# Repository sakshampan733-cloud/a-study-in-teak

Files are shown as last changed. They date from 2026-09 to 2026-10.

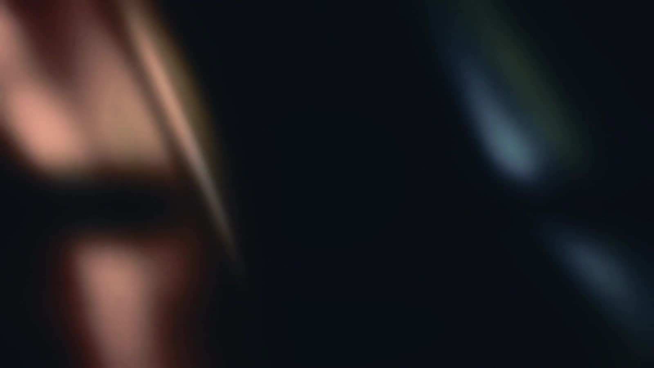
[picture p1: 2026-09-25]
v2/media/hero-poster.jpg

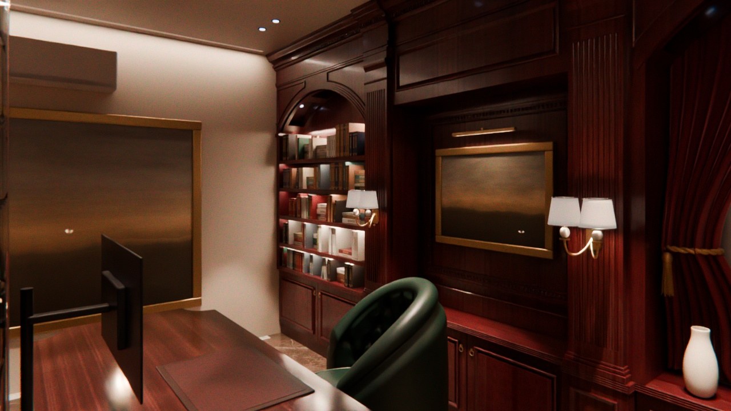
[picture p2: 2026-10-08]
v2/media/room-film-poster.jpg

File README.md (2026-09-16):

# A Study in Teak

Working brief for the interior of one room — neoclassical, late-1940s British, in teak.
A static website: open `index.html`, or serve the folder and browse by section.

```bash
python3 -m http.server 4178
```

## What's where

| Path | What it holds |
|---|---|
| `data.js` | All written content: materials, each piece of furniture, doors, lighting and switch plan |
| `drawings/` | Parametric drawing sheets (desk, door) and the hidden-line 3D renderer — change the numbers at the top of a file and every view redraws |
| `cad/` | Editable CAD exports: `*-model.dxf` true size in mm, `*-sheet.dxf` the A3 sheet, `*.svg` |
| `assets/refs/` | Reference photos |
| `tools/` | Scripts that rebuild the CAD files |

## Adding your own CAD drawings

Drop `.dxf`, `.pdf` or image files into `plans/`, then run `tools/build-cad.sh`. They appear on the Overview page.
DWG can't be read directly — in AutoCAD use **Save As → DXF**, or **Export / Plot → PDF**.

## Rebuilding the CAD files

After changing a drawing:

```bash
python3 -m venv tools/.venv && tools/.venv/bin/pip install ezdxf svgelements shapely pymupdf   # first time only
tools/build-cad.sh
```

Status: rough work. Sizes and details are finalised with the family before anything is made.

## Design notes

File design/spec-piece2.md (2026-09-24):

# Piece 2 — navigation and motion, read from the reference's code

Source: `design/ref-ciridae/site/` (index.html CSS, `marketingMotionRuntime-*.js`, `useMarketingRouteHead-*.js`,
`MarketingShell-*.js`). Easing everywhere: `--smooth: cubic-bezier(.76, 0, .24, 1)`.

## Smooth scroll
- `new Lenis({ duration: 1.4, smoothWheel: true, wheelMultiplier: 1.6 })`, wired to `ScrollTrigger.update`.
- Stopped while the menu is open (`body.burger-open`), restarted on close.

## Nav bar (`.nav_body`)
- Grid of two columns, padding 8 × 24, 4 px radius.
- Frosted: `background: color-mix(in srgb, currentColor, transparent 75%)` (white 25%) + `backdrop-filter: blur(20px)`.
- Desktop (≥ 992 px): **at the top** it is transparent with no blur. **Scrolling down** it slides away
  (`translateY(-140%)`). **Scrolling up** it returns, frosted. Transform 0.8 s smooth; colour/bg/blur 0.4 s.
- Phone/tablet: frosted even at the top.
- Over light (Bone) sections the nav turns black (`.is--dark`).

## Pills (`.btn`, `.nav_burger`)
- 1 px border, full radius, min-width 140, padding 10 × 18, label shifted `translateY(7%)`.
- **Hover is a glow, not a fill:** a `::before` with `outline: 3px solid`, `box-shadow: 0 0 20px 10px, inset 0 0 20px 10px`
  (currentColor) fading to opacity 0.12 over 0.2 s.
- Labels re-scramble on hover, lowercase `abcdefghijklmnopqrstuvwxyz`.

## Menu (`.burger`)
- Full-screen fixed overlay, `#272a2a`, z 9. Opens: opacity 0→1 over 0.8 s smooth; closes over 0.6 s.
- Content: small mark at top, links centred in a column (40 px, weight 400, line-height 1, gap 10 px),
  a footer row at the bottom (three columns).
- Links fade in 0.6 s each, staggered `delay = 0.2 s + i × 0.1 s`; the footer row fades in at 0.4 s.
- Hovering a link: the others dim to 70%; the hovered one gets a blurred (10 px) ghost copy at 30%.
- Burger button: `MENU` swaps to `CLOSE`; the two 25 px lines rotate ±45° and shrink to 50% width
  (0.6 s smooth); the button's border fades out; the left pill fades and disables.
- Escape closes; focus moves to the first link on open and back to the button on close.

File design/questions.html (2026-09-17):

# A Study in Teak — questions to fill in

One room: study, bedroom, dressing, bathroom. Tick one box per question unless it says otherwise; write in the blanks where asked. Anything already decided is marked [set] so it can be checked rather than chosen.

## 1 · The room itself

1.1 Room size, wall to wall — please measure

- Width ft Length ft Ceiling height ft

1.2 Study wall (bookcase wall) width

- 16 ft (as drawn)
- Other:

1.3 Right wall — study wall to the bathroom door opening

- 14 ft 6 in (as drawn)
- Other:

Also: wall past the door to the corner = 2 ft? ☐ yes ☐ other

1.4 Where exactly is the main door (D1) on the left wall?

- Distance from the bed-end corner:
- It is on the entrance wall, not the left wall

1.5 Study window — size and position

- Width Height Sill from floor From right corner

## 2 · Materials

2.1 Veneer — the one veneer used across the room

- Dark reddish teak, straight grain
- Walnut, straight grain
- Dark oak
- Other:

2.2 Veneer cut

- Quarter cut / straight
- Crown cut
- Book-matched
- Slip-matched

2.3 Polish on panelling, doors and trim

- Satin PU
- Semi-gloss PU
- Matte PU
- Melamine

2.4 Polish on the desk

- Matte PU
- Oil / wax finish
- Same as panelling
- Other:

2.5 Wall paint — warm cream [set]. Which shade?

- Warm cream
- Soft ivory
- Warm off-white
- Sample to be chosen on site

2.6 Brass / gold finish on handles

- Polished brass
- Antique / aged brass
- Brushed brass
- Other:

## 3 · Study — desk, shelf wall, curtains

3.1 Desk size 7 ft 6 in × 3 ft, height 750 mm [set] — confirm?

- Yes, as drawn
- Change:

3.2 Desk pedestals

- Drawers both sides
- Doors both sides
- Drawers one side, door the other
- Decide later

3.3 Shelf unit depth 11 in (280 mm) [set] — confirm?

- Yes
- Other:

3.4 Cupboards under the shelf: 2 ft high [set], doors

- Two doors per bay, as drawn
- Drawers instead
- Mix — say which:
- Decide later

3.5 Painting in the centre panel

- Yes, leave the panel for a painting
- No painting — panel stays plain
- Mirror instead
- Decide later

3.6 Curtain heading and track

- Ceiling track, recessed
- Ceiling track, surface
- Rod with brackets
- Decide later

3.7 Curtain length

- Just touching the floor
- Breaking / pooling on the floor
- Sill length
- Other:

## 4 · Left and right walls

4.1 Right wall — option C [set]: 5 panels, lamps in 1, 3 and 5. Confirm?

- Yes
- Change lamps to:

4.2 Right wall lamps — how many

- Three (as drawn)
- Two
- None
- Other:

4.3 Left wall treatment

- Same panel moulding as the right wall
- Teak panelling to the door head
- Plain painted wall
- Other / undecided:

## 5 · Bedroom

5.1 Bed wall in parchment [set] — how is it made?

- Large panels with hairline joints
- Seamless (no joints)
- Real parchment / vellum
- Parchment-effect finish

5.2 How far does the parchment go?

- Whole wall, floor to ceiling
- Behind the bed only
- Wall plus a return
- Other:

5.3 Bed size

- King
- Queen
- 6 ft 6 in × 6 ft 6 in
- Other:

5.4 Bed base / frame

- Teak
- Wrapped in leather
- Fabric upholstered
- Decide later

5.5 Storage in the bed

- Hydraulic lift-up
- Drawers
- None
- Decide later

5.6 Bedside

- Wide wooden ledges, built in
- Free-standing tables
- Drawers built into the bed back
- Decide later

5.7 TV — where does it go?

- On the partition, facing the bed
- On a wall — which:
- No TV
- Decide later

5.8 TV unit / side drawers

- Drawer unit under the TV
- Side drawers only
- Both
- Decide later

5.9 TV screen size

- 55 in
- 65 in
- 75 in
- Other:

## 6 · Partition

6.1 Length and gaps — please measure so they add up to the room width

- Partition ft Gap one end ft Gap other end ft

6.2 Material — wood only [set]. How is it built?

- Teak veneer both sides
- Veneer one side, parchment the other
- Veneer with parchment drawer fronts
- Other:

6.3 How much moulding?

- A little — slim panel frames
- Full panelling, like the study wall
- Plain, no moulding
- Decide later

6.4 Base where it meets the floor

- Teak plinth
- Shadow gap, wood runs to the floor
- Marble skirting to match the walls
- Decide later

6.5 Does it hold anything?

- Drawers on the bed side
- Shelves on the study side
- Both
- Nothing — it is a screen

## 7 · Dressing

7.1 Wardrobe fronts

- Blackened steel frames with lit white glass (as drawn)
- Teak veneer
- Parchment
- Decide later

7.2 Wardrobe wall — which wall, and how wide?

- Wall: Width Depth (600 mm standard)

7.3 Inside the wardrobe

- Mostly hanging
- Half hanging, half drawers
- Mostly drawers and shelves
- Decide later

7.4 Dressing mirror

- Free-standing three-panel screen (as the reference)
- Fixed to a wall
- Inside a wardrobe door
- Decide later

7.5 Dressing ceiling

- Barrel vault, as the bedroom
- Flat with cove
- Flat, plain
- Decide later

## 8 · Bathroom

8.1 Size — please measure

- Width Length Ceiling height

8.2 Painted ceiling linework [set] — the pattern

- Copy the reference photo
- Design a new motif
- Simple border only
- Decide later

8.3 Vanity

- Teak veneer, moisture-resistant core
- Stone / solid surface
- Painted
- Decide later

8.4 Vanity counter

- Beige-gold marble, same as the floor
- A contrasting stone:
- Solid surface
- Decide later

8.5 Basin and tap

- Counter-top basin
- Under-counter basin
- Wall-mounted tap
- Deck-mounted tap

## 9 · Doors and hardware

9.1 Three doors, one design [set] — leaf thickness

- 35 mm
- 45 mm
- Other:
- Decide later

9.2 The panel detail (shaped bead, corner roundels)

- Carved into the solid
- Applied moulding
- Simplified — plain panels
- Decide later

9.3 Door hardware

- Knobs
- Lever handles
- Brass
- Antique brass

9.4 Which way does each door swing? (D1 main, D2 and D3)

- D1 D2 D3

## 10 · Lighting and services

10.1 Bulb colour through the room

- 2700 K warm
- 3000 K
- 4000 K natural white (as bought)
- Mixed — say where:

10.2 Cove lights — all on one dimmer [set]. Confirm?

- Yes
- Change:

10.3 Reading lights at the bed

- Recessed slots in the wall
- Wall lamps
- Table lamps
- Decide later

10.4 Where do the switch boards go?

- List the locations:

10.5 Sockets needed at the desk, bed and TV

- Desk Bed TV

10.6 Air conditioning — position and type

- Wall split — where:
- Cassette in the ceiling
- Ducted
- Already installed

Anything unclear or wrongly assumed — write it in the margin. Sizes matter most: the room, the right wall, the partition and the bathroom.

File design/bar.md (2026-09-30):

# Bar — ciridae.com, to the pixel, for A Study in Teak

Gold standard, saved locally: `design/ref-ciridae/site/` (every file the browser loads, incl. the hero
video), `ciridae.mhtml`, `full-page.png`, section frames, and the first-load recorded at 33 fps
(`load-ciridae/load.mp4`). Numbers below are read from their source (`_site-*.js`, the motion runtime)
and measured off the live page at 1440 × 900. Every line is checkable on a render or a filmstrip.
Last round's bar is kept as `bar-round1.md`.

1. **The entrance, to the millisecond.** Black `#0b0b0b` and nothing else for the first 225 ms. The mark
   fades 0→1 over 0.75 s from 0.225 s while its blur runs 20 px→0 over 1.65 s, so it is fully sharp at
   ~1.9 s. The five hero texts (wordmark, two edge labels, the CTA's lines) scramble in A–Z letter by
   letter — 0.3 s per character, 7.5 ms stagger, left→right, fading in as they resolve — the first 0.2 s
   after the mark starts, each next 0.1 s later. The background video starts at 1.875 s; a curtain
   lifts over 0.6 s (power1) and the nav fades in with it. Entrance complete ≈ 3.2 s.
   *Filmstrip check:* 300 ms black · 900 ms a soft blurred mark · 1.9 s sharp mark, text resolving ·
   3.2 s video full-bleed, nav present.

2. **Void, one flip.** Page `#0b0b0b`; panels `#272a2a` at 10 px radius; exactly one Bone `#edebe7`
   full-width band per page. No box-shadow, glow or gradient fill anywhere — the only softening is
   backdrop blur: 40–50 px on the footer, a frosted veil on the stacked cards.

3. **Three registers, one weight.** Everything is weight 400. Headlines: condensed uppercase, 32 px,
   line-height 1.05, −0.02 em. Hero labels and CTA: grotesk uppercase 16 px, −0.02 em. Eyebrows, nav and
   data: mono uppercase 14 px, −0.02 em; card numbers mono 11 px. Prose: grotesk 14 px / 1.4, sentence
   case, ≤ 50 ch. Nothing larger than 32 px except the hero wordmark.

4. **Nav is two labels in outlines.** Fixed, text baseline ~31 px from the top, 67 px in from each edge:
   left action, right `MENU`, 14 px mono uppercase inside 1 px pill outlines, transparent fill. `MENU`
   opens a full-screen `#272a2a` overlay with the links in large condensed uppercase, centred.

5. **Moving media, never a static hero.** The hero is a full-bleed looping video: heavily defocused,
   warm-against-cool light, no hard edge and no recognisable object, ~8 s, seamless. Mark + wordmark
   dead centre; two 16 px labels pinned to the far left and far right at the vertical centre; a
   three-line CTA centred ~120 px above the bottom. Section imagery is dark and atmospheric — never a
   thumbnail grid.

6. **Text decodes, sections rise, scroll glides.** Every eyebrow and headline scrambles into place as it
   enters view (0.3 s per character, 10–20 ms stagger, left→right). Section media: content yPercent
   50→0 (expo.in), image scale 1.4→1 with yPercent −20→0 (power1). Default tween 0.4 s power2. Scroll
   is inertial (lerp-smoothed), never native-jumpy.

7. **The set pieces.** One scroll-pinned full-bleed backdrop with numbered frosted cards rising and
   stacking over it; one row of cards where the hovered card grows to ~2× width over 0.6 s; one Bone
   band with a logo/marquee strip; a footer under 40–50 px backdrop blur.

## Piece 1, round 15 on — the hero loop by the numbers (30.09)

The owner restarted the frozen loop against the **saved 23 Sep version** (the live site has since been
redesigned; it is not the bar). Entrance timing and layout passed brief and system in rounds 8–12 and
are regression checks only. What failed every craft round is the loop's *feel*. These are measured off
`site/ciridae.com/marketing/media/hero_web.mp4` (1 fps, 480 px wide) and are checkable on ours the same way:

8. **Mostly dark.** 60–72% of the frame below luma 20; mean luma 20–28. Lit area small: warm (r > b) 4–8%
   of the frame, cool (b > r) 3–6%. Shadows near-neutral, faintly blue (≈ 7, 11, 14). No green cast (0%).
9. **Mixed focus, not one blur.** In every second at least one form is only softly defocused — a curved
   edge readable as glass or metal, a surface you could name the shape of — in front of forms that are
   fully dissolved. Edge density (gradient > 18) varies 0.3–1.0% second to second; a flat 0.4% is fog.
10. **Glints.** At least once per loop a small near-white specular (luma > 225, 0.1–0.6% of the frame,
    cream not pure white) catches on a curved surface, then passes. Never a disc, never a light bulb.
11. **Forms, not shapes.** The light sits on 3–5 translucent objects — cylinders, shards, lips of glass —
    lit copper from one side and steel-blue from the other, turning slowly so their highlights travel.
    No ring or arc spanning half the frame; nothing reads as a bubble, orb, lamp, room or face.
12. **Pace and loop.** 8–9 s, 24 fps, 1600 × 850. Composition changes by 10–16 luma levels a second
    (forms enter, cross, leave), with the loop point invisible: no jump, no crossfade ghost.

## Accepted deltas — a critic must not fail on these

- **Content is ours.** Room names, copy, drawings, photos: from `data.js`, never theirs.
- **Media is ours.** Every video and image is generated for this room (Higgsfield). Match their
  *treatment* — blur level, grade, pacing, motion — never their pixels. The objects in ours may be the
  room's own (teak, brass, glass) as long as they read as abstract forms, per 11.
- **Typefaces**, until decided: Pragmatica / Pragmatica Cond are licensed commercial faces. Until the
  owner buys them, the closest free substitutes stand in; judge metrics (size, tracking, case, weight),
  not letterforms.

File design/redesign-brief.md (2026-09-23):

# Redesign brief — Ciridae, to the last pixel

Gathered 23.09.2026, ahead of the redesign. Everything we have, and what's still missing.

## The reference

- **Site:** https://www.ciridae.com — "Ciridae — AI Transformation"
- **Refero style extract:** https://styles.refero.design/style/a1b78a21-a304-482b-8ce5-f612d95d44fe
- **Your source files** (still in ~/Downloads, copies here in `design/`):
  `DESIGN-4.md` → `design-system.md`, `tokens-4.json` → `tokens.json`,
  `variables-4.css` → `variables.css`, `theme-4.css`
- **The bar** the first pass was judged against: `design/bar.md` (7 checkable rules)
- **Fresh captures of the live site:** `design/ref-ciridae/` — 49 frames at 1440 × 900,
  recorded in Chrome with the video playing (kept on this Mac, not in git)

## Where the first pass stopped (17.09)

Design loop, 4 rounds, paused. Brief checks passed for navigation and room pages;
system and craft critics still failing on every piece (`design/progress.js`).
What shipped: void palette, condensed type, ghost pills, rust accent, blur-in loader,
decode headings, card-stack, expanding row, menu overlay. What was substituted:
**every moving image was replaced by a blurred still**, because we had nothing to make video with.

## The page, section by section (live, 23.09)

| # | Section | What moves | What we need |
|---|---|---|---|
| 0 | Hero — mark + wordmark, two edge labels, CTA line | **Background video** `hero_web.mp4`, 1600 × 850, 8.3 s loop, muted: slow, heavily defocused shapes in warm copper and cold blue-grey | **Higgsfield:** an 8 s seamless loop of the room — teak, brass sconce glow, lamplight — out of focus, drifting |
| — | Loader (0–2.6 s) | Mark + wordmark blur into focus on black (~0.9 s); edge labels decode letter by letter; video fades up behind by ~2.6 s | Code — already built, retune timings |
| 1 | "Backed by" — light Bone strip, three logos | Static | Code |
| 2 | "AI transformation" headline over a **WebGL2 canvas** | The mark rendered as chrome stars with a soft glow and a mirrored reflection below; slow shimmer | **Code (WebGL)** or a **Higgsfield** render of our mark in brass |
| 3 | Pinned full-bleed night landscape (mountain lake, star field, shooting star) with three frosted cards rising and stacking over it, each with its own star-constellation glyph | Scroll-pinned stack; glyphs | **Higgsfield:** one atmospheric backdrop of ours, same mood. Glyphs are code |
| 4 | "A new era" — centred prose on black | Decode on enter | Code |
| 5 | "Systems, not tools" — expanding card row, 4 cards | Hovered card grows to ~2× over 0.6 s | **Higgsfield:** four rich macro textures in their style (theirs: marbled fluid, dark forest, cloud, copper). Ours: teak grain, veined marble, leaded glass, brass |
| 6 | "Our team" — light Bone section, logo marquee | Marquee scroll | Code |
| 7 | Testimonials — charcoal cards, 1 / 6 carousel | Slide | Code |
| — | Menu | Full-screen charcoal overlay; links decode in | Code — built |

## The Higgsfield shopping list

1. **Hero loop** — 8 s, seamless, 16:9 or wider, generated from our own reference photos, then defocused.
2. **Pinned backdrop** — one still or slow video: the room's mood at night.
3. **Four textures** for the expanding row.
4. *(optional)* **The mark in brass** — if we render it rather than build it in WebGL.

Everything else is code and doesn't need credits.

## Still open before we start

- Which of our pages map onto which Ciridae sections (the overview is the obvious home page).
- The fonts: Ciridae's are paid; we used Barlow Condensed / Inter / Roboto Mono. Buy the real ones, or keep the substitutes?

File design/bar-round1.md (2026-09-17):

# Bar — Ciridae (ciridae.com), recreated for A Study in Teak

Reference: https://www.ciridae.com · Refero extract: design/design-system.md
Every line is checkable by looking at a render (screenshot or filmstrip).

1. **Void, one flip.** Canvas is #0b0b0b; cards/panels #272a2a with 10px radius; exactly one Bone (#edebe7) full-width section per page; no box-shadow, glow or gradient fill anywhere.
2. **Three registers, one weight.** Labels and headlines are condensed UPPERCASE at 14 / 20 / 32px (weight 400, −0.02em); prose is a grotesk at 15–24px sentence case; monospace 11–14px UPPERCASE appears only for system data (dates, codes, sizes, statuses, the top ticker). Nothing is heavier than 400.
3. **Ghost pills and one ember.** Every control is transparent with a 1px border and full pill radius; numbered markers are "01"-style mono pills with a #cecece border. Ember #cc6437 appears as hairline or small text only — never a fill — at most twice per viewport.
4. **Centred eyebrow → headline.** Each section opens with a centred 14px eyebrow above a 32px headline, with ≥80px vertical space between sections; content is centred inside a 1400px max width.
5. **Ambient imagery.** The hero is a full-viewport, heavily blurred photo (≥40px blur) with a centred mark + wordmark and two 14px labels pinned to the far left and far right edges; section/card photos are dark and atmospheric behind centred type, never illustrative thumbnails in a grid.
6. **Motion vocabulary.** Load begins with the mark blurring into focus on black; labels and headlines decode (random characters resolving left→right in ~600ms) as they enter view; all transitions use cubic-bezier(0.76, 0, 0.24, 1) at 400–800ms; a card row expands the hovered card to ~2× width over 600ms.
7. **Stacks and overlays.** At least one scroll section pins a full-bleed image while numbered cards stack over it; navigation is two fixed ghost pills (left action, right MENU) and MENU opens a full-screen #272a2a overlay with large condensed links.

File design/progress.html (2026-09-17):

# A Study in Teak × Ciridae — design loop

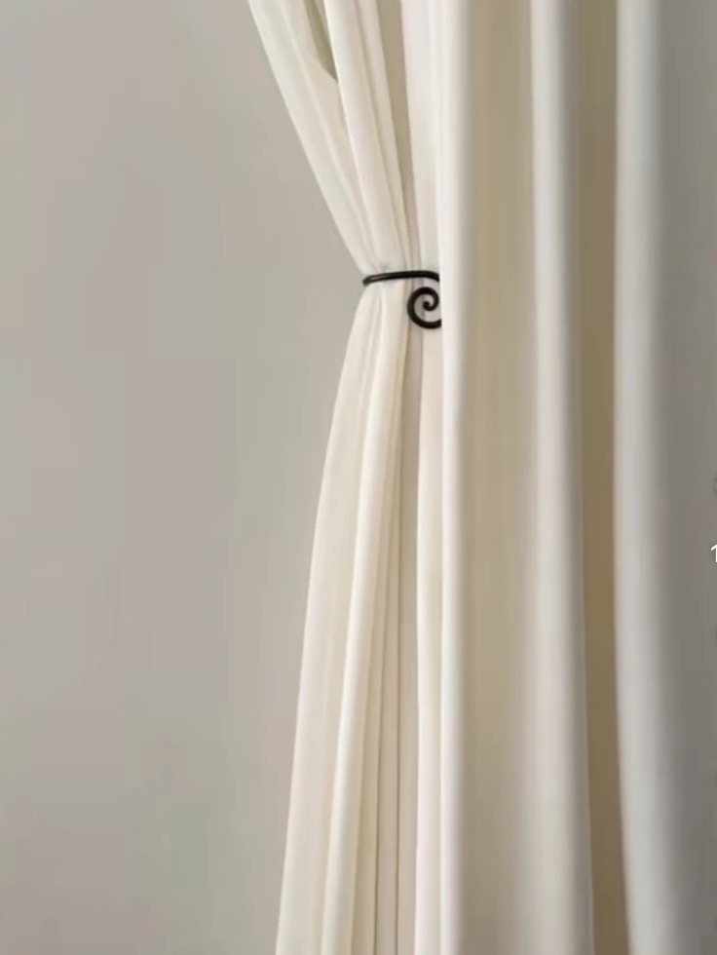
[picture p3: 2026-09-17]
assets/refs/curtain-ref-1-volute-tieback.jpg

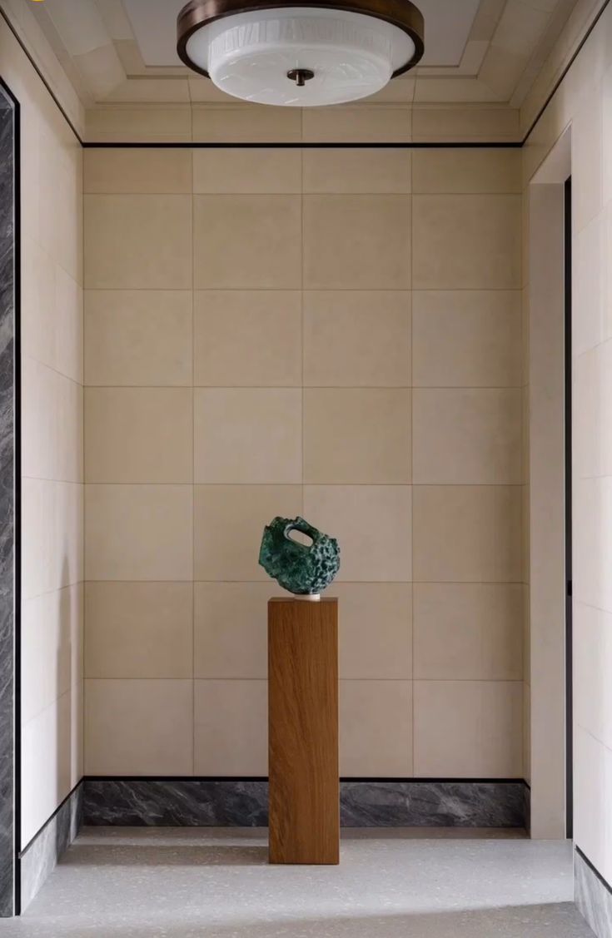
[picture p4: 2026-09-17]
assets/refs/bedwall-ref-2-parchment-entry-niche.jpg

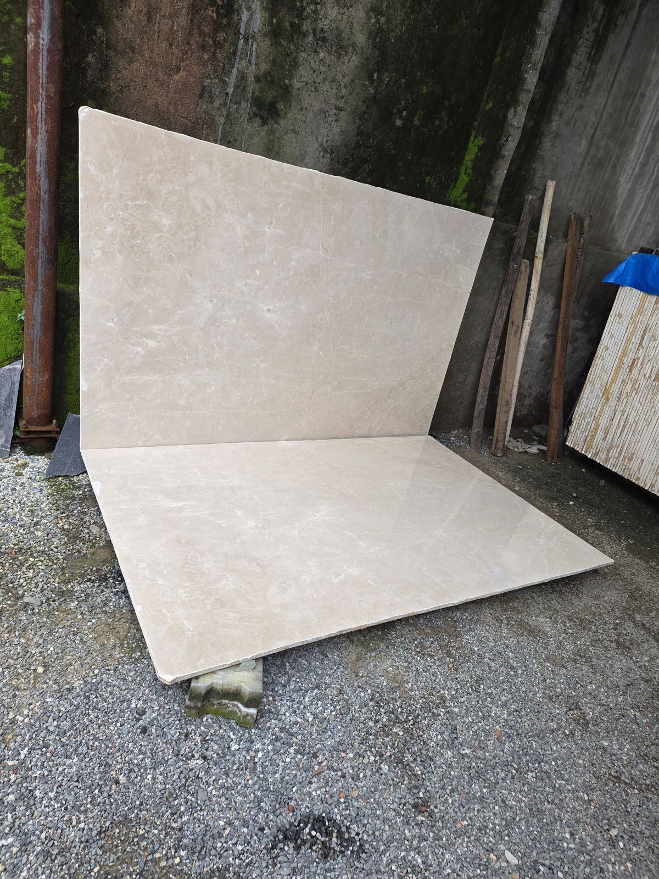
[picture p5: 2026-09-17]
assets/refs/stone-ref-3-beige-gold-bathroom-marble.jpg

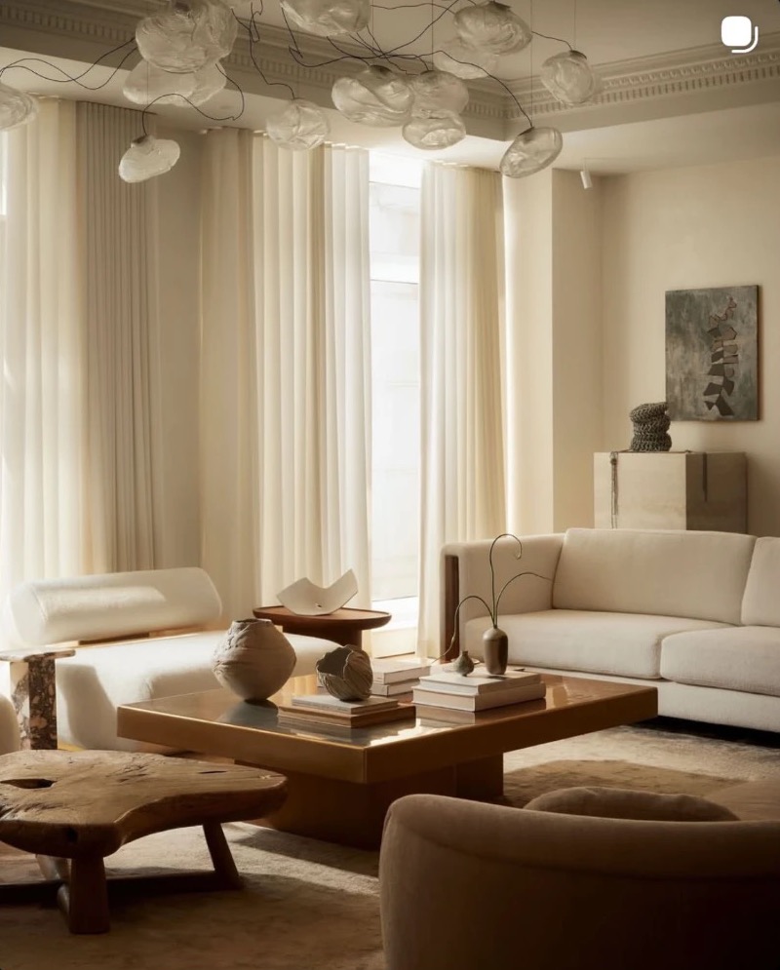
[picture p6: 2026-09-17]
assets/refs/paint-ref-1-warm-cream-room-sheer-curtains.jpg

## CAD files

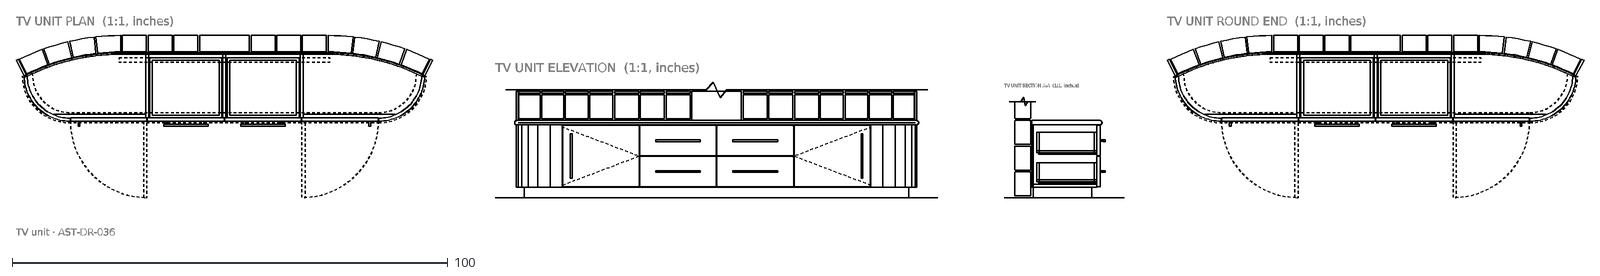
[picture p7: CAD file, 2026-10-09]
cad/tvunit-model.dxf
TV UNIT PLAN (1:1, inches)
TV UNIT ELEVATION (1:1, inches)
TV UNIT SECTION A-A (1:1, inches)
TV UNIT ROUND END (1:1, inches)
TV unit · AST-DR-036

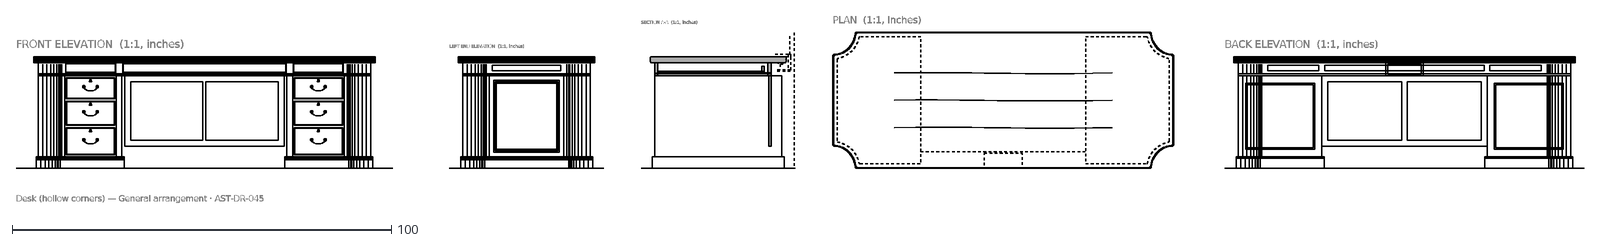
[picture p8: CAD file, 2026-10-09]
cad/desk-curved-model.dxf
FRONT ELEVATION (1:1, inches)
LEFT END ELEVATION (1:1, inches)
SECTION A-A (1:1, inches)
PLAN (1:1, inches)
BACK ELEVATION (1:1, inches)
Desk (hollow corners) — General arrangement · AST-DR-045

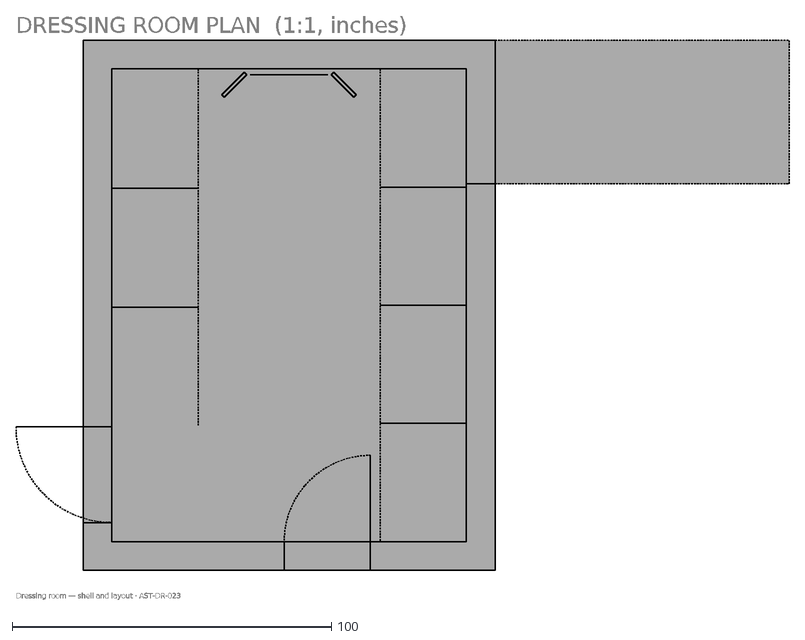
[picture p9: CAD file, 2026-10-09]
cad/dressingshell-model.dxf
DRESSING ROOM PLAN (1:1, inches)
Dressing room — shell and layout · AST-DR-023

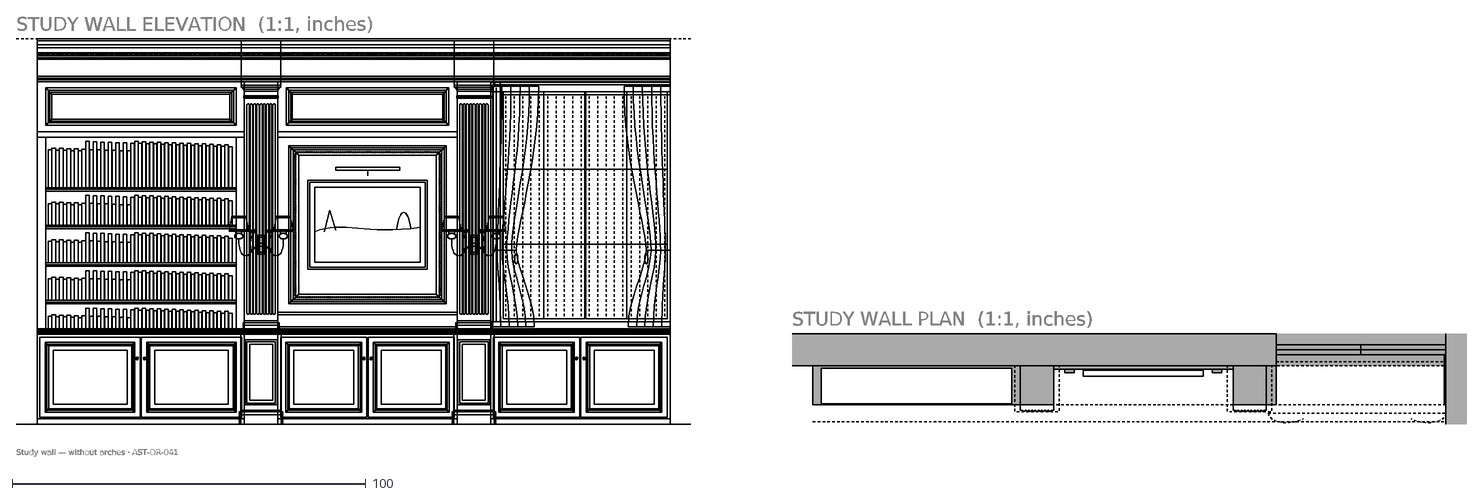
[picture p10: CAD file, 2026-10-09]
cad/studywall-flat-model.dxf
STUDY WALL ELEVATION (1:1, inches)
STUDY WALL PLAN (1:1, inches)
Study wall — without arches · AST-DR-041

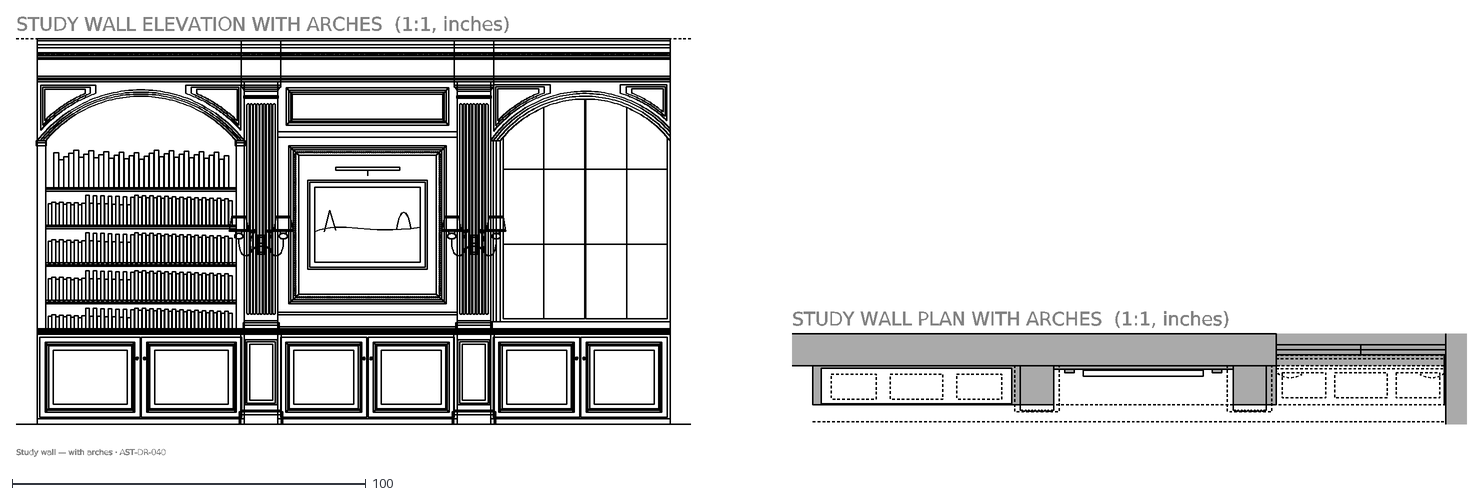
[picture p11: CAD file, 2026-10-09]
cad/studywall-arch-model.dxf
STUDY WALL ELEVATION WITH ARCHES (1:1, inches)
STUDY WALL PLAN WITH ARCHES (1:1, inches)
Study wall — with arches · AST-DR-040

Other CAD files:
cad/studywall-flat-sections-model.dxf
cad/studywall-details-sheet.dxf
cad/desk-curved-sheet.dxf
cad/roomshell-sheet.dxf
cad/sharedwall-sheet.dxf
cad/doorveneer-model.dxf
cad/desk-sheet.dxf
cad/sidetable-sheet.dxf
cad/vanity-c-sheet.dxf
cad/door-model.dxf
cad/doorveneer-sheet.dxf
cad/foldslide-sheet.dxf
cad/desk-square-3d-sheet.dxf
cad/architrave-model.dxf
cad/architrave-sheet.dxf
cad/bathroom-model.dxf
cad/bathroom-sheet.dxf
cad/bed-model.dxf
cad/bed-sheet.dxf
cad/bedframe-model.dxf
cad/bedframe-sheet.dxf
cad/bedwall-model.dxf
cad/bedwall-sheet.dxf
cad/casingb-model.dxf
cad/casingb-sheet.dxf
cad/desk-3d-sheet.dxf
cad/desk-curved-3d-sheet.dxf
cad/desk-curved-details-model.dxf
cad/desk-curved-details-sheet.dxf
cad/desk-details-model.dxf
cad/desk-details-sheet.dxf
cad/desk-model.dxf
cad/desk-plain-3d-sheet.dxf
cad/desk-plain-details-model.dxf
cad/desk-plain-details-sheet.dxf
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

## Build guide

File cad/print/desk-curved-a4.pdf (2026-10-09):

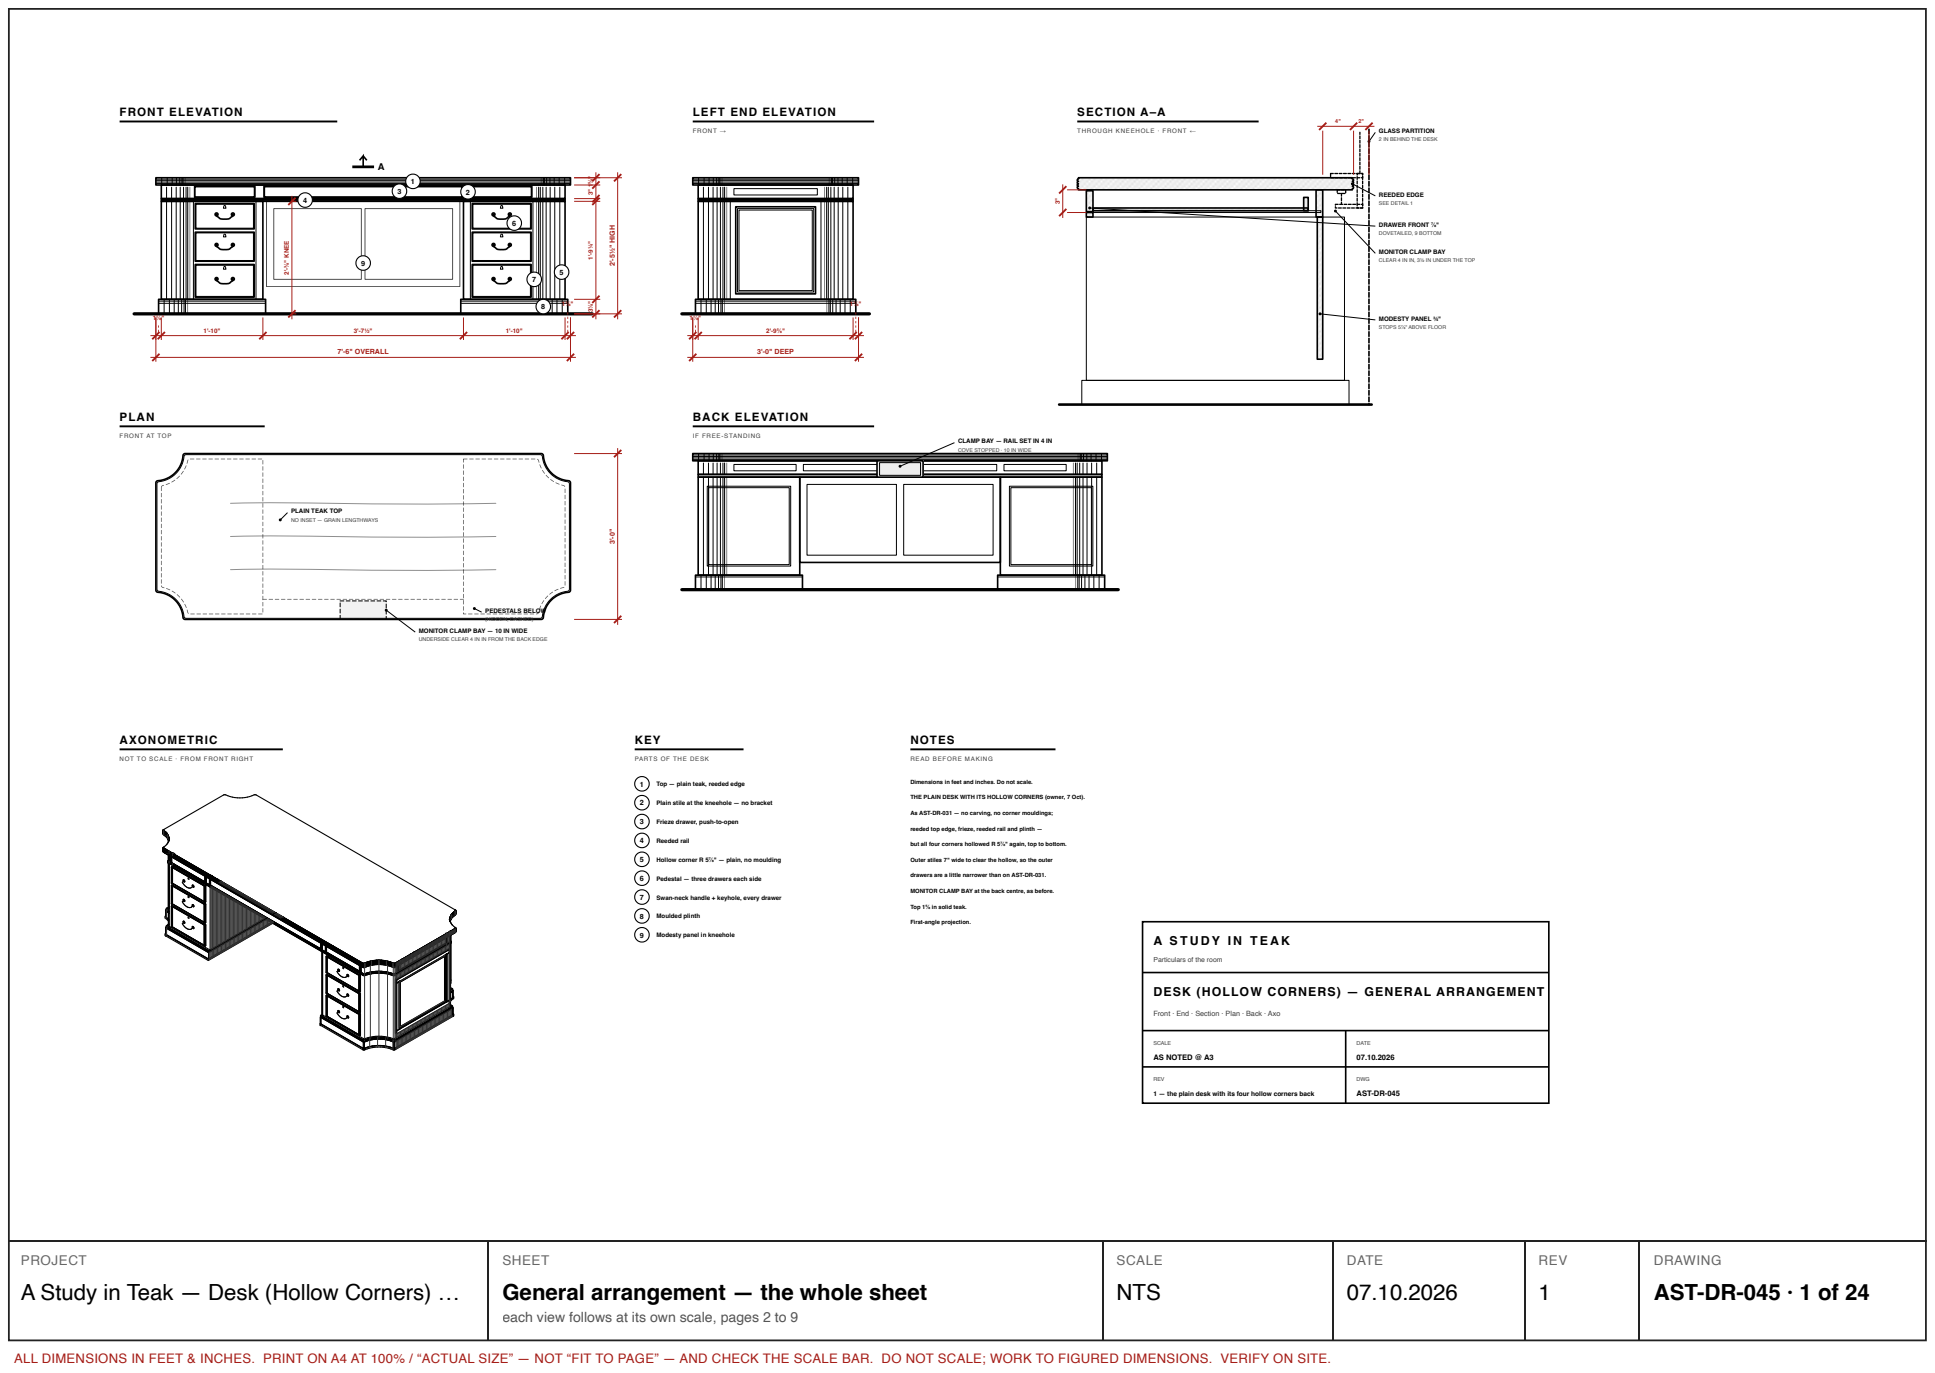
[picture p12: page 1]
FRONT ELEVATION; 7'-6" OVERALL; 2'-5½" HIGH; 2'-⅜" KNEE; FRONT →; 3'-0" DEEP; SECTION A–A; DRAWER FRONT ⅞"; DOVETAILED, 9 BOTTOM; GLASS PARTITION; REEDED EDGE; SEE DETAIL 1; PLAN; PEDESTALS BELOW; (HIDDEN, DASHED); BACK ELEVATION; AXONOMETRIC; KEY; 4 Reeded rail; 8 Moulded plinth; NOTES; SCALE; AS NOTED @ A3; DATE; REV; DWG; AST-DR-045; SCALE NTS; DATE 07.10.2026

LEFT END ELEVATION

THROUGH KNEEHOLE · FRONT ←

2 IN BEHIND THE DESK

MONITOR CLAMP BAY

CLEAR 4 IN IN, 3½ IN UNDER THE TOP

MODESTY PANEL ¾"
STOPS 5⅞" ABOVE FLOOR

FRONT AT TOP

IF FREE-STANDING

CLAMP BAY — RAIL SET IN 4 IN

COVE STOPPED · 10 IN WIDE

PLAIN TEAK TOP
NO INSET — GRAIN LENGTHWAYS

MONITOR CLAMP BAY — 10 IN WIDE

UNDERSIDE CLEAR 4 IN IN FROM THE BACK EDGE

NOT TO SCALE · FROM FRONT RIGHT

PARTS OF THE DESK

READ BEFORE MAKING

1 Top — plain teak, reeded edge

Dimensions in feet and inches. Do not scale.

2 Plain stile at the kneehole — no bracket

THE PLAIN DESK WITH ITS HOLLOW CORNERS (owner, 7 Oct).

As AST-DR-031 — no carving, no corner mouldings;

3 Frieze drawer, push-to-open

reeded top edge, frieze, reeded rail and plinth —

but all four corners hollowed R 5⅞" again, top to bottom.

5 Hollow corner R 5⅞" — plain, no moulding

Outer stiles 7" wide to clear the hollow, so the outer

6 Pedestal — three drawers each side

drawers are a little narrower than on AST-DR-031.

MONITOR CLAMP BAY at the back centre, as before.

7 Swan-neck handle + keyhole, every drawer

Top 1⅝ in solid teak.

First-angle projection.

9 Modesty panel in kneehole

Particulars of the room

DESK (HOLLOW CORNERS) — GENERAL ARRANGEMENT

Front · End · Section · Plan · Back · Axo

1 — the plain desk with its four hollow corners back

PROJECT
A Study in Teak — Desk (Hollow Corners) …

SHEET
General arrangement — the whole sheet

DRAWING
AST-DR-045 · 1 of 24

each view follows at its own scale, pages 2 to 9

ALL DIMENSIONS IN FEET & INCHES. PRINT ON A4 AT 100% / “ACTUAL SIZE” — NOT “FIT TO PAGE” — AND CHECK THE SCALE BAR. DO NOT SCALE; WORK TO FIGURED DIMENSIONS. VERIFY ON SITE.

# FRONT ELEVATION

A

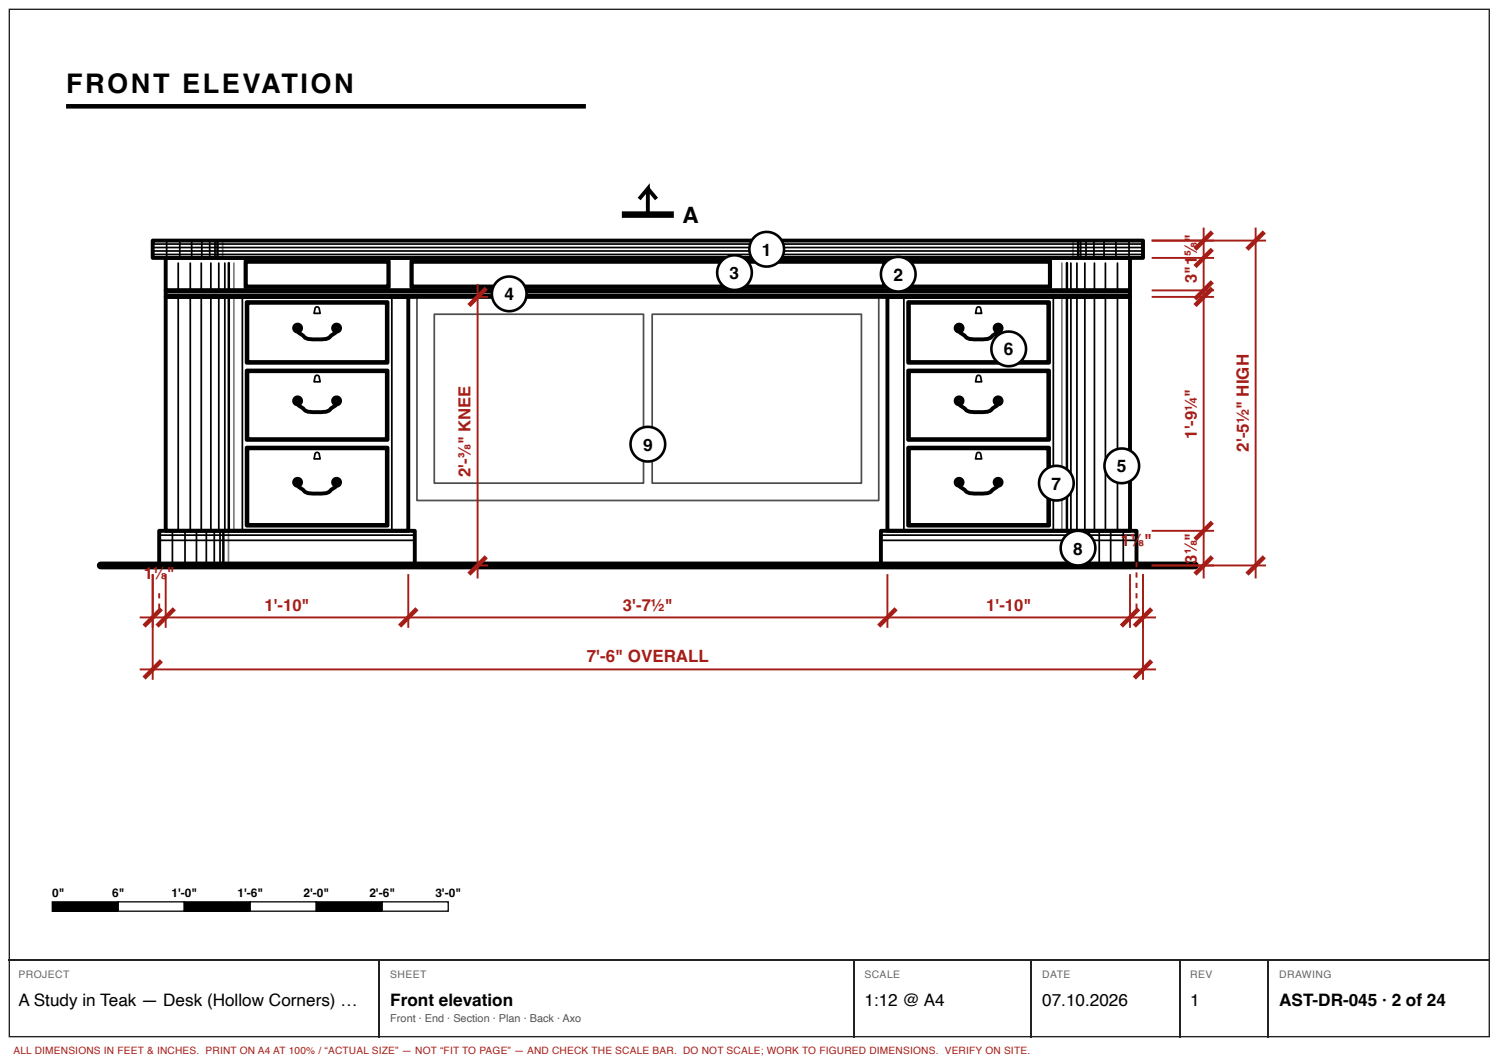
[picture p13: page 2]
7'-6" OVERALL; ½" HIG; Front elevation

AST-DR-045 · 2 of 24

Front · End · Section · Plan · Back · Axo

# LEFT END ELEVATION

# SCALE 1:10 @ A4 · FRONT →

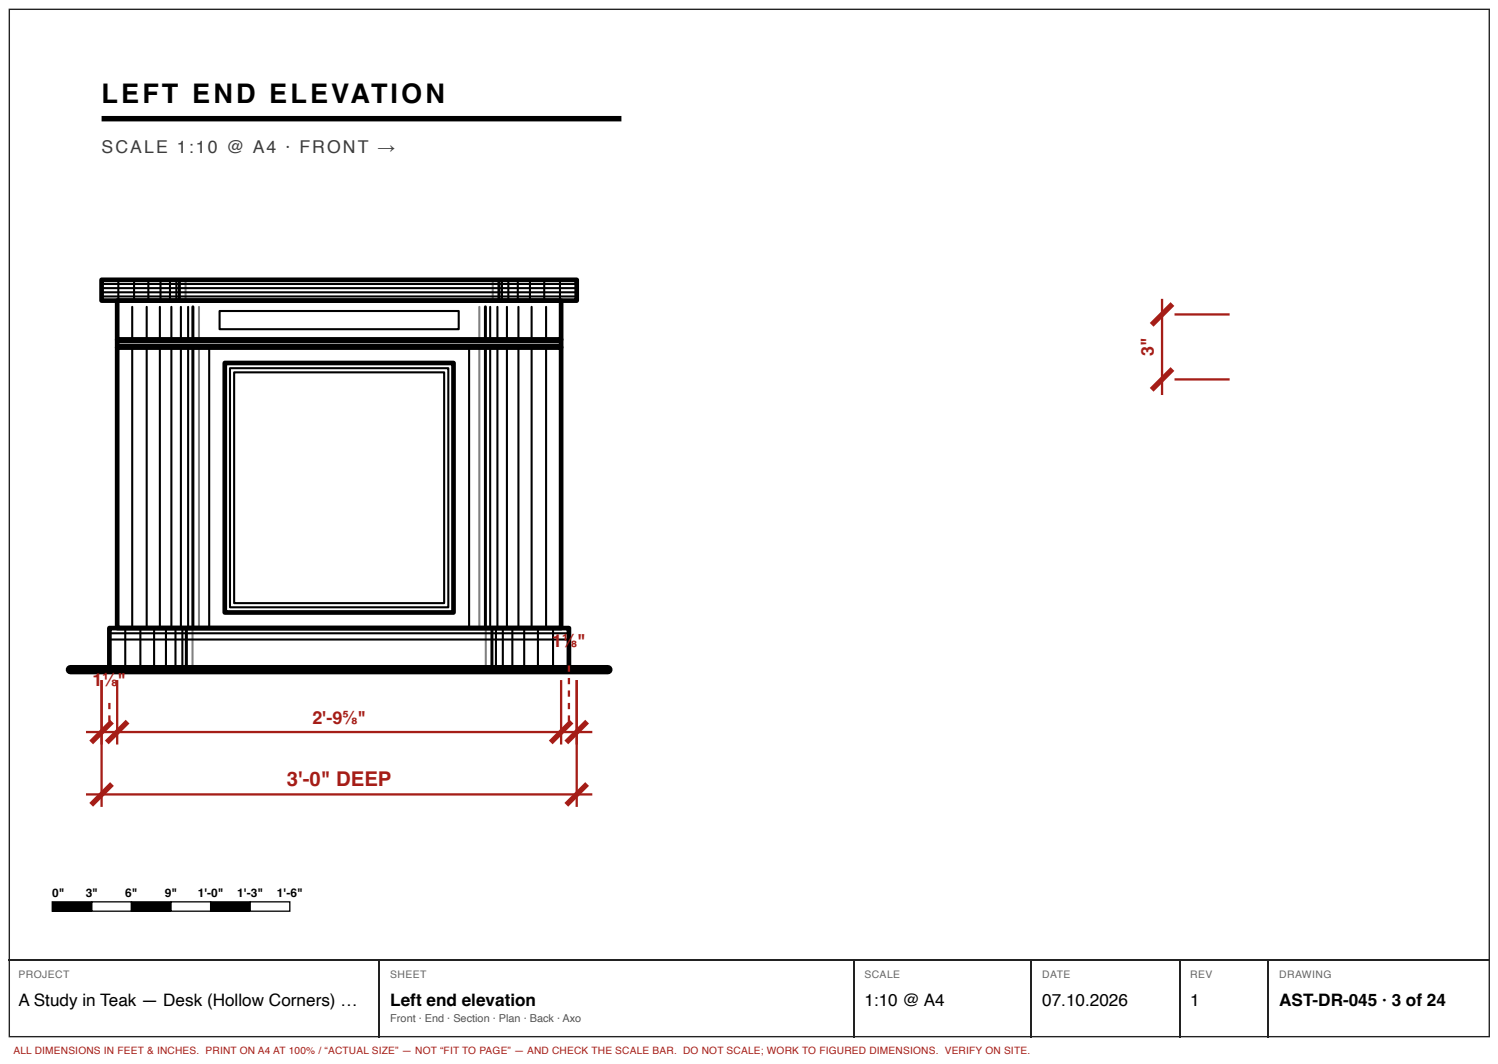
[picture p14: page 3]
3'-0" DEEP

Left end elevation

AST-DR-045 · 3 of 24

Front · End · Section · Plan · Back · Axo

# SECTION A–A

### SCALE 1:8 (1½" = 1'-0") @ A4 · THROUGH KNEEHOLE · FRONT ←

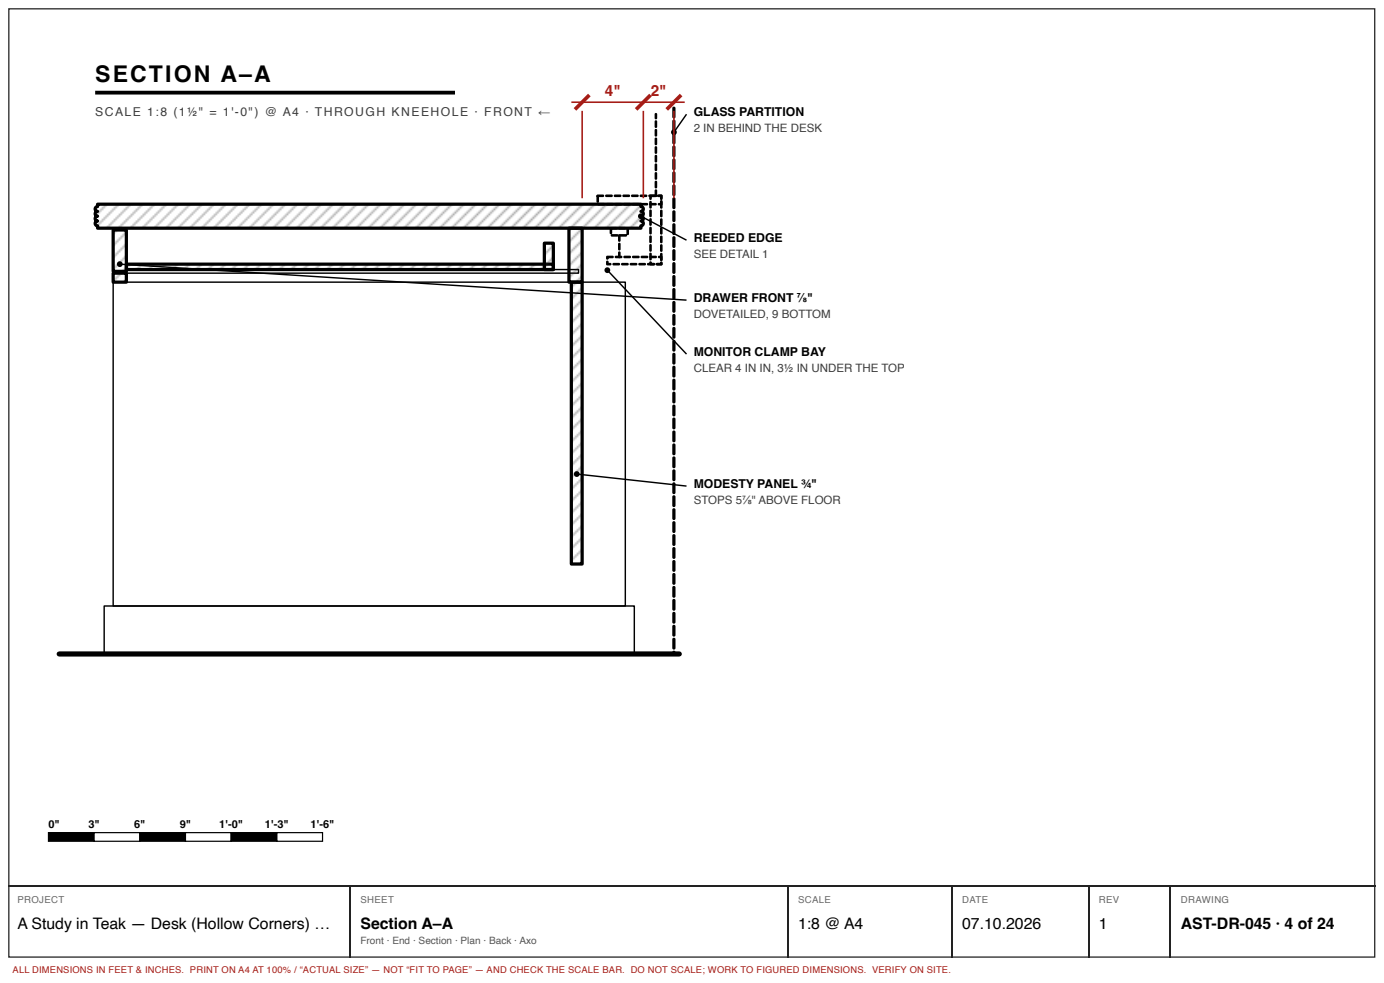
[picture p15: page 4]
DRAWER FRONT ⅞"; DOVETAILED, 9 BOTTOM; REEDED EDGE SEE DETAIL 1; Section A–A

GLASS PARTITION
2 IN BEHIND THE DESK

MONITOR CLAMP BAY
CLEAR 4 IN IN, 3½ IN UNDER THE TOP

MODESTY PANEL ¾"
STOPS 5⅞" ABOVE FLOOR

AST-DR-045 · 4 of 24

Front · End · Section · Plan · Back · Axo

# PLAN

## SCALE 1:12 (1" = 1'-0") @ A4 · FRONT AT TOP

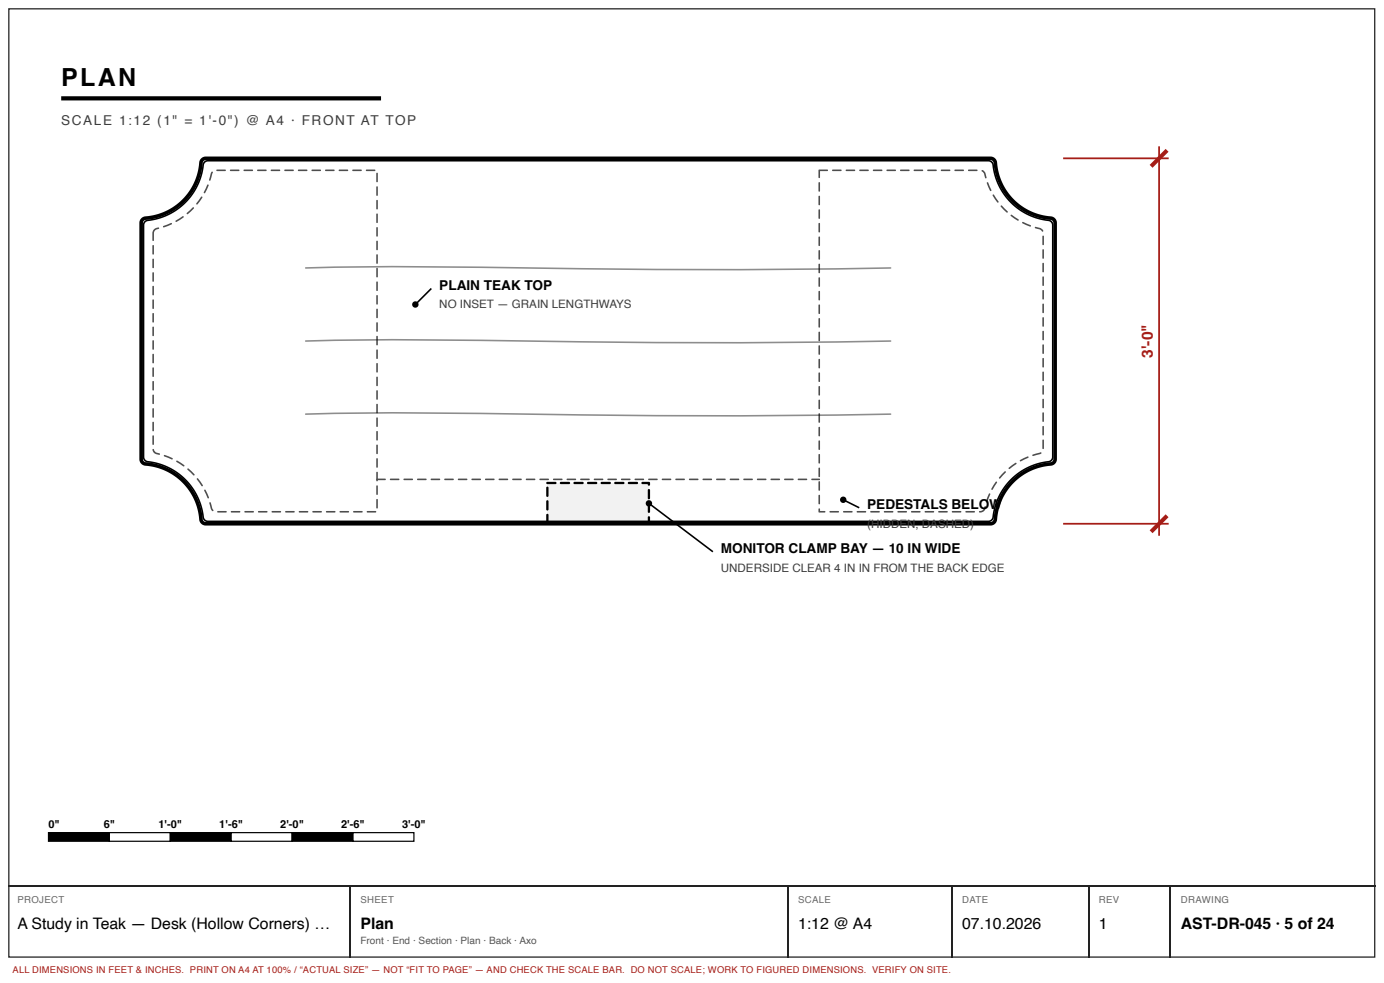
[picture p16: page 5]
PEDESTALS BELOW; (HIDDEN, DASHED); Plan

PLAIN TEAK TOP
NO INSET — GRAIN LENGTHWAYS

MONITOR CLAMP BAY — 10 IN WIDE
UNDERSIDE CLEAR 4 IN IN FROM THE BACK EDGE

AST-DR-045 · 5 of 24

Front · End · Section · Plan · Back · Axo

# BACK ELEVATION

# SCALE 1:10 @ A4 · IF FREE-STANDING

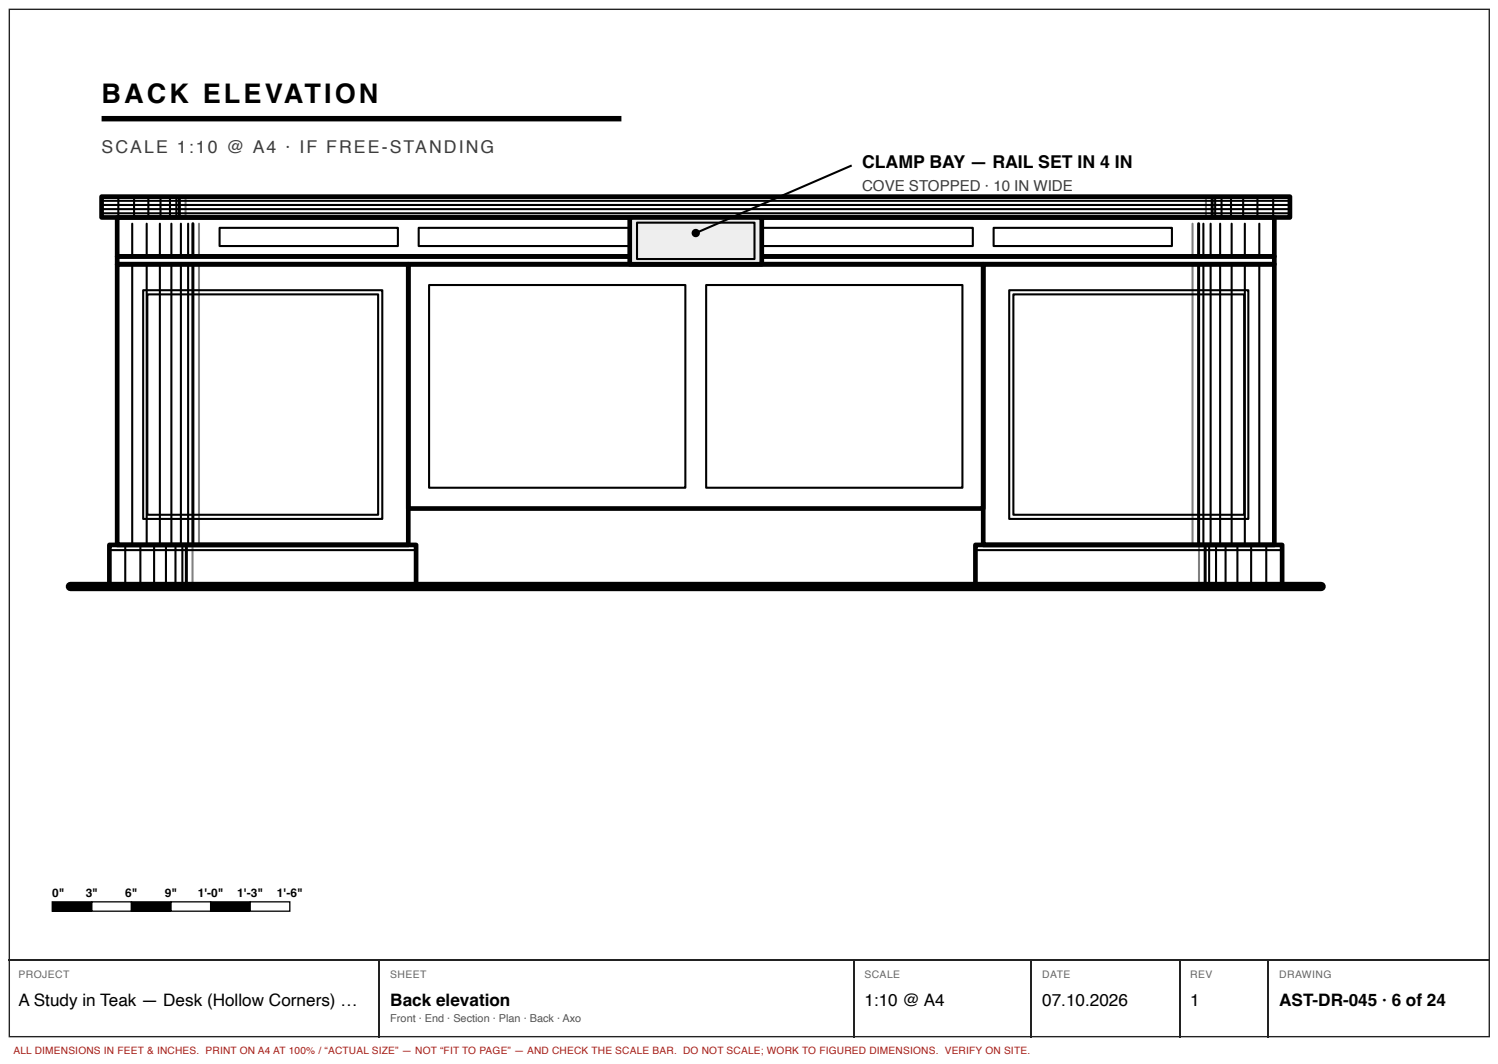
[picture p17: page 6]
Back elevation

CLAMP BAY — RAIL SET IN 4 IN
COVE STOPPED · 10 IN WIDE

AST-DR-045 · 6 of 24

Front · End · Section · Plan · Back · Axo

# AXONOMETRIC

## NOT TO SCALE · NOT TO SCALE · FROM FRONT RIGHT

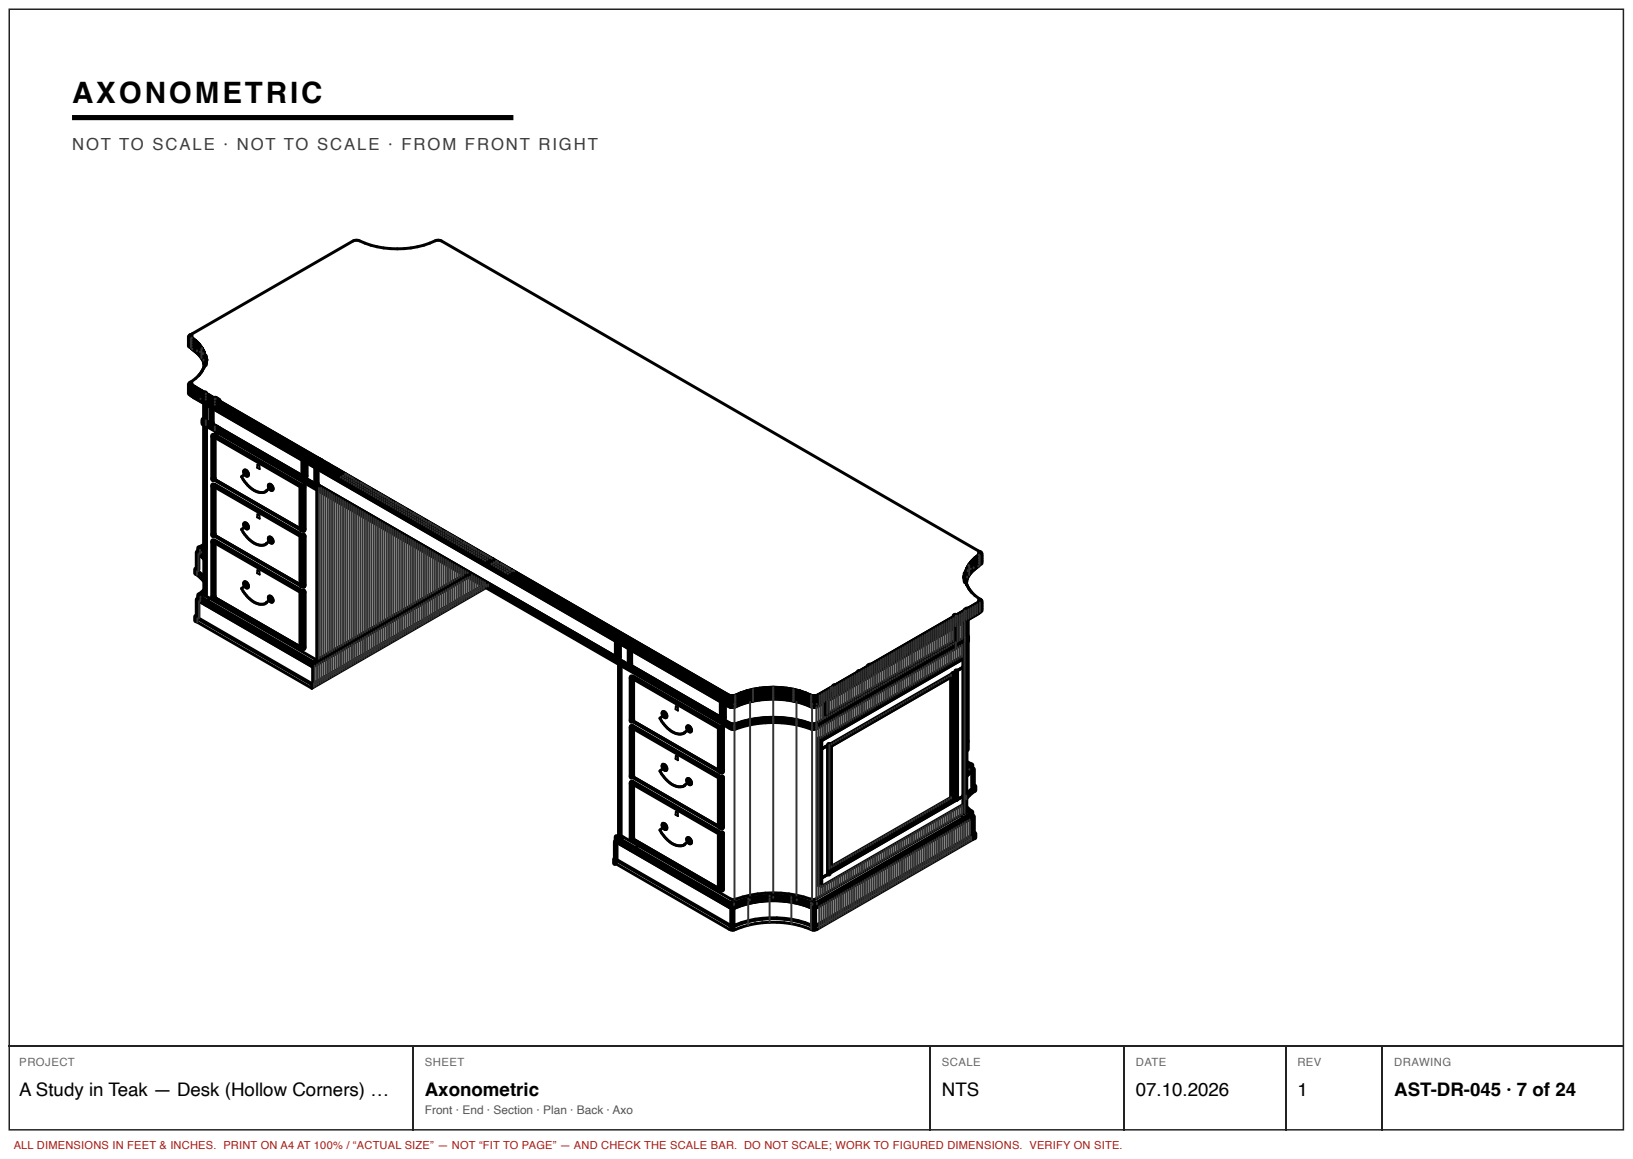
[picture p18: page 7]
Axonometric

AST-DR-045 · 7 of 24

Front · End · Section · Plan · Back · Axo

# K EY

# PARTS OF THE DESK

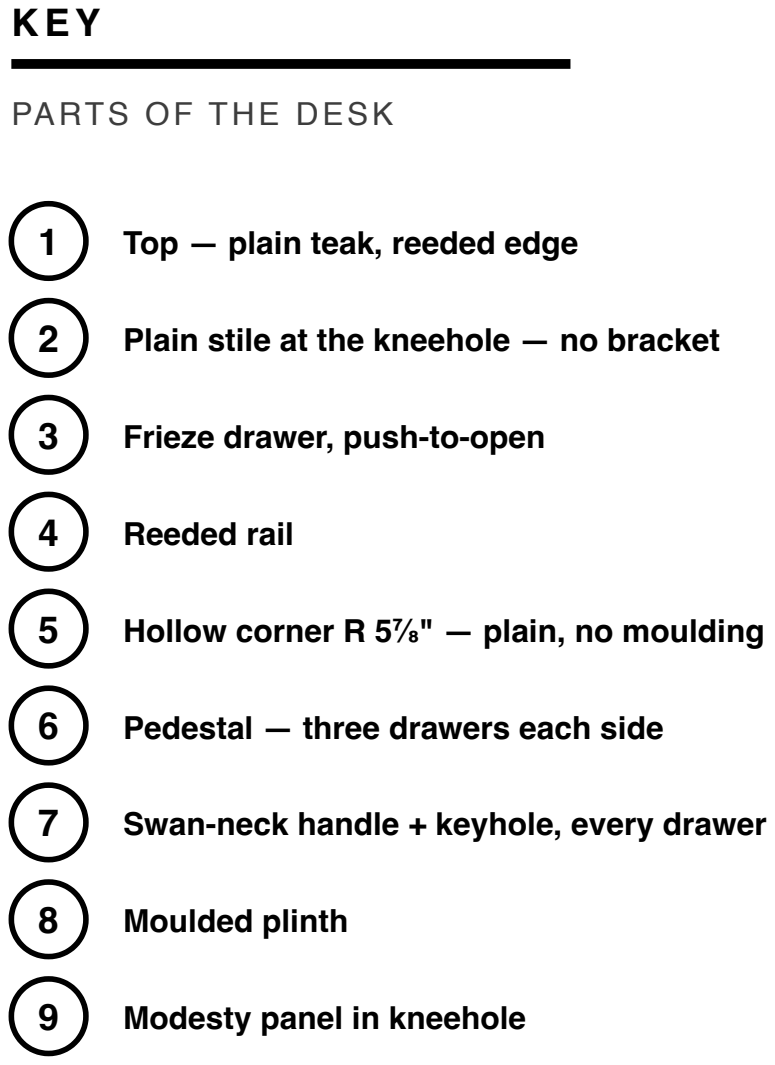
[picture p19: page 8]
4 Reeded rail; 8 Moulded plinth; Key

1 Top — plain teak, reeded edge

2 Plain stile at the kneehole — no bracket

3 Frieze drawer, push-to-open

5 Hollow corner R 5⅞" — plain, no moulding

6 Pedestal — three drawers each side

7 Swan-neck handle + keyhole, every drawer

9 Modesty panel in kneehole

AST-DR-045 · 8 of 24

Front · End · Section · Plan · Back · Axo

# N O TES

# READ BEFORE MAKING

Dimensions in feet and inches. Do not scale.

THE PLAIN DESK WITH ITS HOLLOW CORNERS (owner, 7 Oct).

As AST-DR-031 — no carving, no corner mouldings;

# reeded top edge, frieze, reeded rail and plinth —

but all four corners hollowed R 5⅞" again, top to bottom.

# Outer stiles 7" wide to clear the hollow, so the outer

drawers are a little narrower than on AST-DR-031.

MONITOR CLAMP BAY at the back centre, as before.

Top 1⅝ in solid teak.

First-angle projection.

# Notes

Front · End · Section · Plan · Back · Axo

# AST-DR-045 · 9 of 24

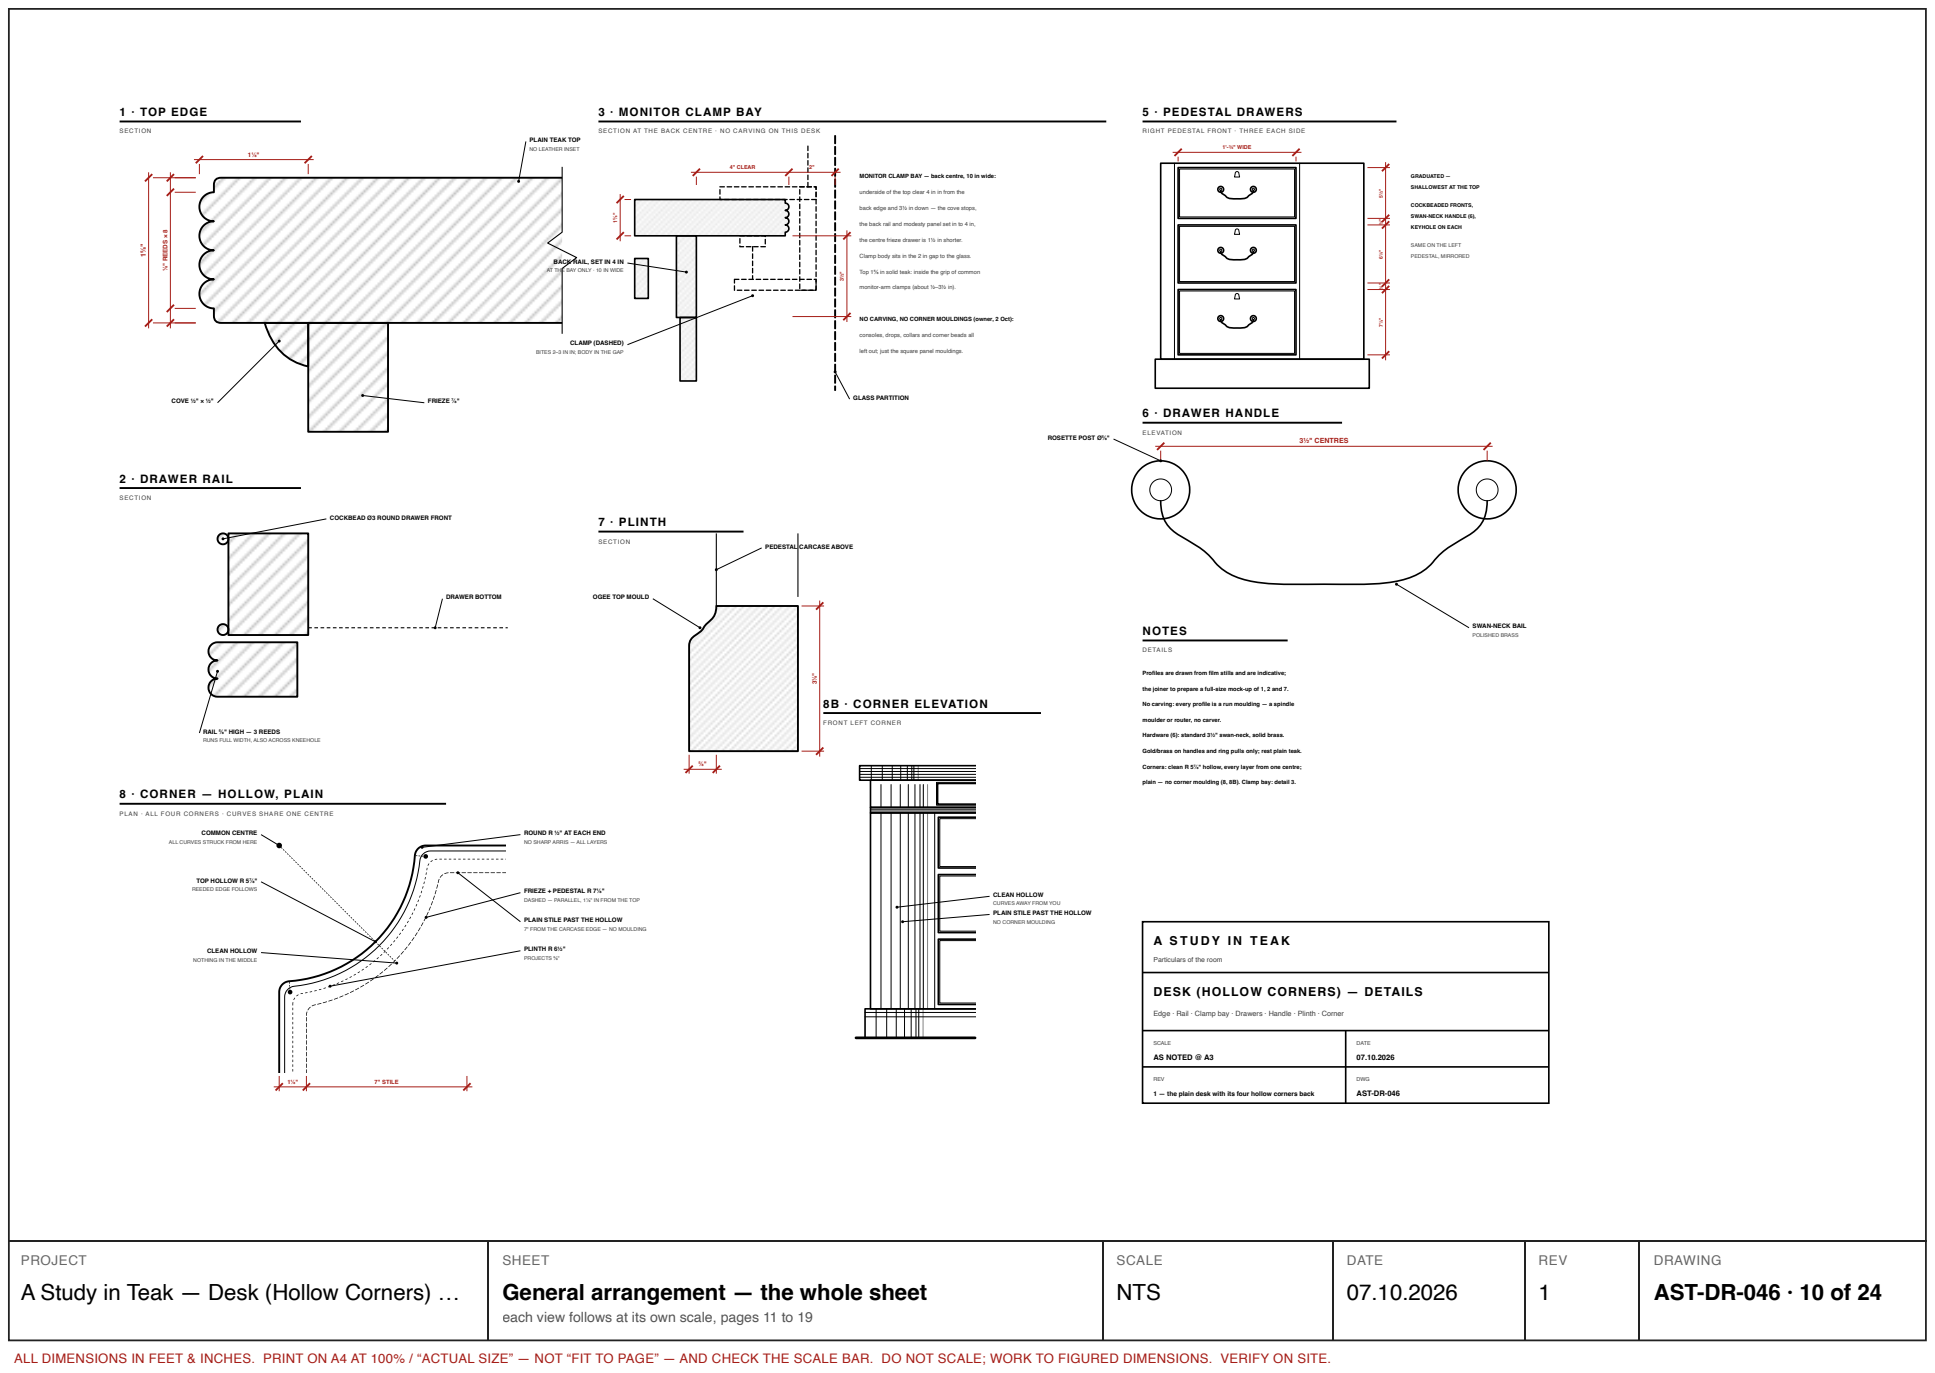
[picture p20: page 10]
1 · TOP EDGE; SECTION; ⅛" REEDS × 8; COVE ½" × ½"; FRIEZE ⅞"; 2 · DRAWER RAIL; DRAWER BOTTOM; 4" CLEAR; CLAMP (DASHED); GLASS PARTITION; 5 · PEDESTAL DRAWERS; 1'-¾" WIDE; GRADUATED —; COCKBEADED FRONTS,; PEDESTAL, MIRRORED; 6 · DRAWER HANDLE; ELEVATION; 3½" CENTRES; POLISHED BRASS; 7 · PLINTH; COMMON CENTRE; TOP HOLLOW R 5⅞"; FRIEZE + PEDESTAL R 7⅛"; PLINTH R 6½"; PROJECTS ⅝"; 7" STILE; 8B · CORNER ELEVATION; CLEAN HOLLOW; NOTES; DETAILS; SCALE; AS NOTED @ A3; DATE; REV; DWG; AST-DR-046

3 · MONITOR CLAMP BAY

PLAIN TEAK TOP

NO LEATHER INSET

SECTION AT THE BACK CENTRE · NO CARVING ON THIS DESK

RIGHT PEDESTAL FRONT · THREE EACH SIDE

MONITOR CLAMP BAY — back centre, 10 in wide:

SHALLOWEST AT THE TOP

underside of the top clear 4 in in from the

back edge and 3½ in down — the cove stops,

the back rail and modesty panel set in to 4 in,

SWAN-NECK HANDLE (6),

the centre frieze drawer is 1½ in shorter.

KEYHOLE ON EACH

BACK RAIL, SET IN 4 IN

Clamp body sits in the 2 in gap to the glass.

SAME ON THE LEFT

AT THE BAY ONLY · 10 IN WIDE

Top 1⅝ in solid teak: inside the grip of common

monitor-arm clamps (about ½–3½ in).

NO CARVING, NO CORNER MOULDINGS (owner, 2 Oct):

consoles, drops, collars and corner beads all

BITES 2–3 IN IN; BODY IN THE GAP

left out; just the square panel mouldings.

ROSETTE POST Ø⅝"

COCKBEAD Ø3 ROUND DRAWER FRONT

PEDESTAL CARCASE ABOVE

OGEE TOP MOULD

SWAN-NECK BAIL

Profiles are drawn from film stills and are indicative;

the joiner to prepare a full-size mock-up of 1, 2 and 7.

No carving: every profile is a run moulding — a spindle

moulder or router, no carver.

RAIL ⅝" HIGH — 3 REEDS

FRONT LEFT CORNER

Hardware (6): standard 3½" swan-neck, solid brass.

RUNS FULL WIDTH, ALSO ACROSS KNEEHOLE

Gold/brass on handles and ring pulls only; rest plain teak.

Corners: clean R 5⅞" hollow, every layer from one centre;

8 · CORNER — HOLLOW, PLAIN

plain — no corner moulding (8, 8B). Clamp bay: detail 3.

PLAN · ALL FOUR CORNERS · CURVES SHARE ONE CENTRE

ROUND R ½" AT EACH END
NO SHARP ARRIS — ALL LAYERS

ALL CURVES STRUCK FROM HERE

REEDED EDGE FOLLOWS

DASHED — PARALLEL, 1⅛" IN FROM THE TOP

CURVES AWAY FROM YOU
PLAIN STILE PAST THE HOLLOW

7" FROM THE CARCASE EDGE — NO MOULDING

NO CORNER MOULDING

CLEAN HOLLOW
NOTHING IN THE MIDDLE

Particulars of the room

DESK (HOLLOW CORNERS) — DETAILS

Edge · Rail · Clamp bay · Drawers · Handle · Plinth · Corner

1 — the plain desk with its four hollow corners back

General arrangement — the whole sheet

AST-DR-046 · 10 of 24

each view follows at its own scale, pages 11 to 19

## 1 · TOP EDGE

1⅛"

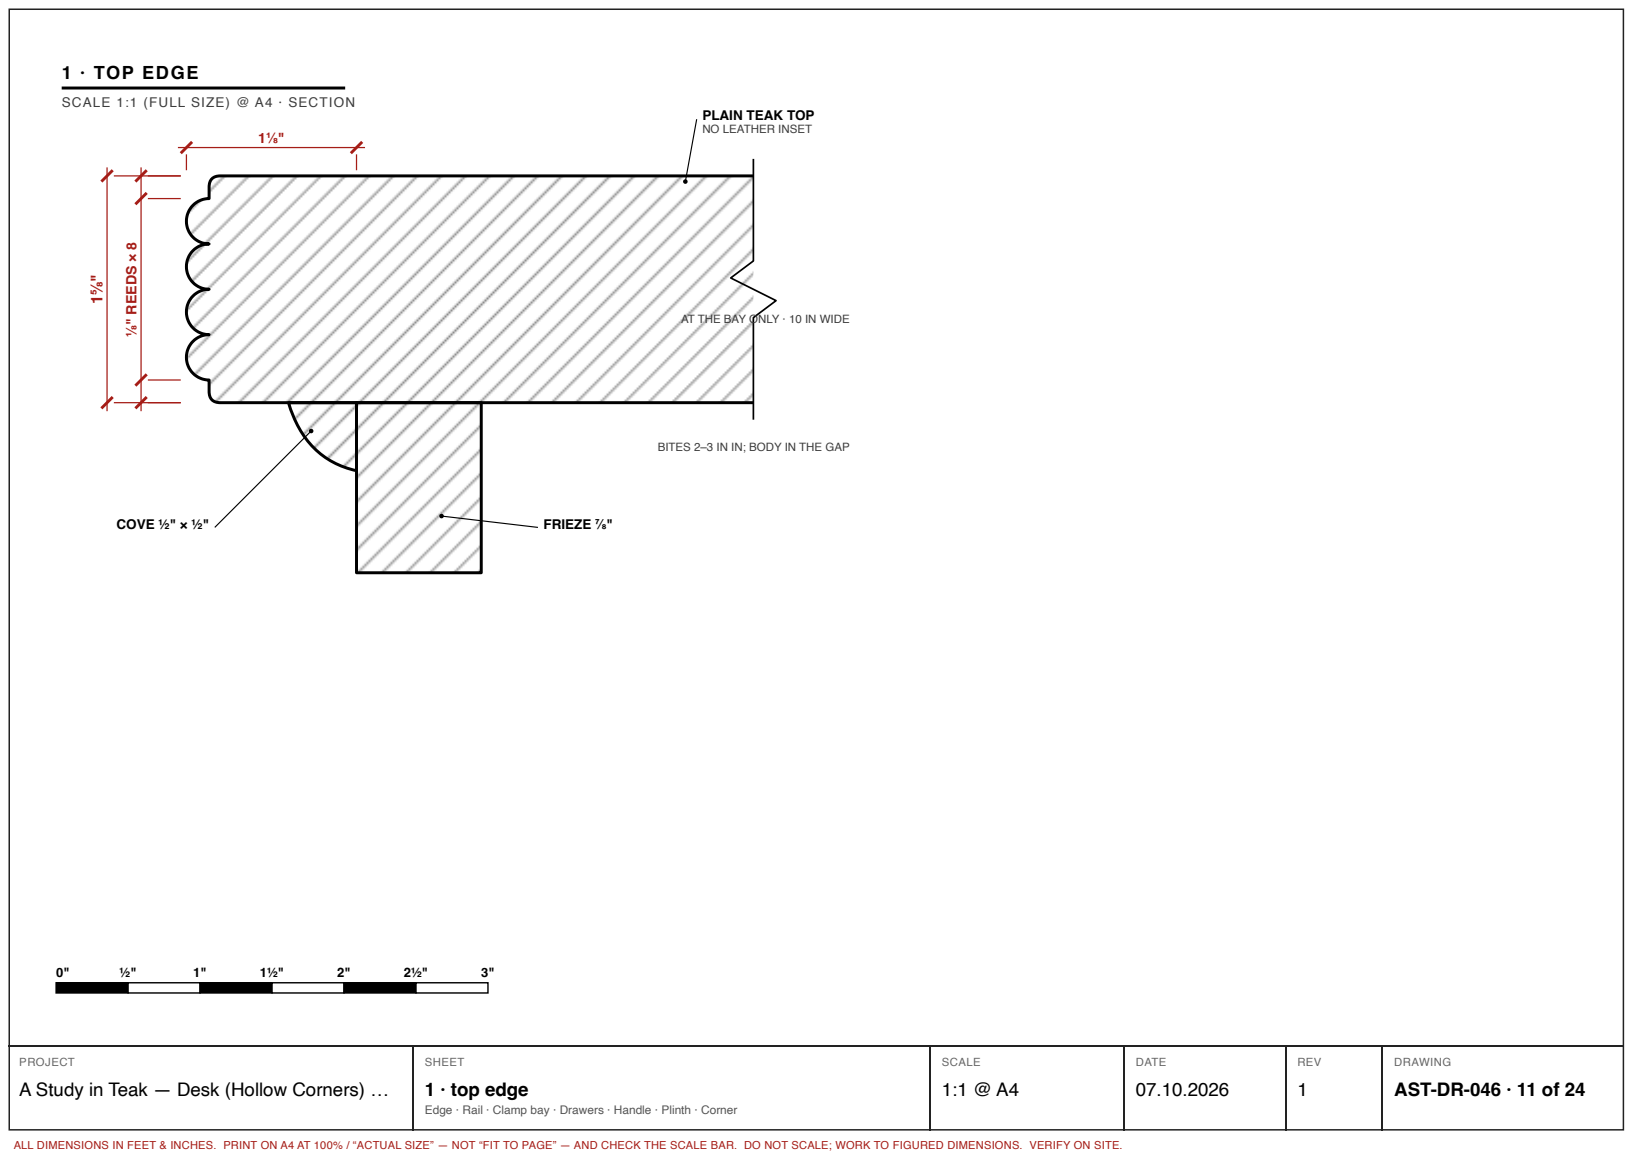
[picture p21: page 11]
⅛" REEDS × 8; COVE ½" × ½"; FRIEZE ⅞"; 1 · top edge

SCALE 1:1 (FULL SIZE) @ A4 · SECTION

PLAIN TEAK TOP
NO LEATHER INSET

AT THE BAY ONLY · 10 IN WIDE

BITES 2–3 IN IN; BODY IN THE GAP

AST-DR-046 · 11 of 24

Edge · Rail · Clamp bay · Drawers · Handle · Plinth · Corner

# 3 · MONITOR CLAMP BAY

### SCALE 1:3 (4" = 1'-0") @ A4 · SECTION AT THE BACK CENTRE · NO CARVING ON THIS DESK

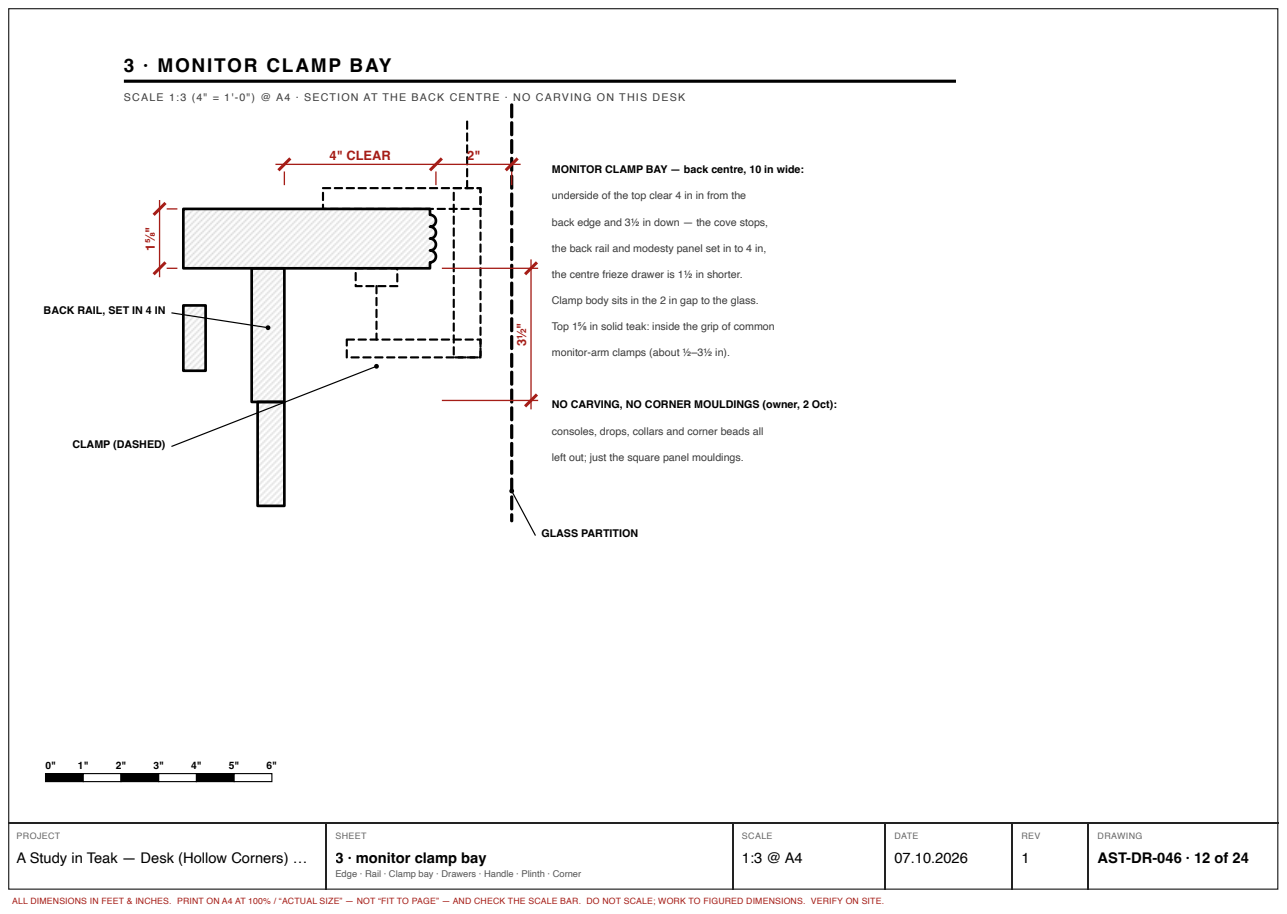
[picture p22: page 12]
4" CLEAR; CLAMP (DASHED); GLASS PARTITION

MONITOR CLAMP BAY — back centre, 10 in wide:

underside of the top clear 4 in in from the

back edge and 3½ in down — the cove stops,

the back rail and modesty panel set in to 4 in,

the centre frieze drawer is 1½ in shorter.

Clamp body sits in the 2 in gap to the glass.

BACK RAIL, SET IN 4 IN

Top 1⅝ in solid teak: inside the grip of common

monitor-arm clamps (about ½–3½ in).

NO CARVING, NO CORNER MOULDINGS (owner, 2 Oct):

consoles, drops, collars and corner beads all

left out; just the square panel mouldings.

3 · monitor clamp bay

AST-DR-046 · 12 of 24

Edge · Rail · Clamp bay · Drawers · Handle · Plinth · Corner

# 5 · PEDESTAL DRAWERS

## SCALE 1:6 (2" = 1'-0") @ A4 · RIGHT PEDESTAL FRONT · THREE EACH SIDE

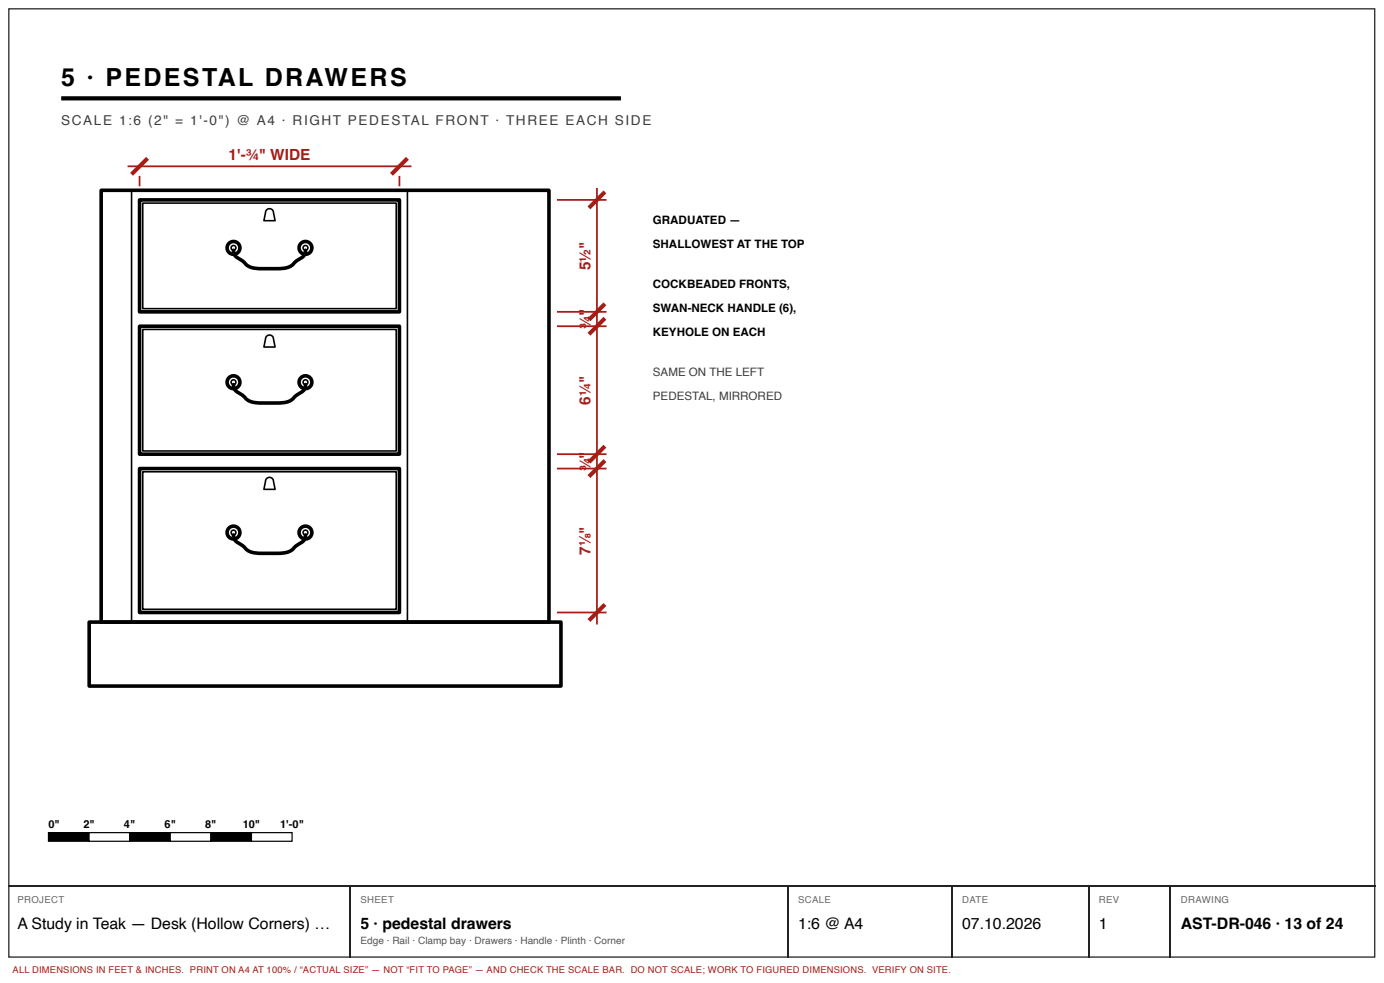
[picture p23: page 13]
1'-¾" WIDE; GRADUATED —; COCKBEADED FRONTS,; PEDESTAL, MIRRORED; 5 · pedestal drawers

SHALLOWEST AT THE TOP

SWAN-NECK HANDLE (6),

KEYHOLE ON EACH

SAME ON THE LEFT

AST-DR-046 · 13 of 24

Edge · Rail · Clamp bay · Drawers · Handle · Plinth · Corner

## 2 · DRAWER RAIL

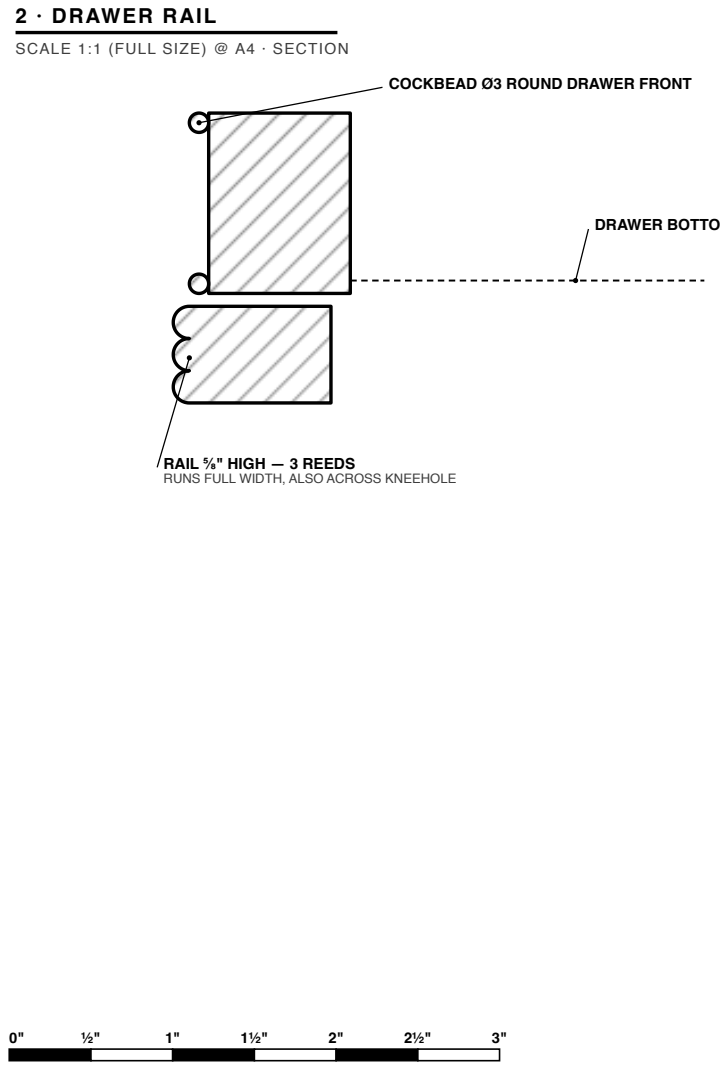
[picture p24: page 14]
DRAWER BOTTO; 2 · drawer rail

SCALE 1:1 (FULL SIZE) @ A4 · SECTION

COCKBEAD Ø3 ROUND DRAWER FRONT

RAIL ⅝" HIGH — 3 REEDS
RUNS FULL WIDTH, ALSO ACROSS KNEEHOLE

AST-DR-046 · 14 of 24

Edge · Rail · Clamp bay · Drawers · Handle · Plinth · Corner

## 6 · DRAWER HANDLE

## 3½" CENTRES

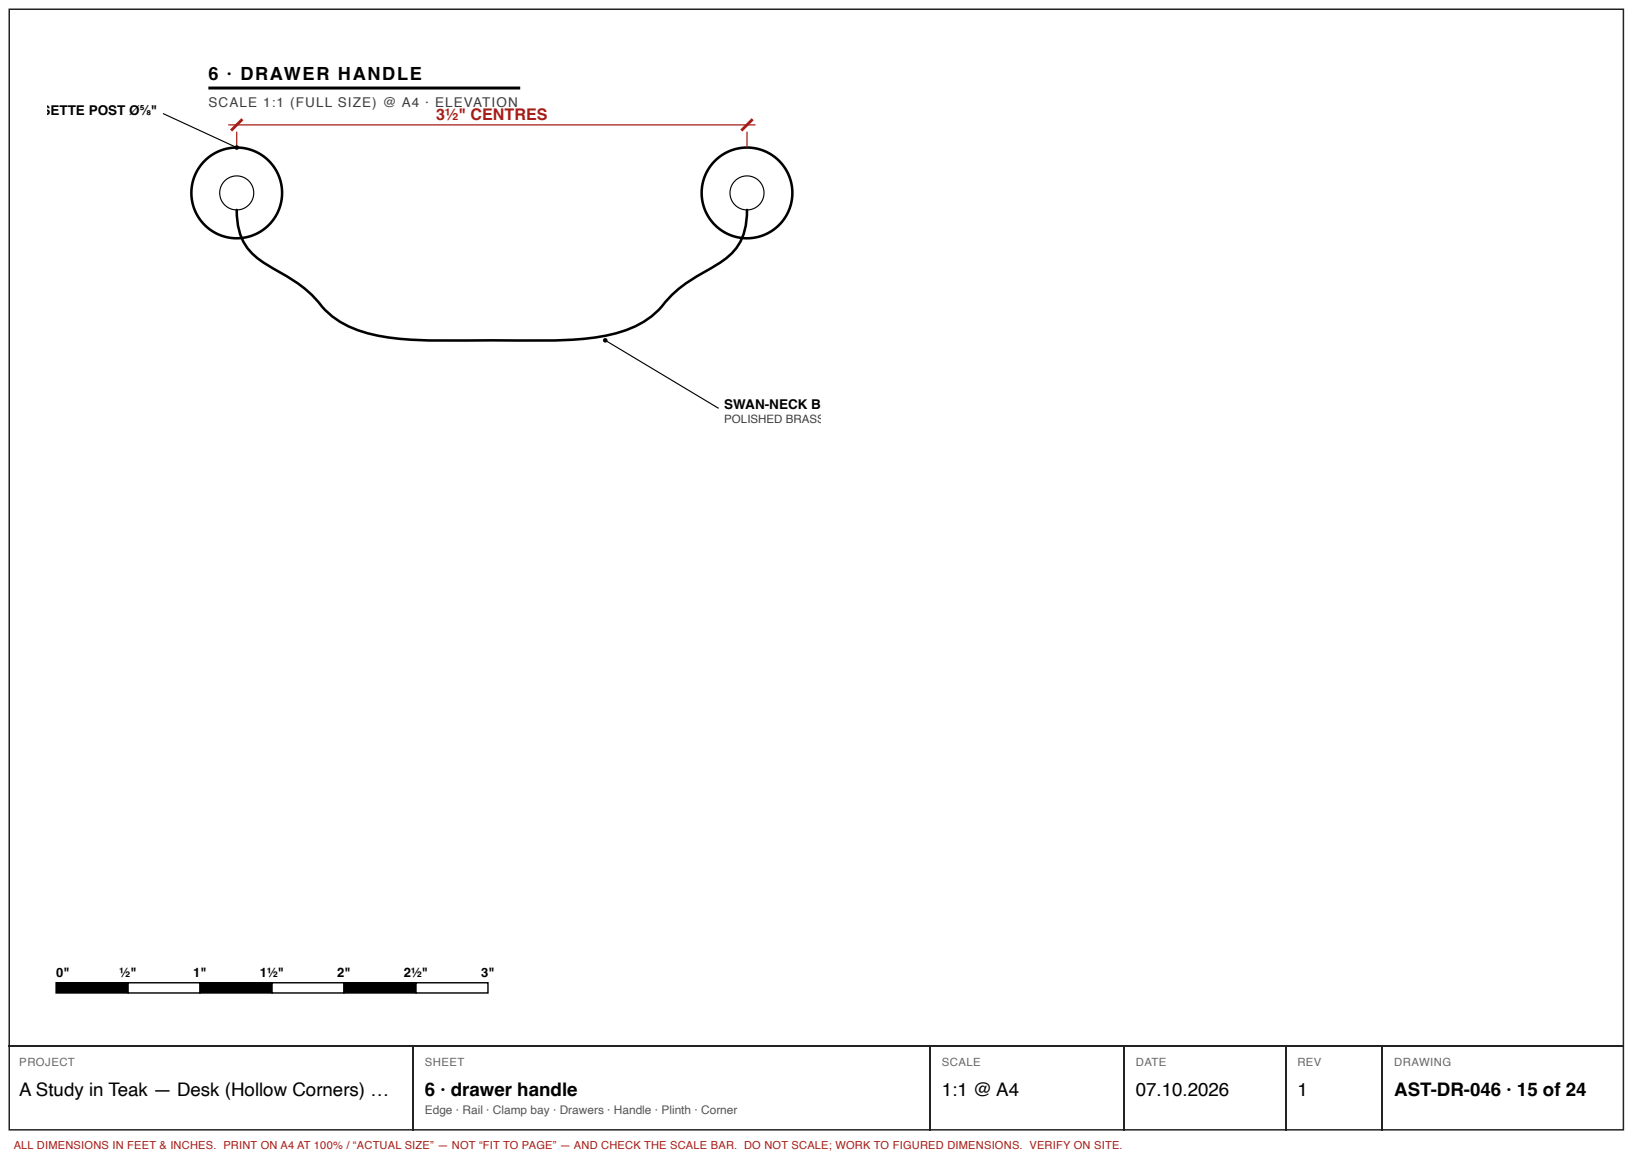
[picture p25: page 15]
SWAN-NECK B POLISHED BRASS; 6 · drawer handle

SETTE POST Ø⅝"

SCALE 1:1 (FULL SIZE) @ A4 · ELEVATION

AST-DR-046 · 15 of 24

Edge · Rail · Clamp bay · Drawers · Handle · Plinth · Corner

# 7 · PLINTH

# SCALE 1:1 (FULL SIZE) @ A4 · SECTION

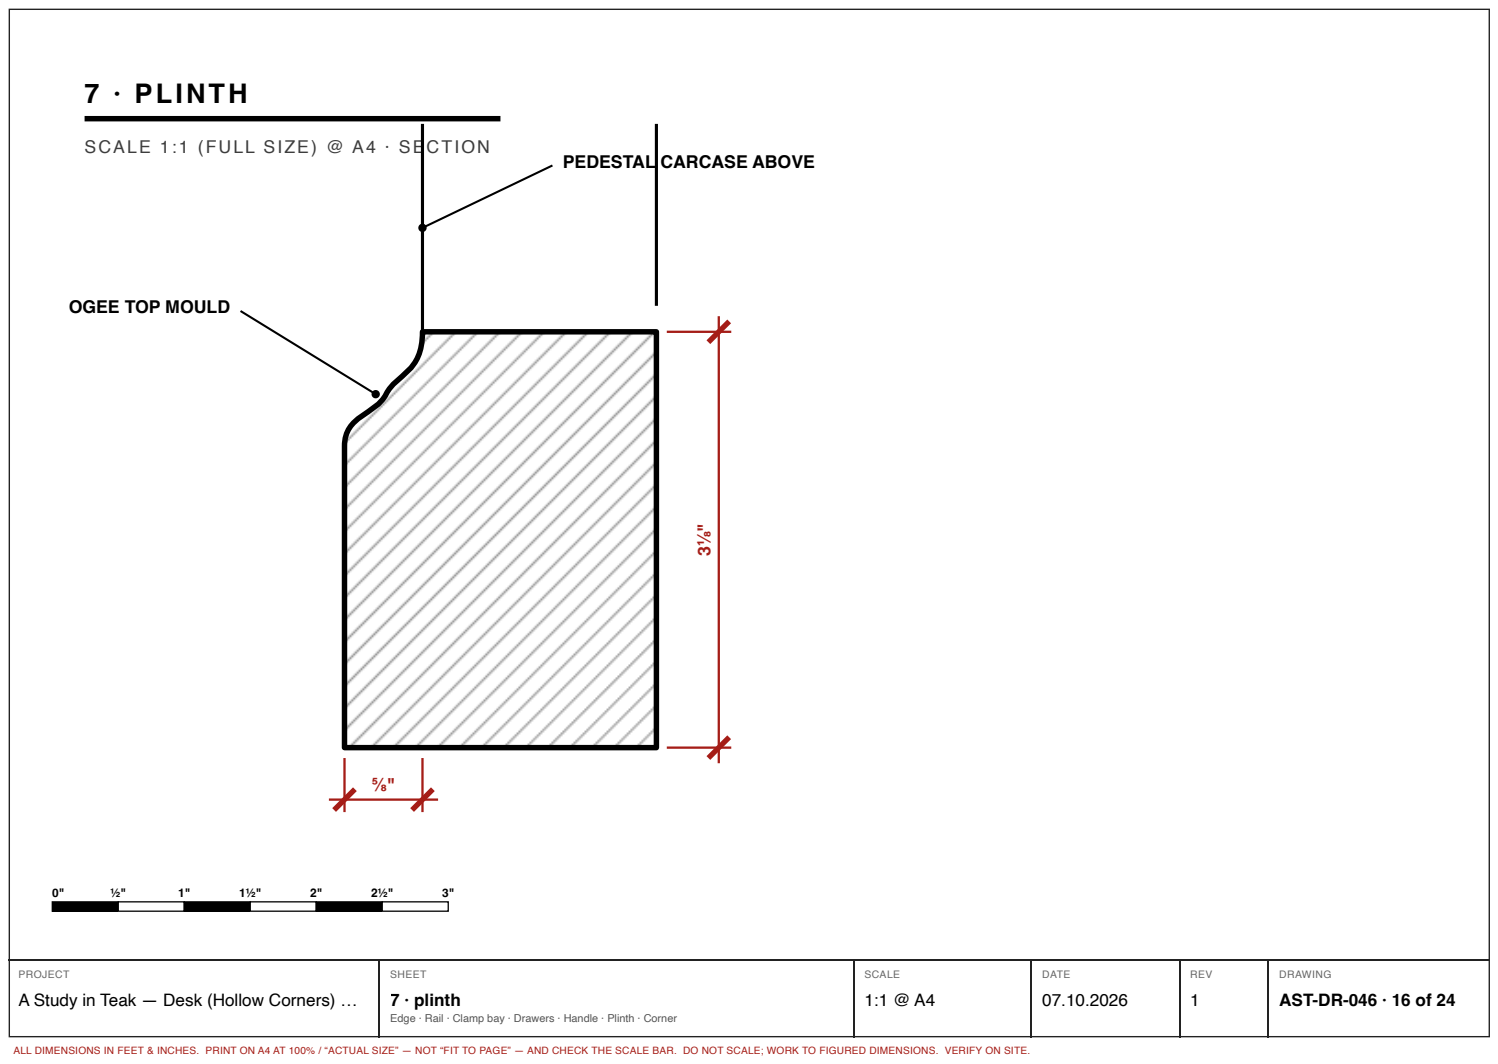
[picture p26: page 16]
7 · plinth

PEDESTAL CARCASE ABOVE

OGEE TOP MOULD

AST-DR-046 · 16 of 24

Edge · Rail · Clamp bay · Drawers · Handle · Plinth · Corner

# NOTES

# DETAILS

Profiles are drawn from film stills and are indicative;

the joiner to prepare a full-size mock-up of 1, 2 and 7.

# No carving: every profile is a run moulding — a spindle

moulder or router, no carver.

Hardware (6): standard 3½" swan-neck, solid brass.

Gold/brass on handles and ring pulls only; rest plain teak.

Corners: clean R 5⅞" hollow, every layer from one centre;

plain — no corner moulding (8, 8B). Clamp bay: detail 3.

# Notes

Edge · Rail · Clamp bay · Drawers · Handle · Plinth · Corner

# AST-DR-046 · 17 of 24

# 8B · CORNER ELEVATION

### SCALE 1:8 (1½" = 1'-0") @ A4 · FRONT LEFT CORNER

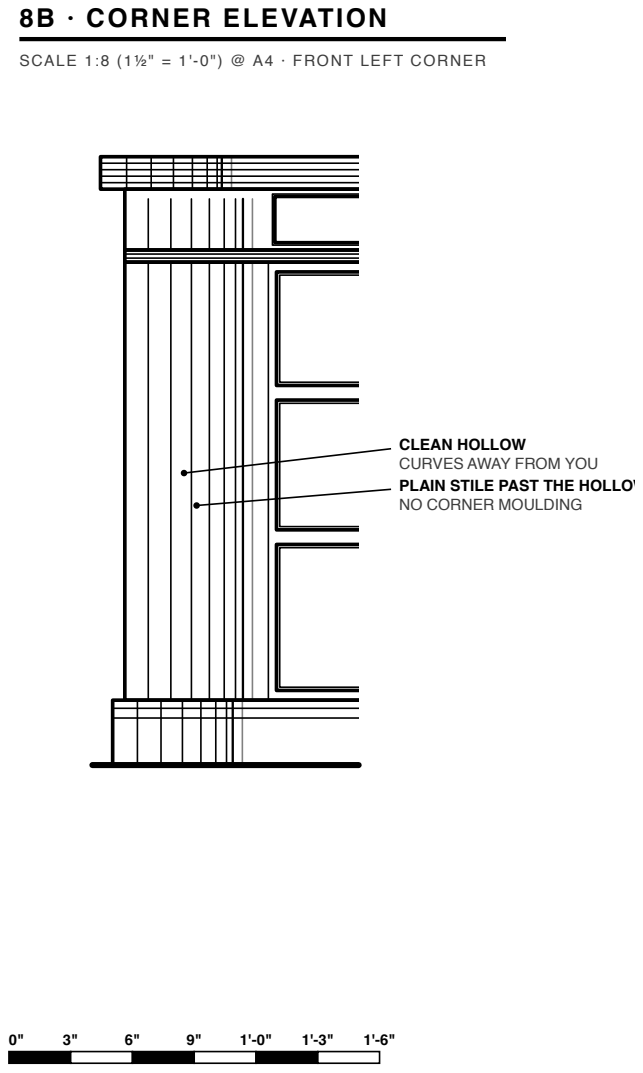
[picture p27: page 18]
8B · corner elevation

CLEAN HOLLOW
CURVES AWAY FROM YOU
PLAIN STILE PAST THE HOLLOW
NO CORNER MOULDING

AST-DR-046 · 18 of 24

Edge · Rail · Clamp bay · Drawers · Handle · Plinth · Corner

# 8 · CORNER — HOLLOW, PLAIN

### SCALE 1:3 (4" = 1'-0") @ A4 · PLAN · ALL FOUR CORNERS · CURVES SHARE ONE CENTRE

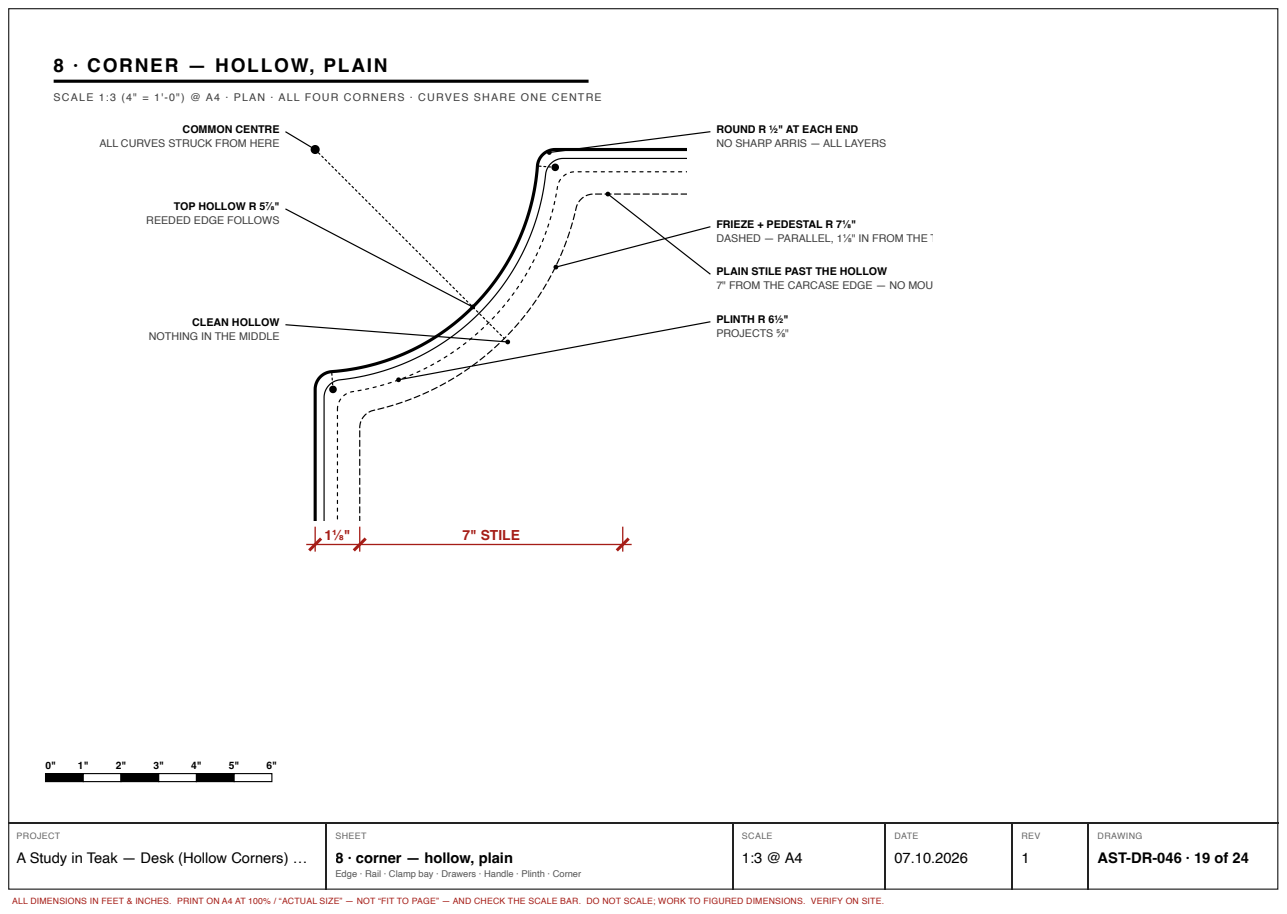
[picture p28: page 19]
COMMON CENTRE; CLEAN HOLLOW; PLINTH R 6½" PROJECTS ⅝"; 7" STILE

ROUND R ½" AT EACH END
NO SHARP ARRIS — ALL LAYERS

ALL CURVES STRUCK FROM HERE

TOP HOLLOW R 5⅞"
REEDED EDGE FOLLOWS

FRIEZE + PEDESTAL R 7⅛"
DASHED — PARALLEL, 1⅛" IN FROM THE T

PLAIN STILE PAST THE HOLLOW
7" FROM THE CARCASE EDGE — NO MOU

NOTHING IN THE MIDDLE

8 · corner — hollow, plain

AST-DR-046 · 19 of 24

Edge · Rail · Clamp bay · Drawers · Handle · Plinth · Corner

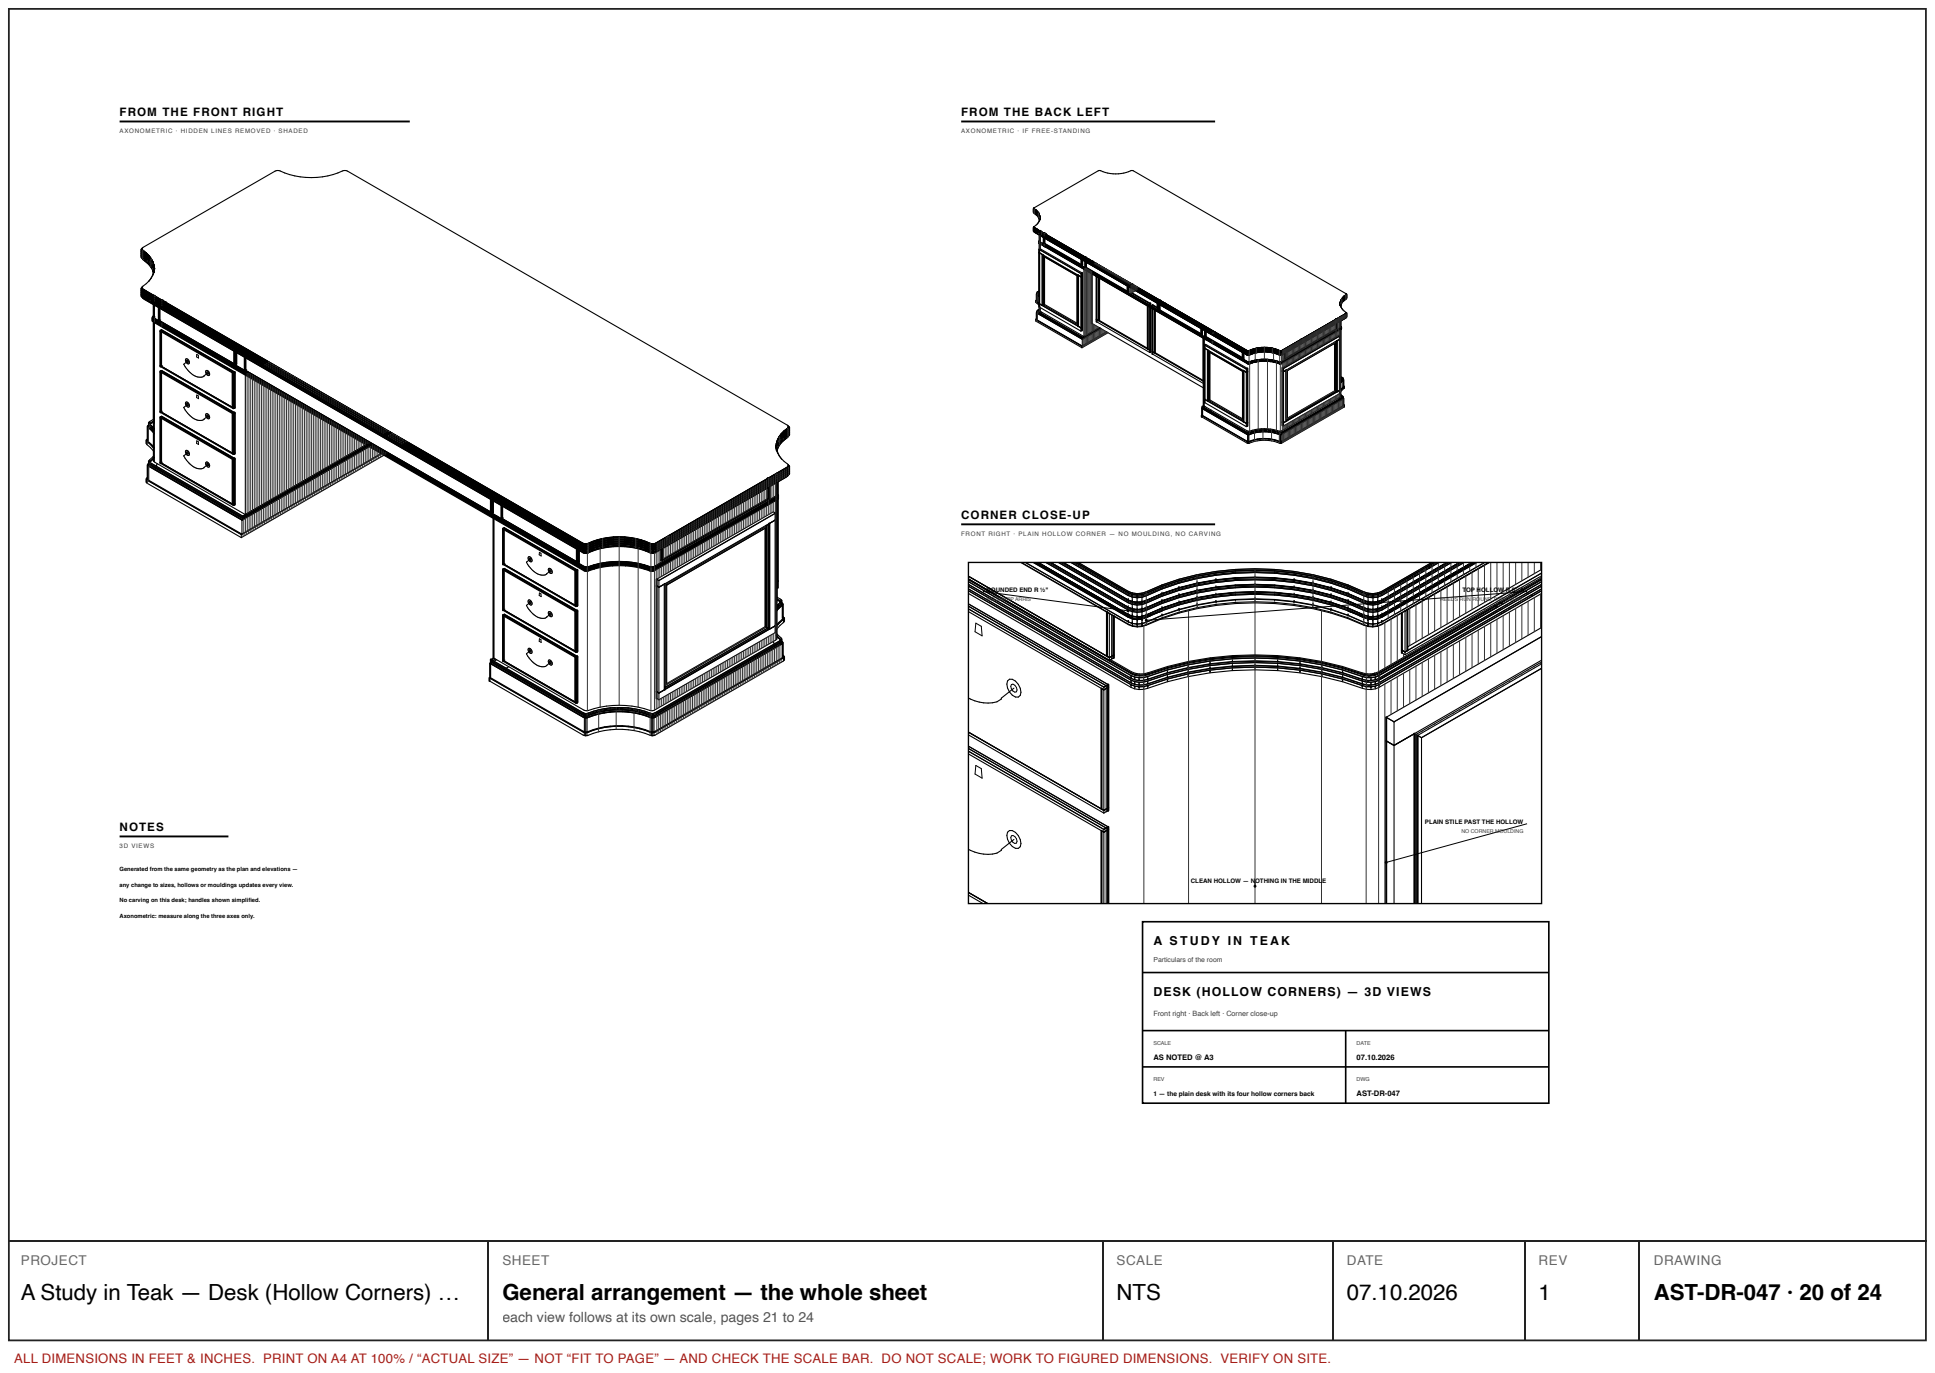
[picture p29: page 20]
TOP HOLLOW R 5⅞"; ROUNDED END R ½"; NOTES; 3D VIEWS; SCALE; AS NOTED @ A3; DATE; REV; DWG; AST-DR-047

FROM THE FRONT RIGHT

FROM THE BACK LEFT

AXONOMETRIC · HIDDEN LINES REMOVED · SHADED

AXONOMETRIC · IF FREE-STANDING

CORNER CLOSE-UP

FRONT RIGHT · PLAIN HOLLOW CORNER — NO MOULDING, NO CARVING

NO SHARP ARRIS

REEDS RUN ROUND THE CURVE

PLAIN STILE PAST THE HOLLOW

NO CORNER MOULDING

Generated from the same geometry as the plan and elevations —

any change to sizes, hollows or mouldings updates every view.

CLEAN HOLLOW — NOTHING IN THE MIDDLE

No carving on this desk; handles shown simplified.

Axonometric: measure along the three axes only.

Particulars of the room

DESK (HOLLOW CORNERS) — 3D VIEWS

Front right · Back left · Corner close-up

1 — the plain desk with its four hollow corners back

General arrangement — the whole sheet

AST-DR-047 · 20 of 24

each view follows at its own scale, pages 21 to 24

## FROM THE FRONT RIGHT

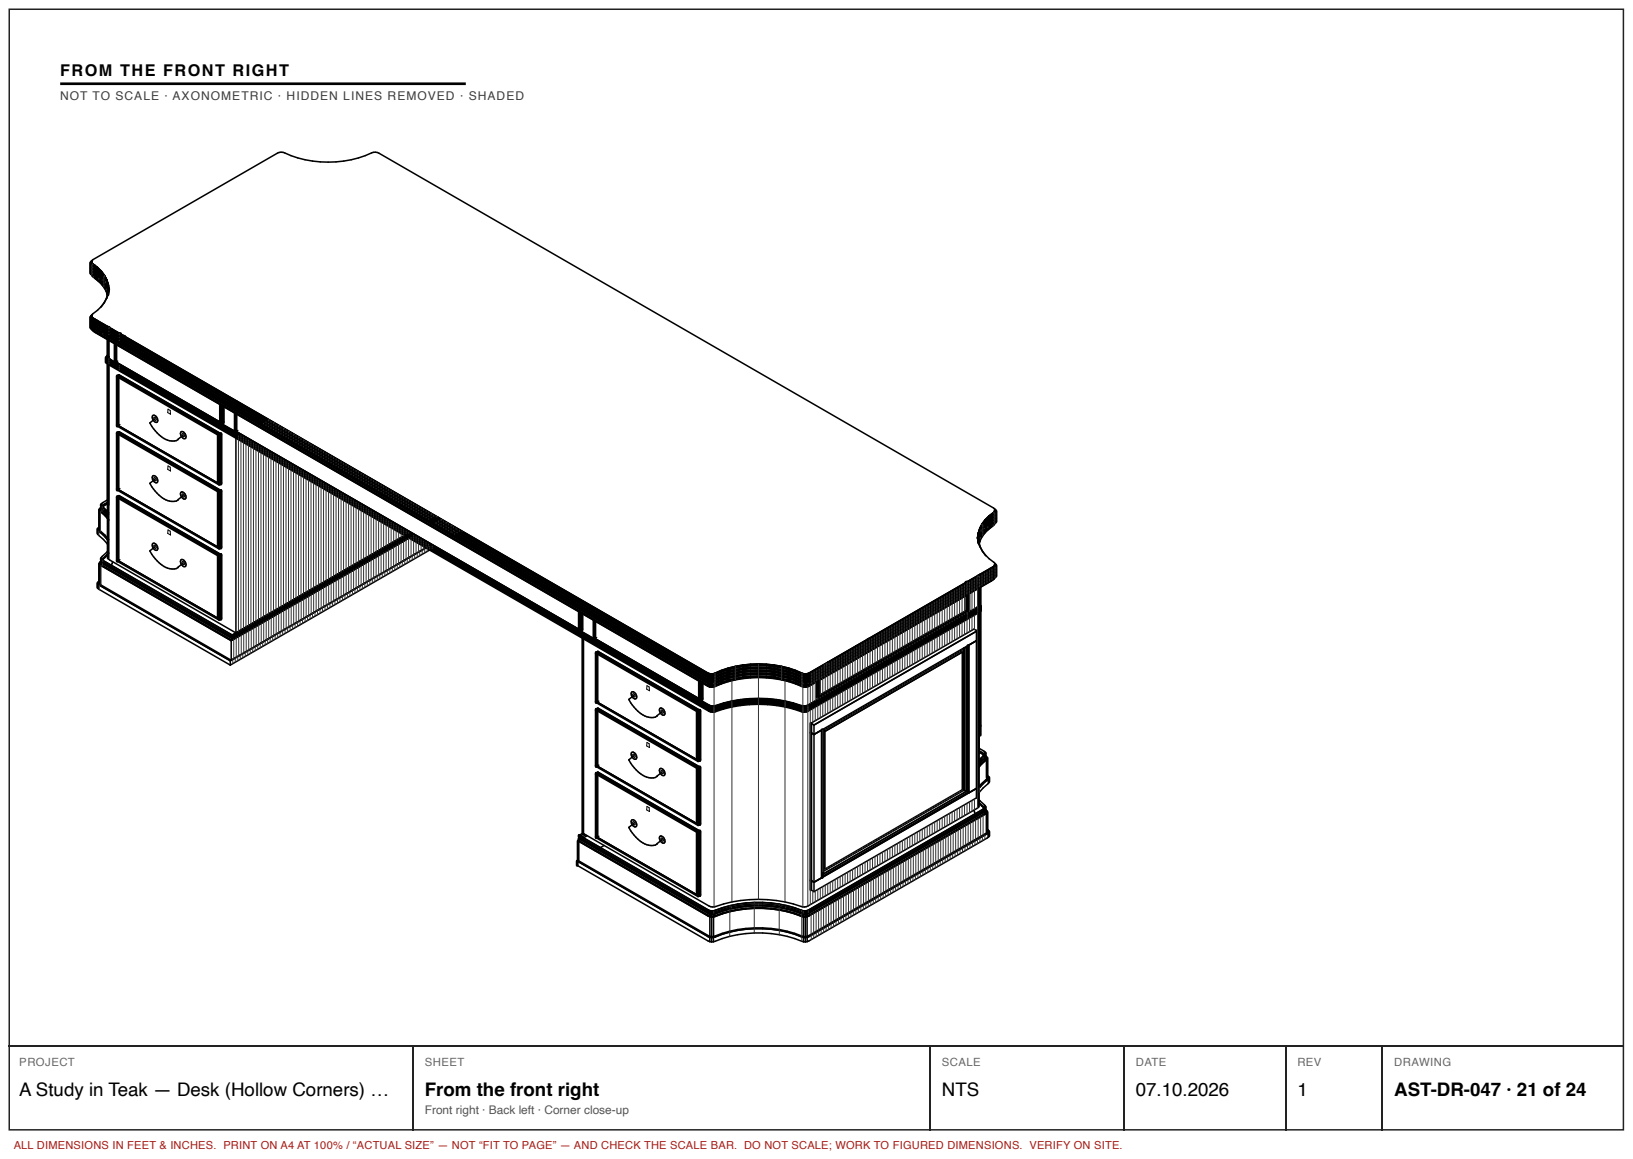
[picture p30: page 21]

NOT TO SCALE · AXONOMETRIC · HIDDEN LINES REMOVED · SHADED

From the front right

AST-DR-047 · 21 of 24

Front right · Back left · Corner close-up

# FROM THE BACK LEFT

## NOT TO SCALE · AXONOMETRIC · IF FREE-STANDING

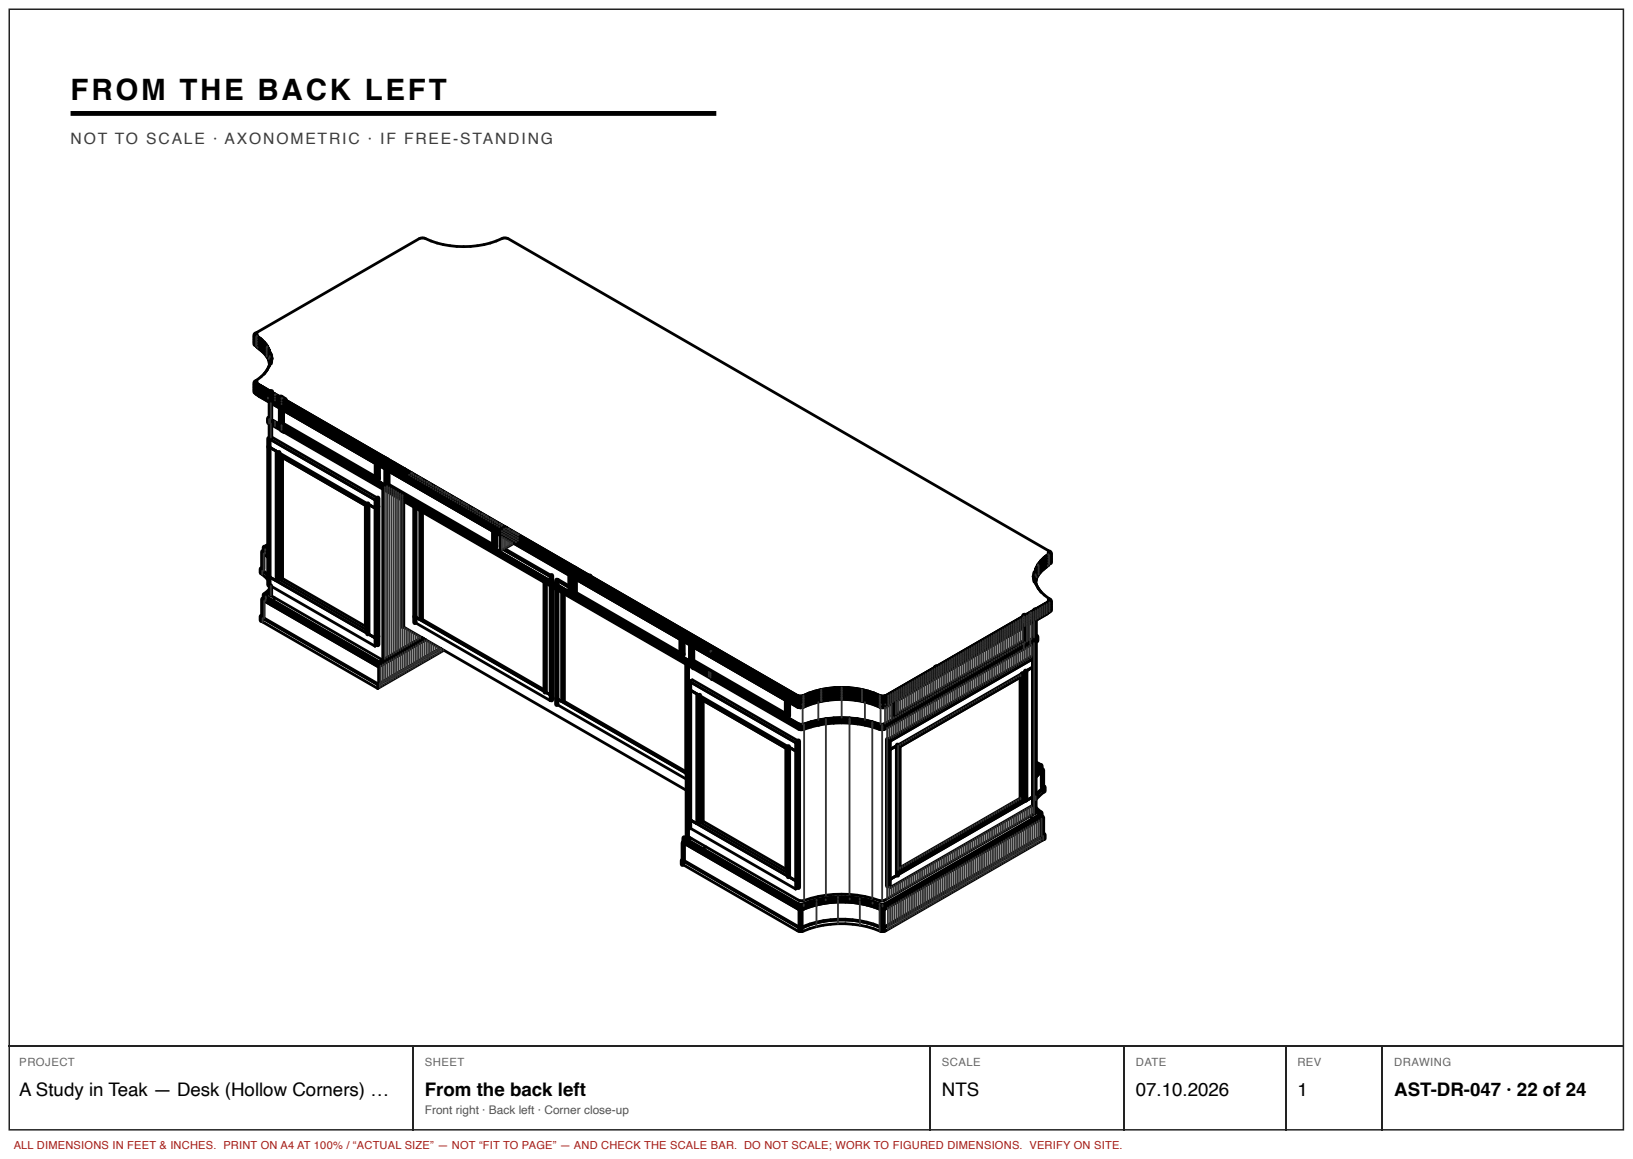
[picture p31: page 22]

From the back left

AST-DR-047 · 22 of 24

Front right · Back left · Corner close-up

# CORNER CLOSE-UP

### NOT TO SCALE · FRONT RIGHT · PLAIN HOLLOW CORNER — NO MOULDING, NO CARVING

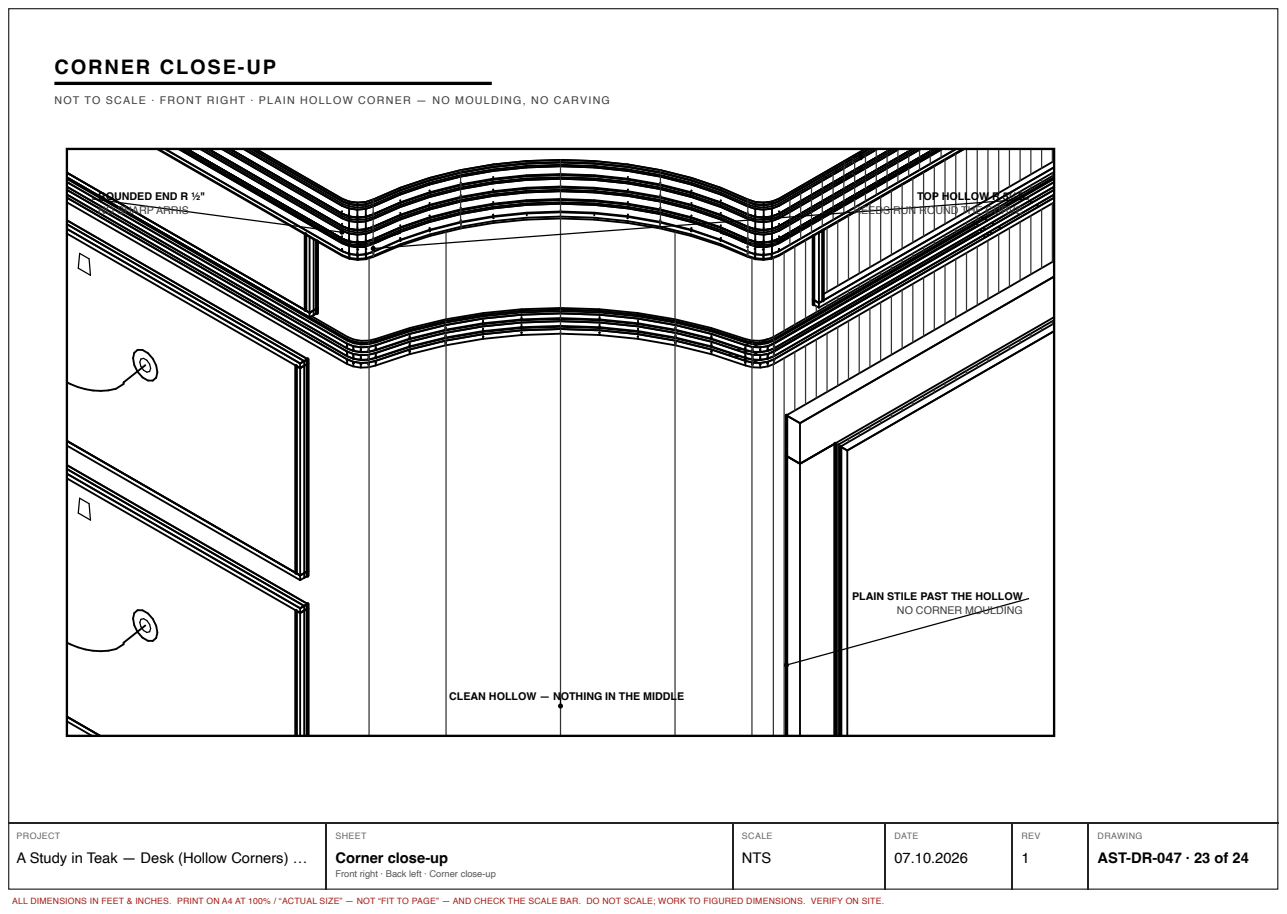
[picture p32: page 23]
TOP HOLLOW R 5⅞"

ROUNDED END R ½"
NO SHARP ARRIS

REEDS RUN ROUND THE CURVE

PLAIN STILE PAST THE HOLLOW

NO CORNER MOULDING

CLEAN HOLLOW — NOTHING IN THE MIDDLE

Corner close-up

AST-DR-047 · 23 of 24

Front right · Back left · Corner close-up

# N O T E S

# 3D VIEWS

# Generated from the same geometry as the plan and elevations —

any change to sizes, hollows or mouldings updates every view.

No carving on this desk; handles shown simplified.

Axonometric: measure along the three axes only.

# Notes

Front right · Back left · Corner close-up

# AST-DR-047 · 24 of 24

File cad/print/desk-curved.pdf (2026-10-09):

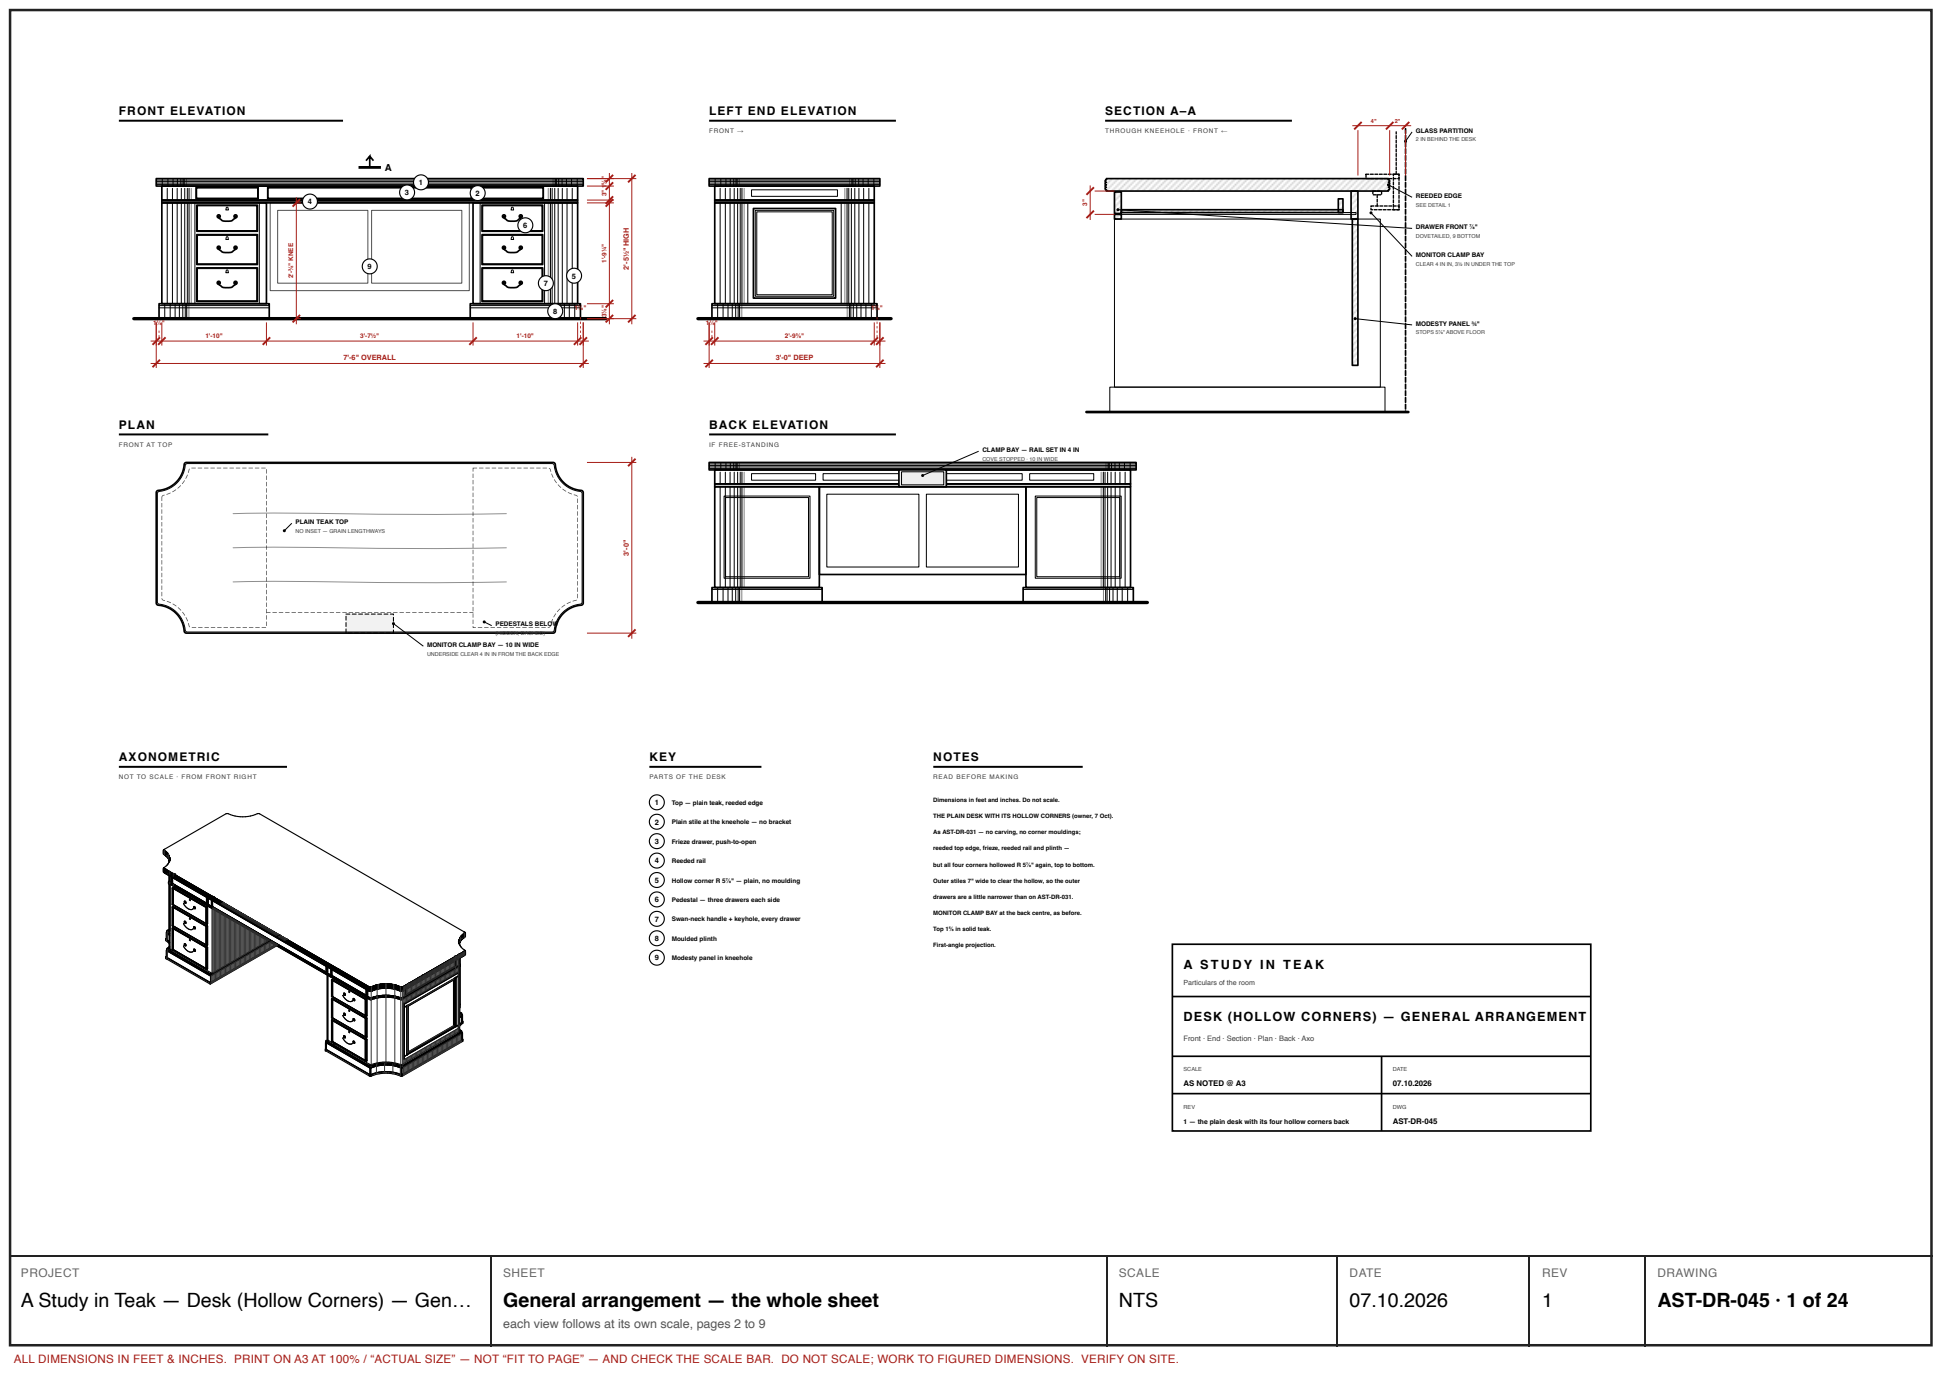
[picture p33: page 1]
FRONT ELEVATION; 7'-6" OVERALL; 2'-5½" HIGH; 2'-⅜" KNEE; FRONT →; 3'-0" DEEP; SECTION A–A; DRAWER FRONT ⅞"; DOVETAILED, 9 BOTTOM; REEDED EDGE; SEE DETAIL 1; PLAN; PEDESTALS BELOW; (HIDDEN, DASHED); BACK ELEVATION; AXONOMETRIC; KEY; 4 Reeded rail; 8 Moulded plinth; NOTES; SCALE; AS NOTED @ A3; DATE; REV; DWG; AST-DR-045; SCALE NTS; DATE 07.10.2026

LEFT END ELEVATION

THROUGH KNEEHOLE · FRONT ←

GLASS PARTITION
2 IN BEHIND THE DESK

MONITOR CLAMP BAY
CLEAR 4 IN IN, 3½ IN UNDER THE TOP

MODESTY PANEL ¾"
STOPS 5⅞" ABOVE FLOOR

FRONT AT TOP

IF FREE-STANDING

CLAMP BAY — RAIL SET IN 4 IN
COVE STOPPED · 10 IN WIDE

PLAIN TEAK TOP
NO INSET — GRAIN LENGTHWAYS

MONITOR CLAMP BAY — 10 IN WIDE
UNDERSIDE CLEAR 4 IN IN FROM THE BACK EDGE

NOT TO SCALE · FROM FRONT RIGHT

PARTS OF THE DESK

READ BEFORE MAKING

1 Top — plain teak, reeded edge

Dimensions in feet and inches. Do not scale.

2 Plain stile at the kneehole — no bracket

THE PLAIN DESK WITH ITS HOLLOW CORNERS (owner, 7 Oct).

As AST-DR-031 — no carving, no corner mouldings;

3 Frieze drawer, push-to-open

reeded top edge, frieze, reeded rail and plinth —

but all four corners hollowed R 5⅞" again, top to bottom.

5 Hollow corner R 5⅞" — plain, no moulding

Outer stiles 7" wide to clear the hollow, so the outer

6 Pedestal — three drawers each side

drawers are a little narrower than on AST-DR-031.

7 Swan-neck handle + keyhole, every drawer

MONITOR CLAMP BAY at the back centre, as before.

Top 1⅝ in solid teak.

First-angle projection.

9 Modesty panel in kneehole

Particulars of the room

DESK (HOLLOW CORNERS) — GENERAL ARRANGEMENT

Front · End · Section · Plan · Back · Axo

1 — the plain desk with its four hollow corners back

PROJECT
A Study in Teak — Desk (Hollow Corners) — Gen…

SHEET
General arrangement — the whole sheet

DRAWING
AST-DR-045 · 1 of 24

each view follows at its own scale, pages 2 to 9

ALL DIMENSIONS IN FEET & INCHES. PRINT ON A3 AT 100% / “ACTUAL SIZE” — NOT “FIT TO PAGE” — AND CHECK THE SCALE BAR. DO NOT SCALE; WORK TO FIGURED DIMENSIONS. VERIFY ON SITE.

# FRONT ELEVATION

A

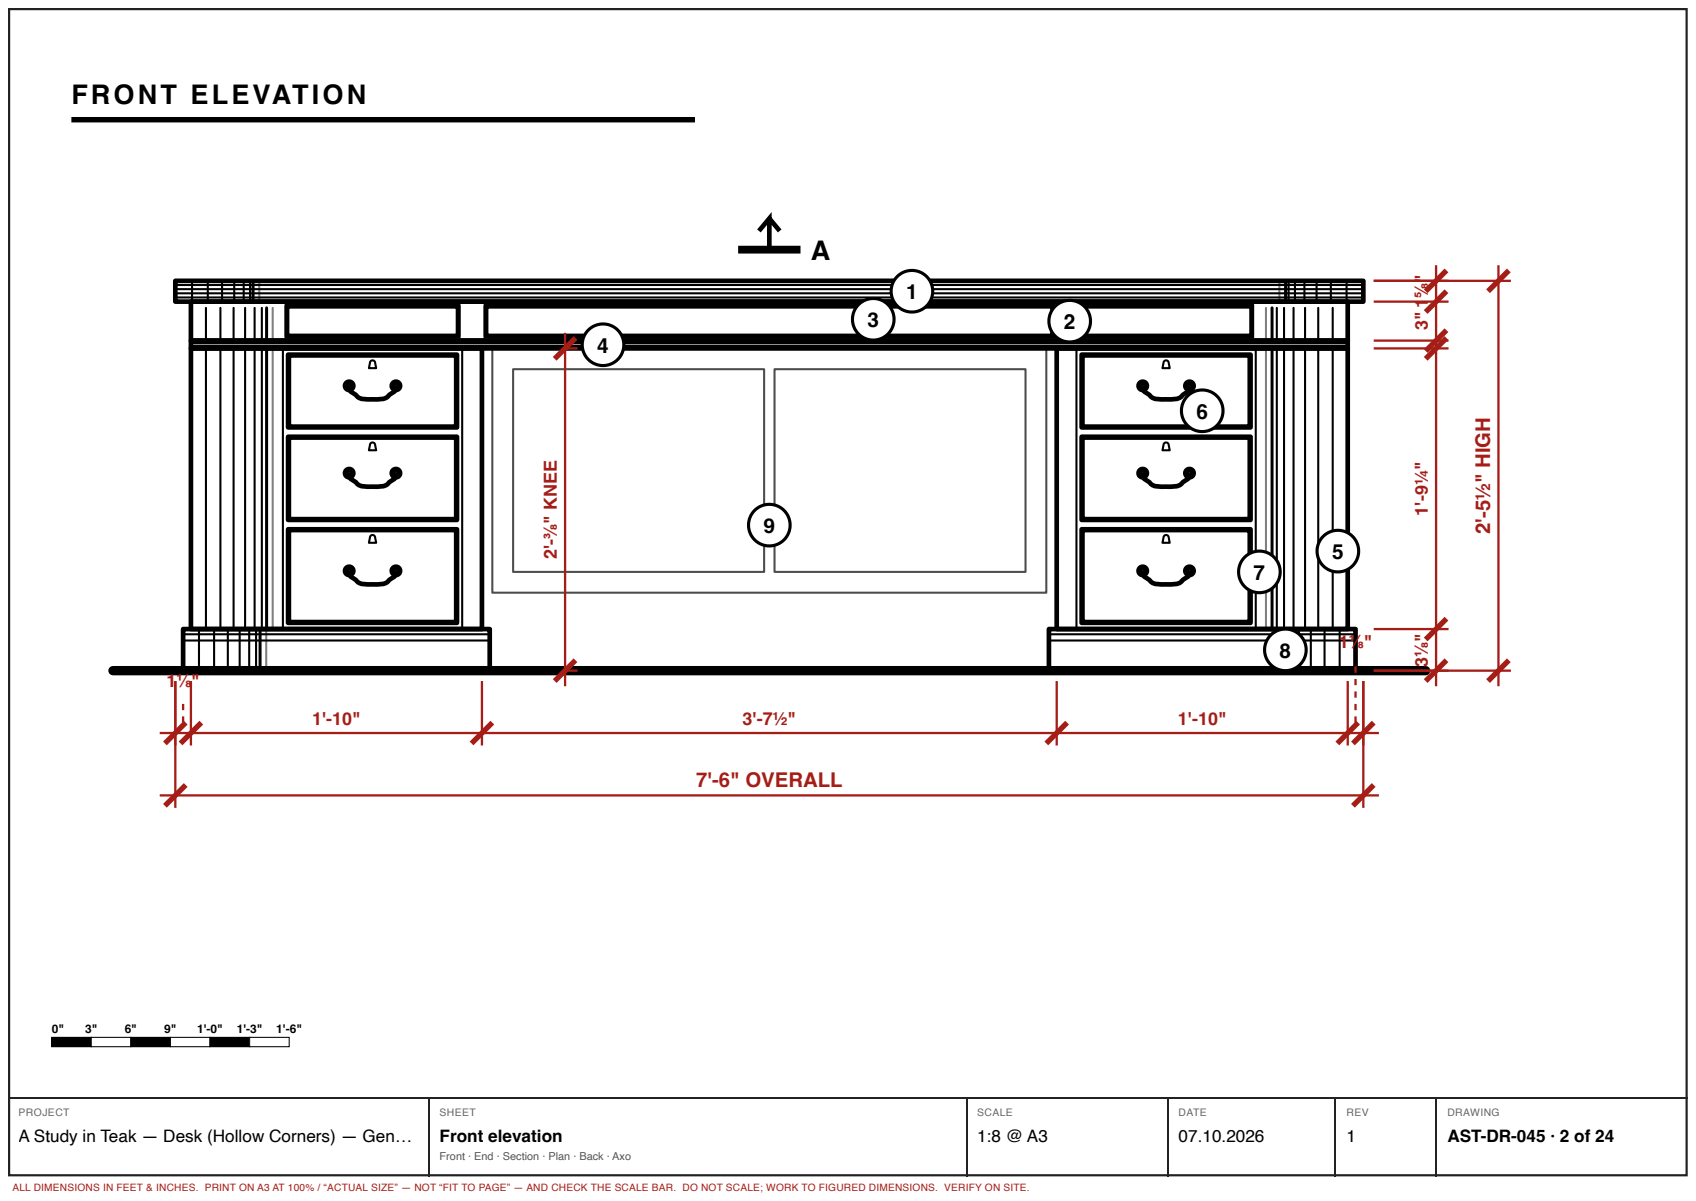
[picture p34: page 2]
7'-6" OVERALL; ½" HIG; Front elevation

A Study in Teak — Desk (Hollow Corners) — Gen…

AST-DR-045 · 2 of 24

Front · End · Section · Plan · Back · Axo

# LEFT END ELEVATION

# SCALE 1:8 (1½" = 1'-0") @ A3 · FRONT →

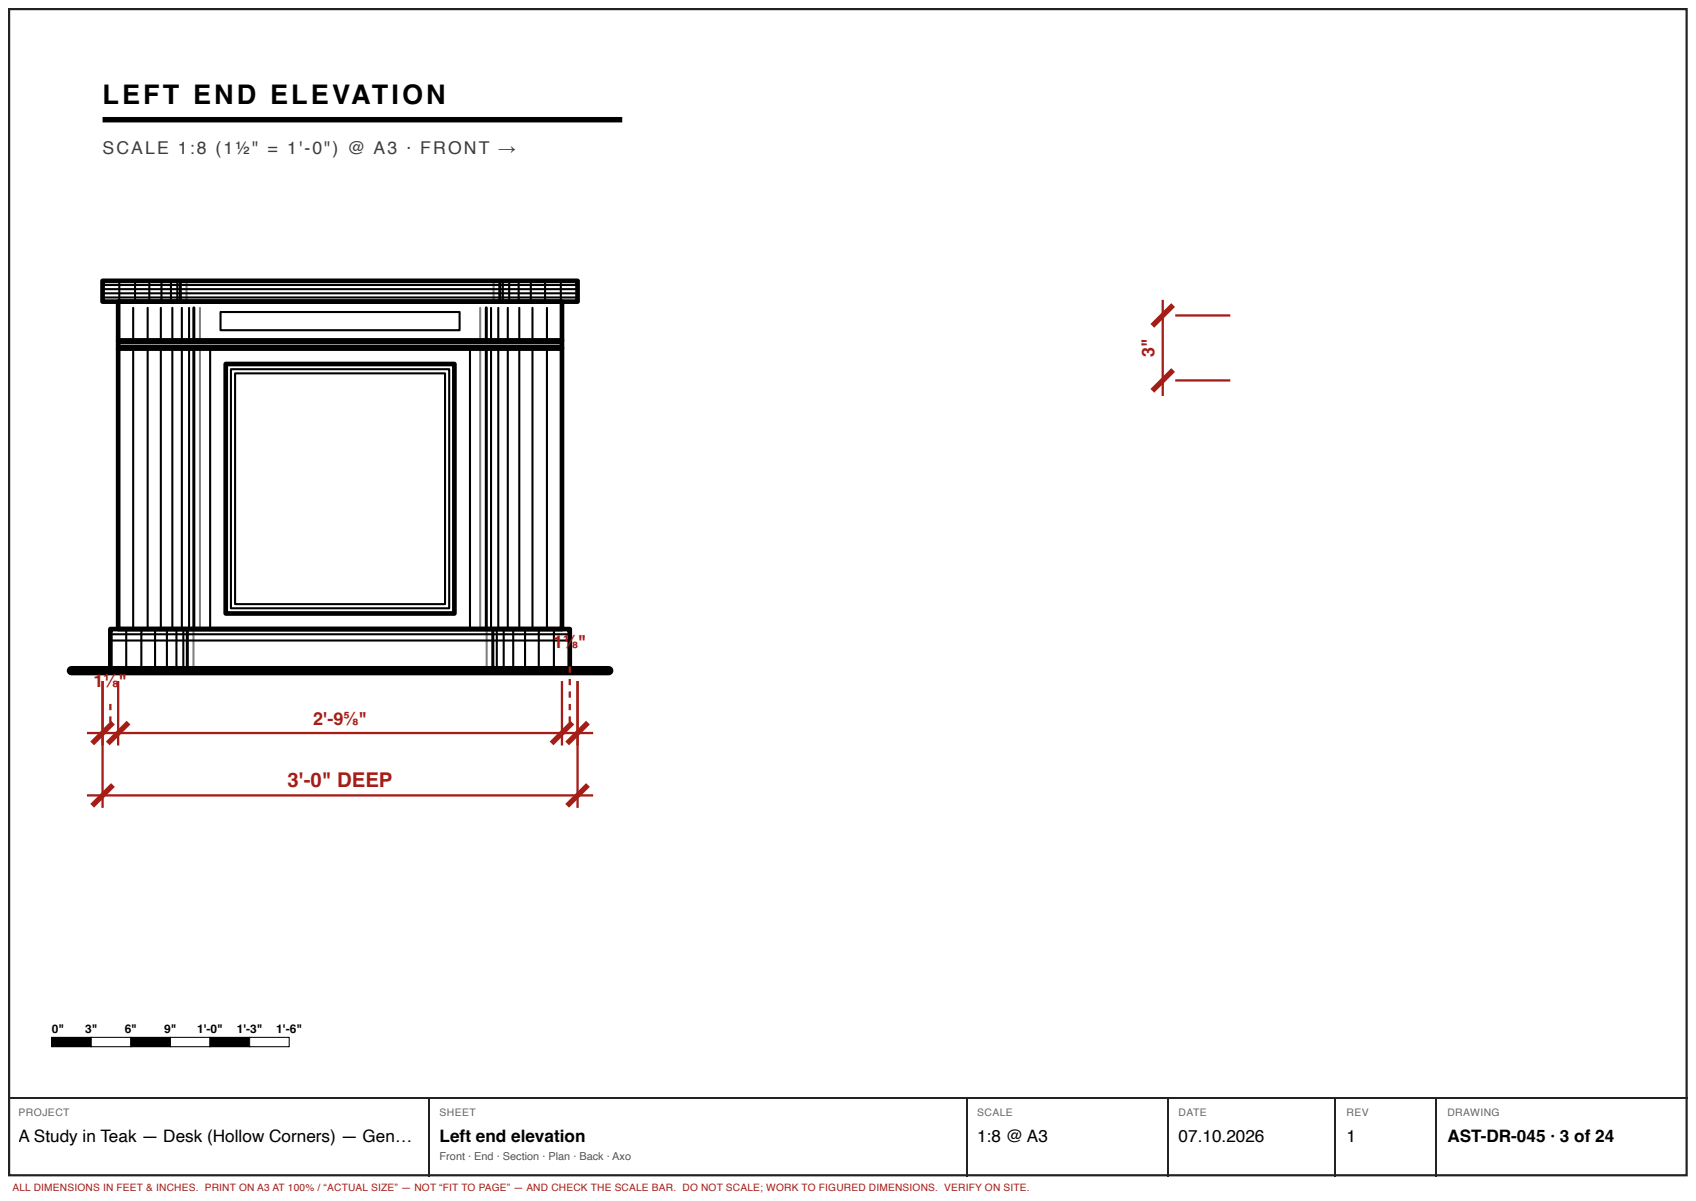
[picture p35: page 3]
3'-0" DEEP

A Study in Teak — Desk (Hollow Corners) — Gen…

Left end elevation

AST-DR-045 · 3 of 24

Front · End · Section · Plan · Back · Axo

# SECTION A–A

## SCALE 1:5 @ A3 · THROUGH KNEEHOLE · FRONT ←

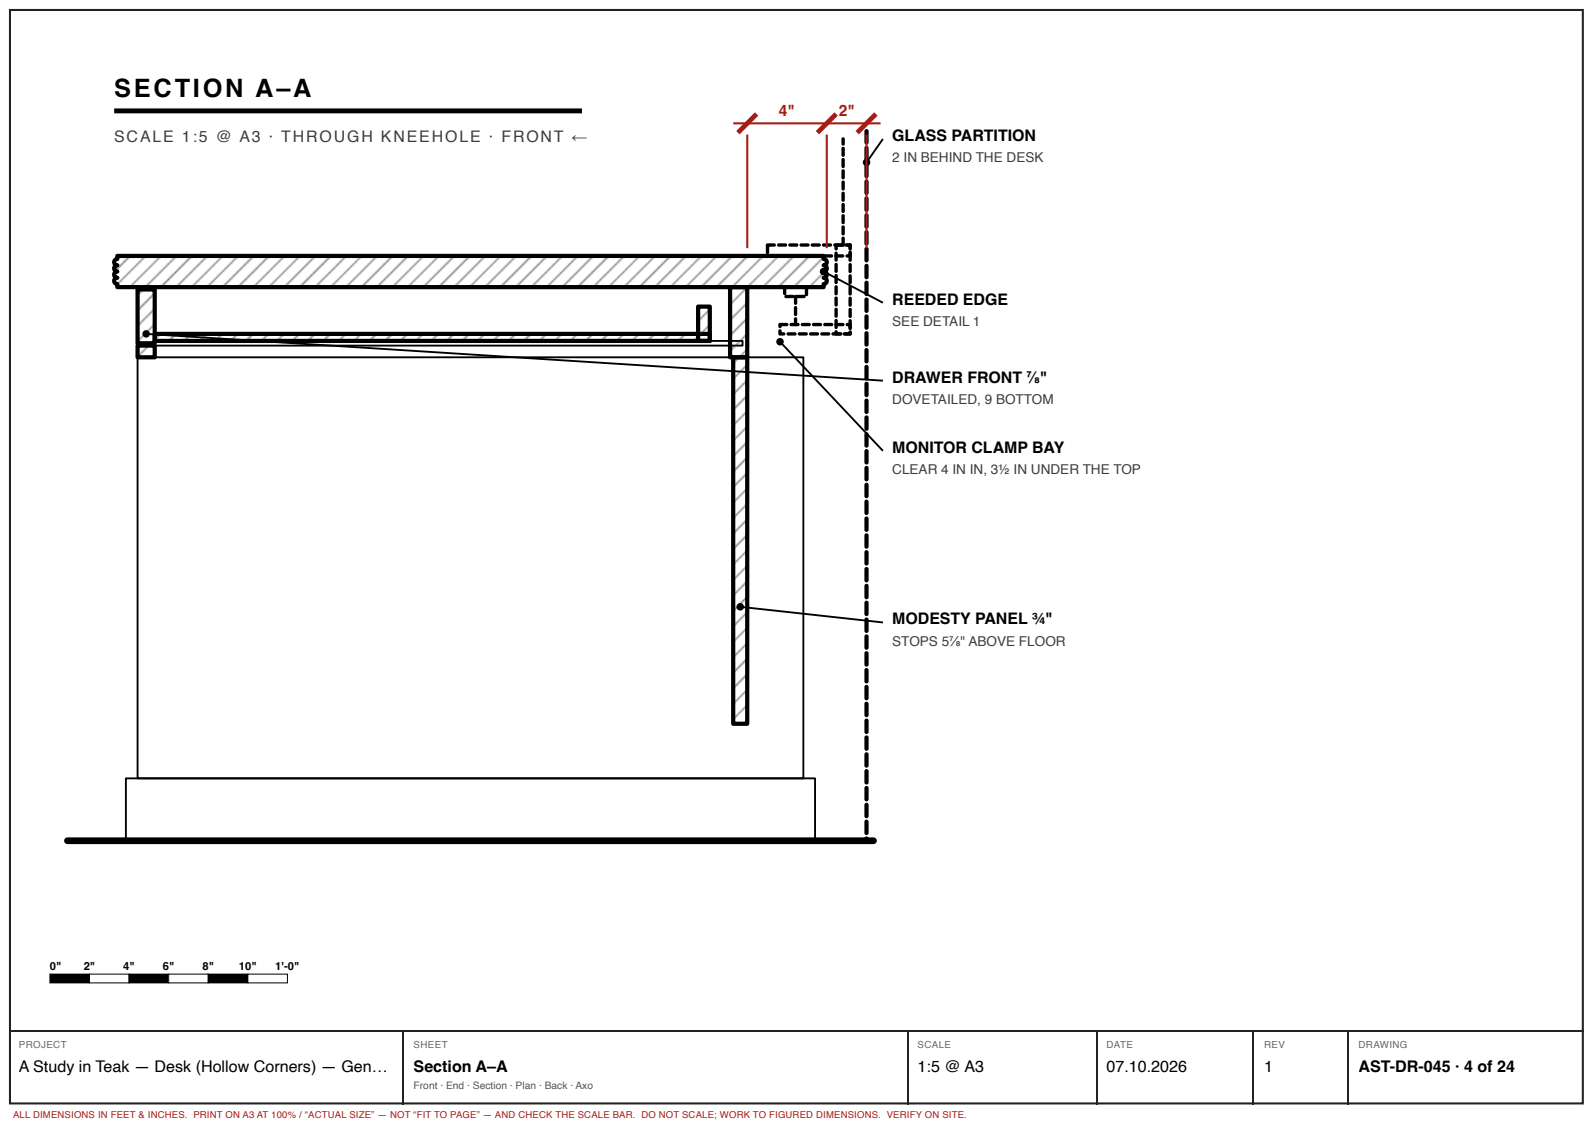
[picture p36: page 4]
DRAWER FRONT ⅞"; DOVETAILED, 9 BOTTOM; REEDED EDGE; SEE DETAIL 1; Section A–A

GLASS PARTITION
2 IN BEHIND THE DESK

MONITOR CLAMP BAY
CLEAR 4 IN IN, 3½ IN UNDER THE TOP

MODESTY PANEL ¾"
STOPS 5⅞" ABOVE FLOOR

A Study in Teak — Desk (Hollow Corners) — Gen…

AST-DR-045 · 4 of 24

Front · End · Section · Plan · Back · Axo

# PLAN

# SCALE 1:8 (1½" = 1'-0") @ A3 · FRONT AT TOP

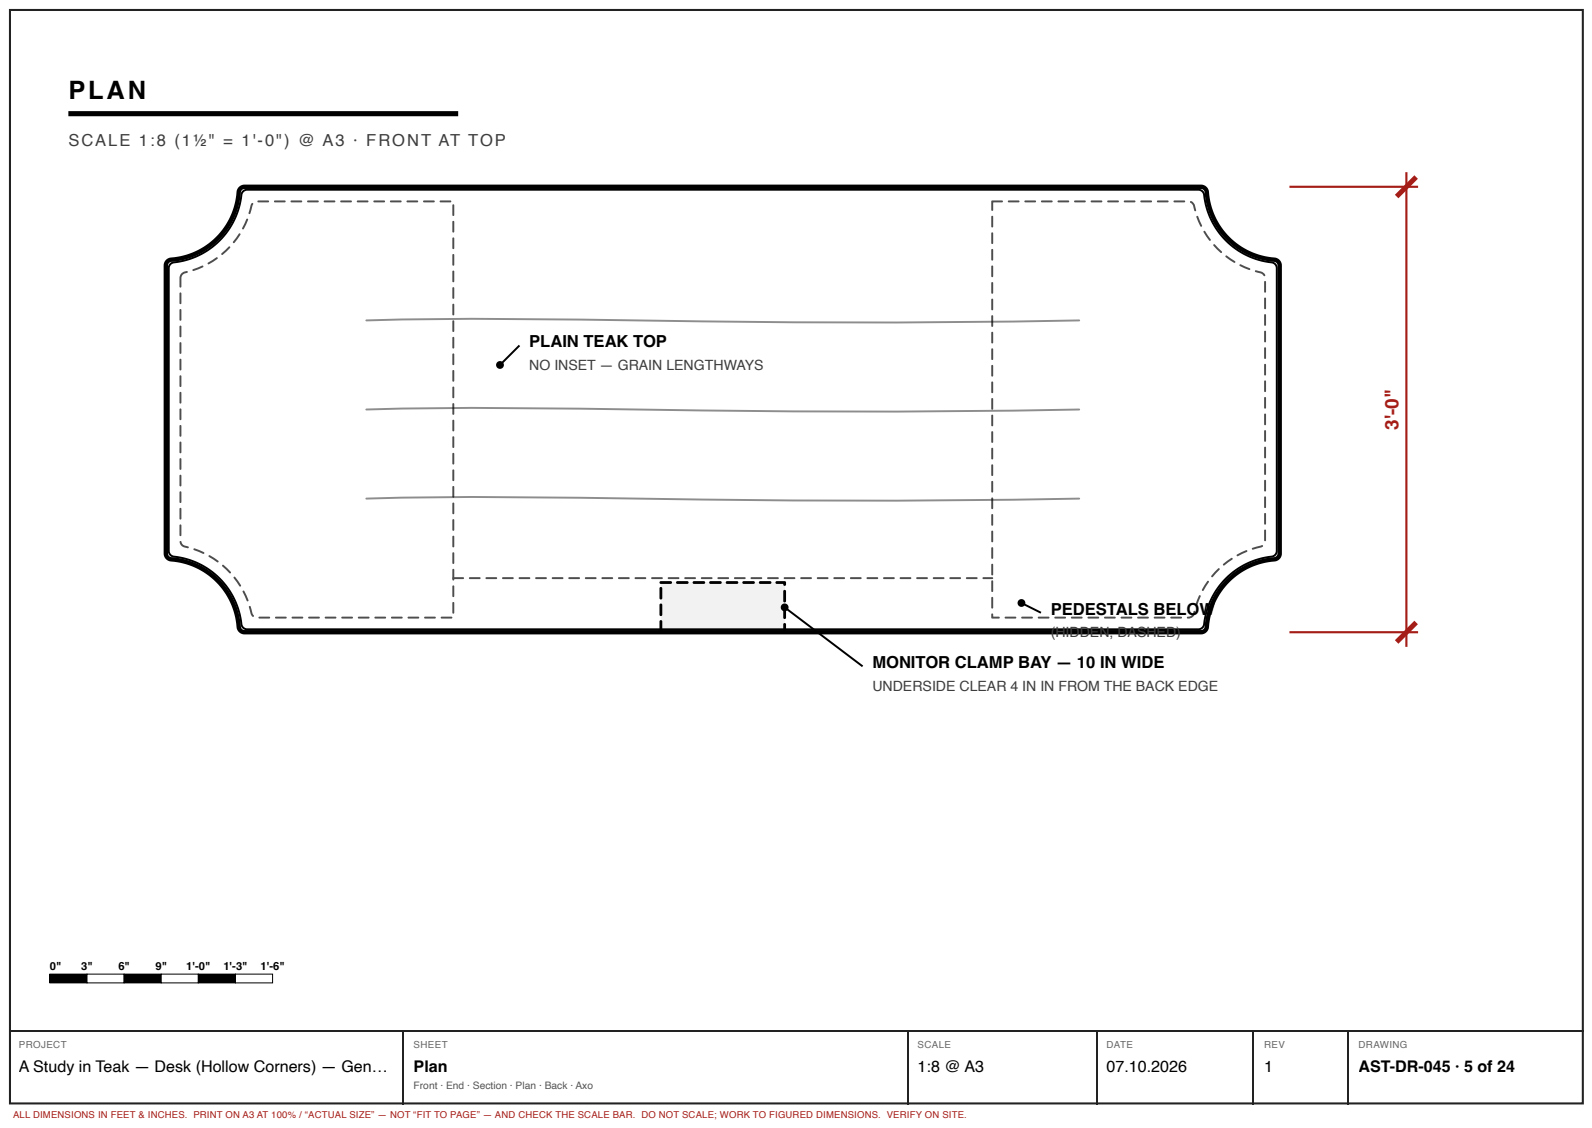
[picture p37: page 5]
PEDESTALS BELOW; (HIDDEN, DASHED); Plan

PLAIN TEAK TOP
NO INSET — GRAIN LENGTHWAYS

MONITOR CLAMP BAY — 10 IN WIDE
UNDERSIDE CLEAR 4 IN IN FROM THE BACK EDGE

A Study in Teak — Desk (Hollow Corners) — Gen…

AST-DR-045 · 5 of 24

Front · End · Section · Plan · Back · Axo

# BACK ELEVATION

# SCALE 1:8 (1½" = 1'-0") @ A3 · IF FREE-STANDING

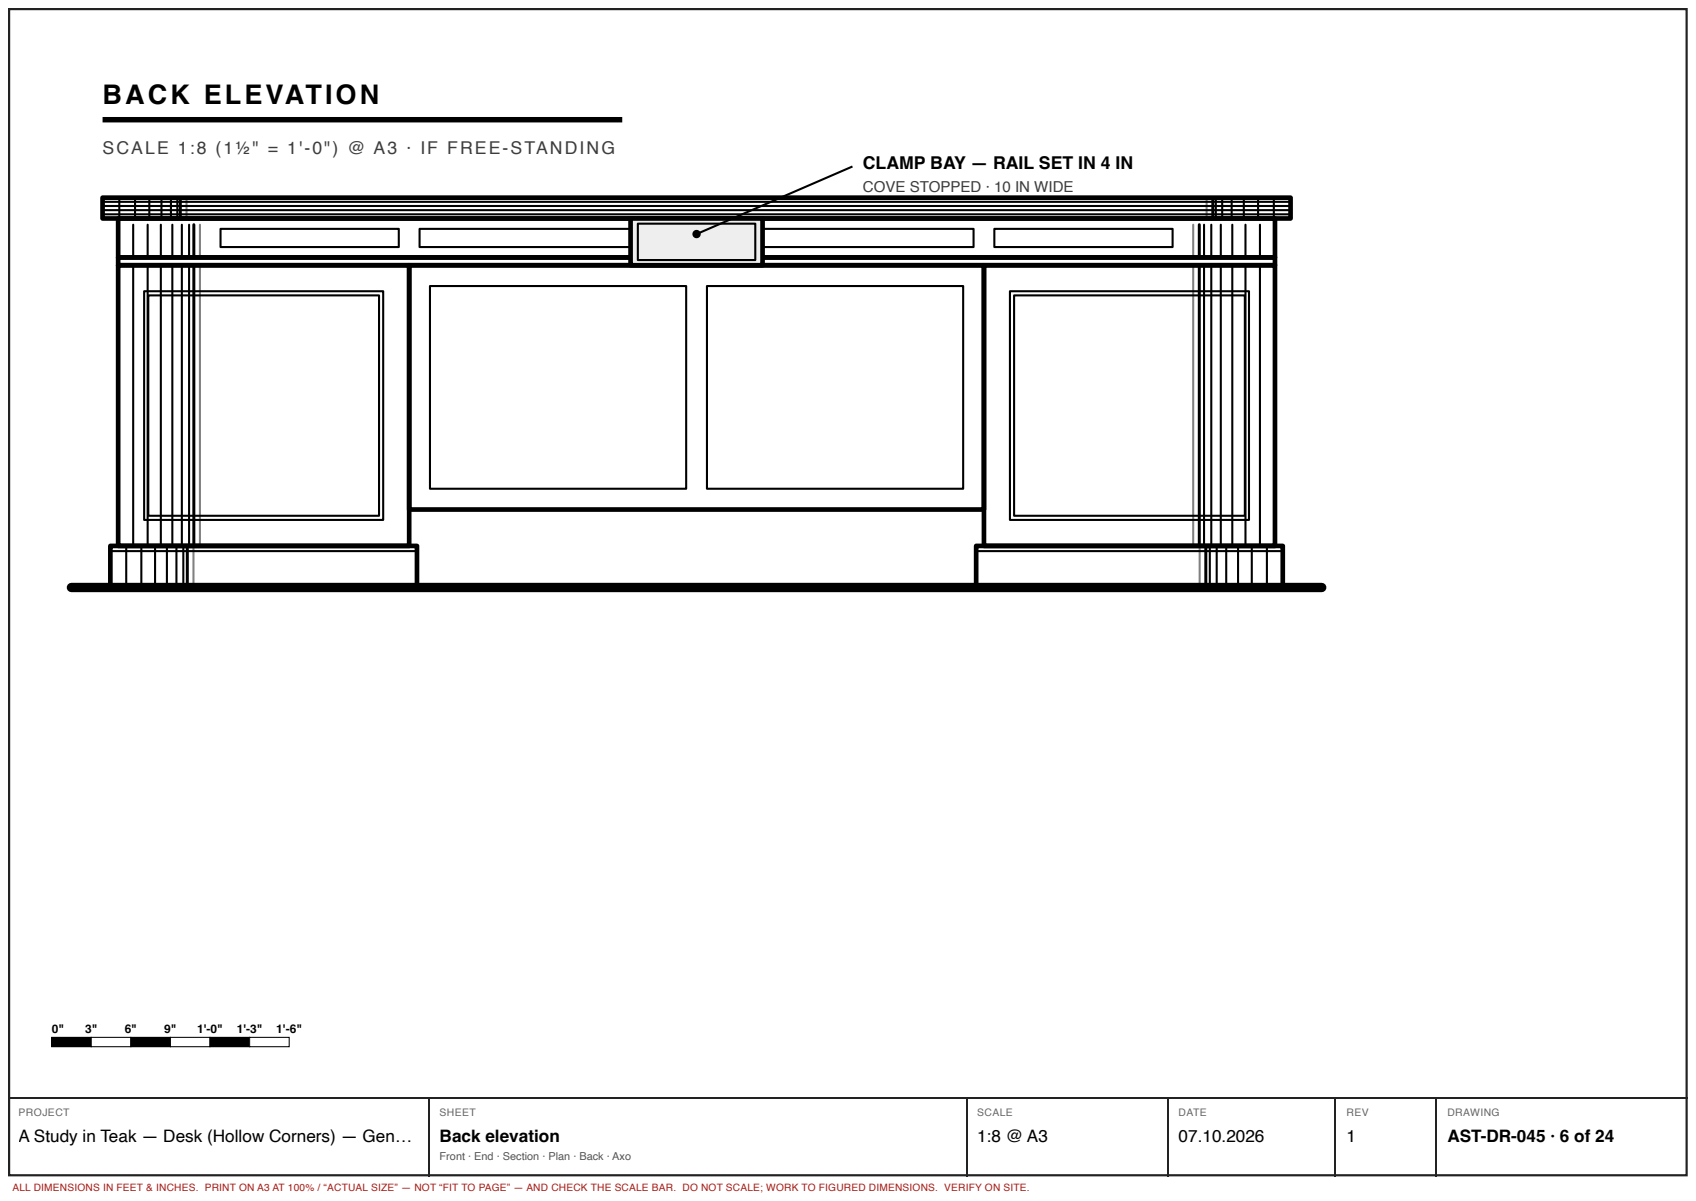
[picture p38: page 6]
Back elevation

CLAMP BAY — RAIL SET IN 4 IN
COVE STOPPED · 10 IN WIDE

A Study in Teak — Desk (Hollow Corners) — Gen…

AST-DR-045 · 6 of 24

Front · End · Section · Plan · Back · Axo

# AXONOMETRIC

# NOT TO SCALE · NOT TO SCALE · FROM FRONT RIGHT

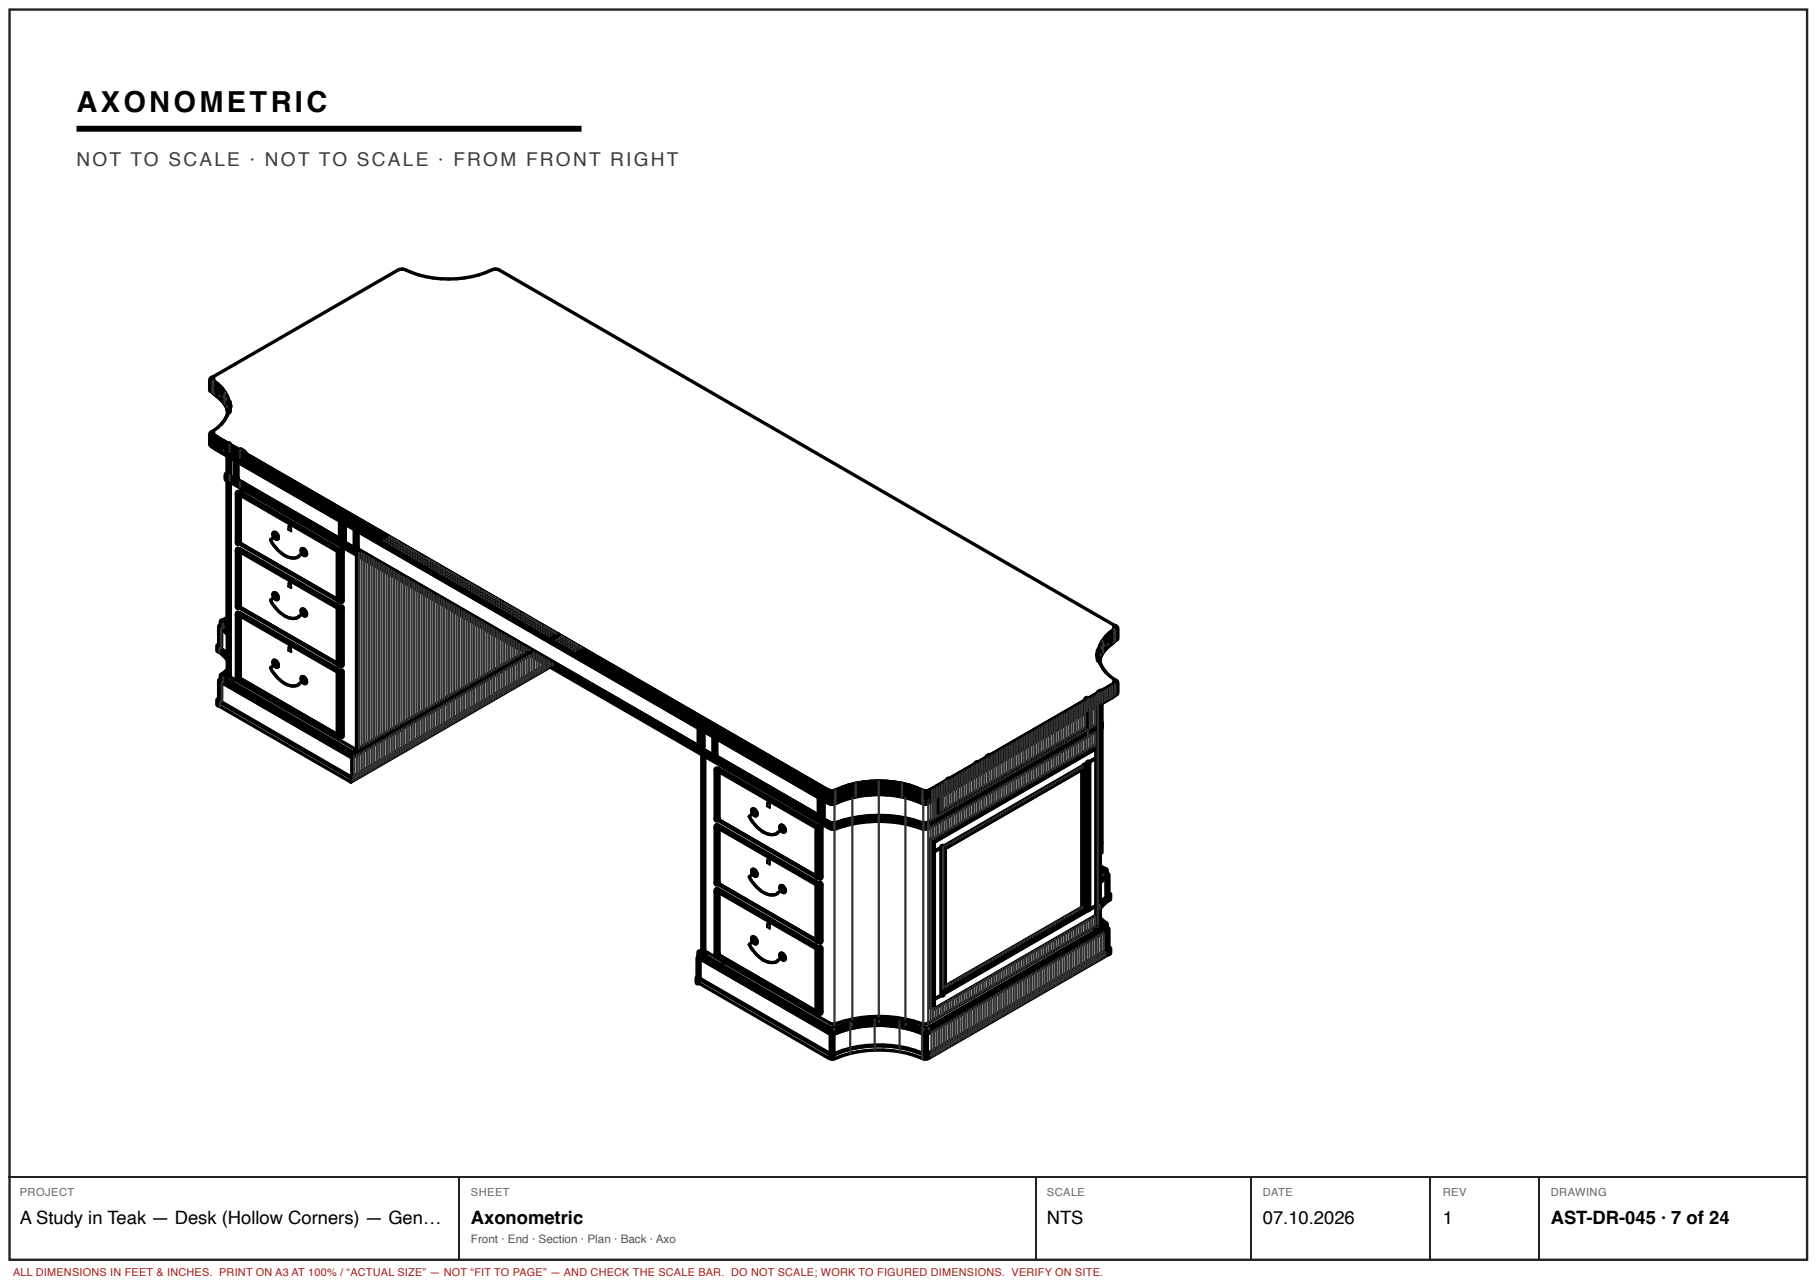
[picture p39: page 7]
Axonometric

A Study in Teak — Desk (Hollow Corners) — Gen…

AST-DR-045 · 7 of 24

Front · End · Section · Plan · Back · Axo

# KEY

# PARTS OF THE DESK

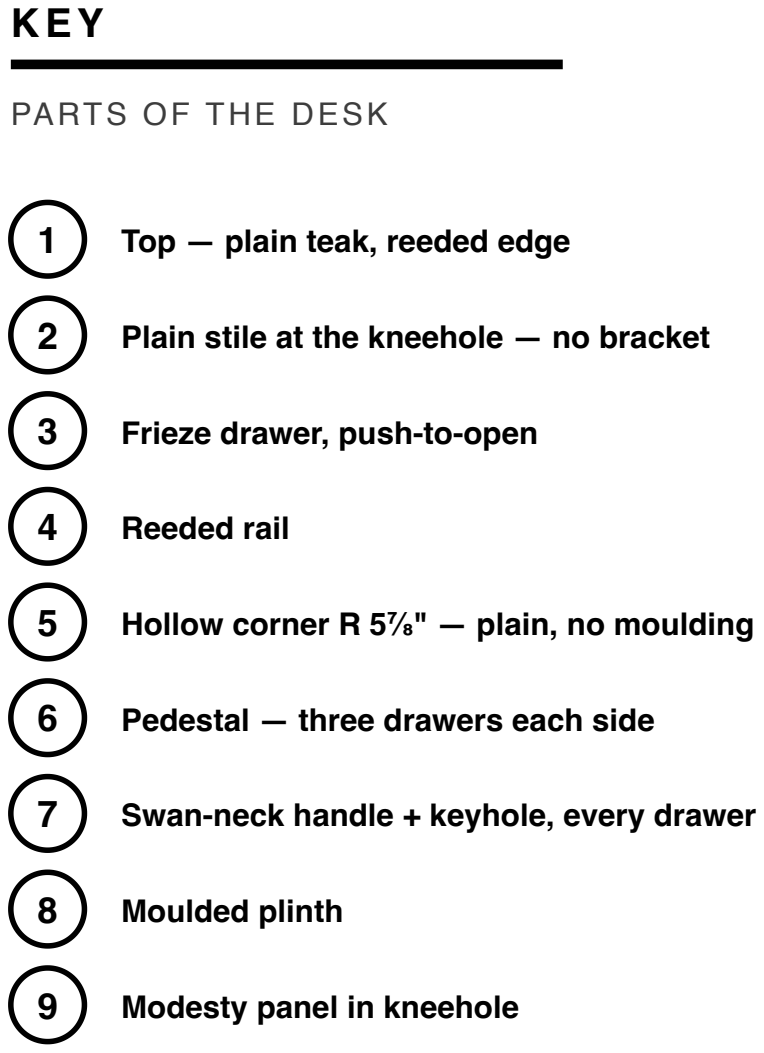
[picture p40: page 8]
4 Reeded rail; 8 Moulded plinth; Key

1 Top — plain teak, reeded edge

2 Plain stile at the kneehole — no bracket

3 Frieze drawer, push-to-open

5 Hollow corner R 5⅞" — plain, no moulding

6 Pedestal — three drawers each side

7 Swan-neck handle + keyhole, every drawer

9 Modesty panel in kneehole

A Study in Teak — Desk (Hollow Corners) — Gen…

AST-DR-045 · 8 of 24

Front · End · Section · Plan · Back · Axo

# NOTES

# READ BEFORE MAKING

Dimensions in feet and inches. Do not scale.

THE PLAIN DESK WITH ITS HOLLOW CORNERS (owner, 7 Oct).

As AST-DR-031 — no carving, no corner mouldings;

# reeded top edge, frieze, reeded rail and plinth —

but all four corners hollowed R 5⅞" again, top to bottom.

# Outer stiles 7" wide to clear the hollow, so the outer

drawers are a little narrower than on AST-DR-031.

MONITOR CLAMP BAY at the back centre, as before.

Top 1⅝ in solid teak.

First-angle projection.

## A Study in Teak — Desk (Hollow Corners) — Gen…

## Notes

Front · End · Section · Plan · Back · Axo

## AST-DR-045 · 9 of 24

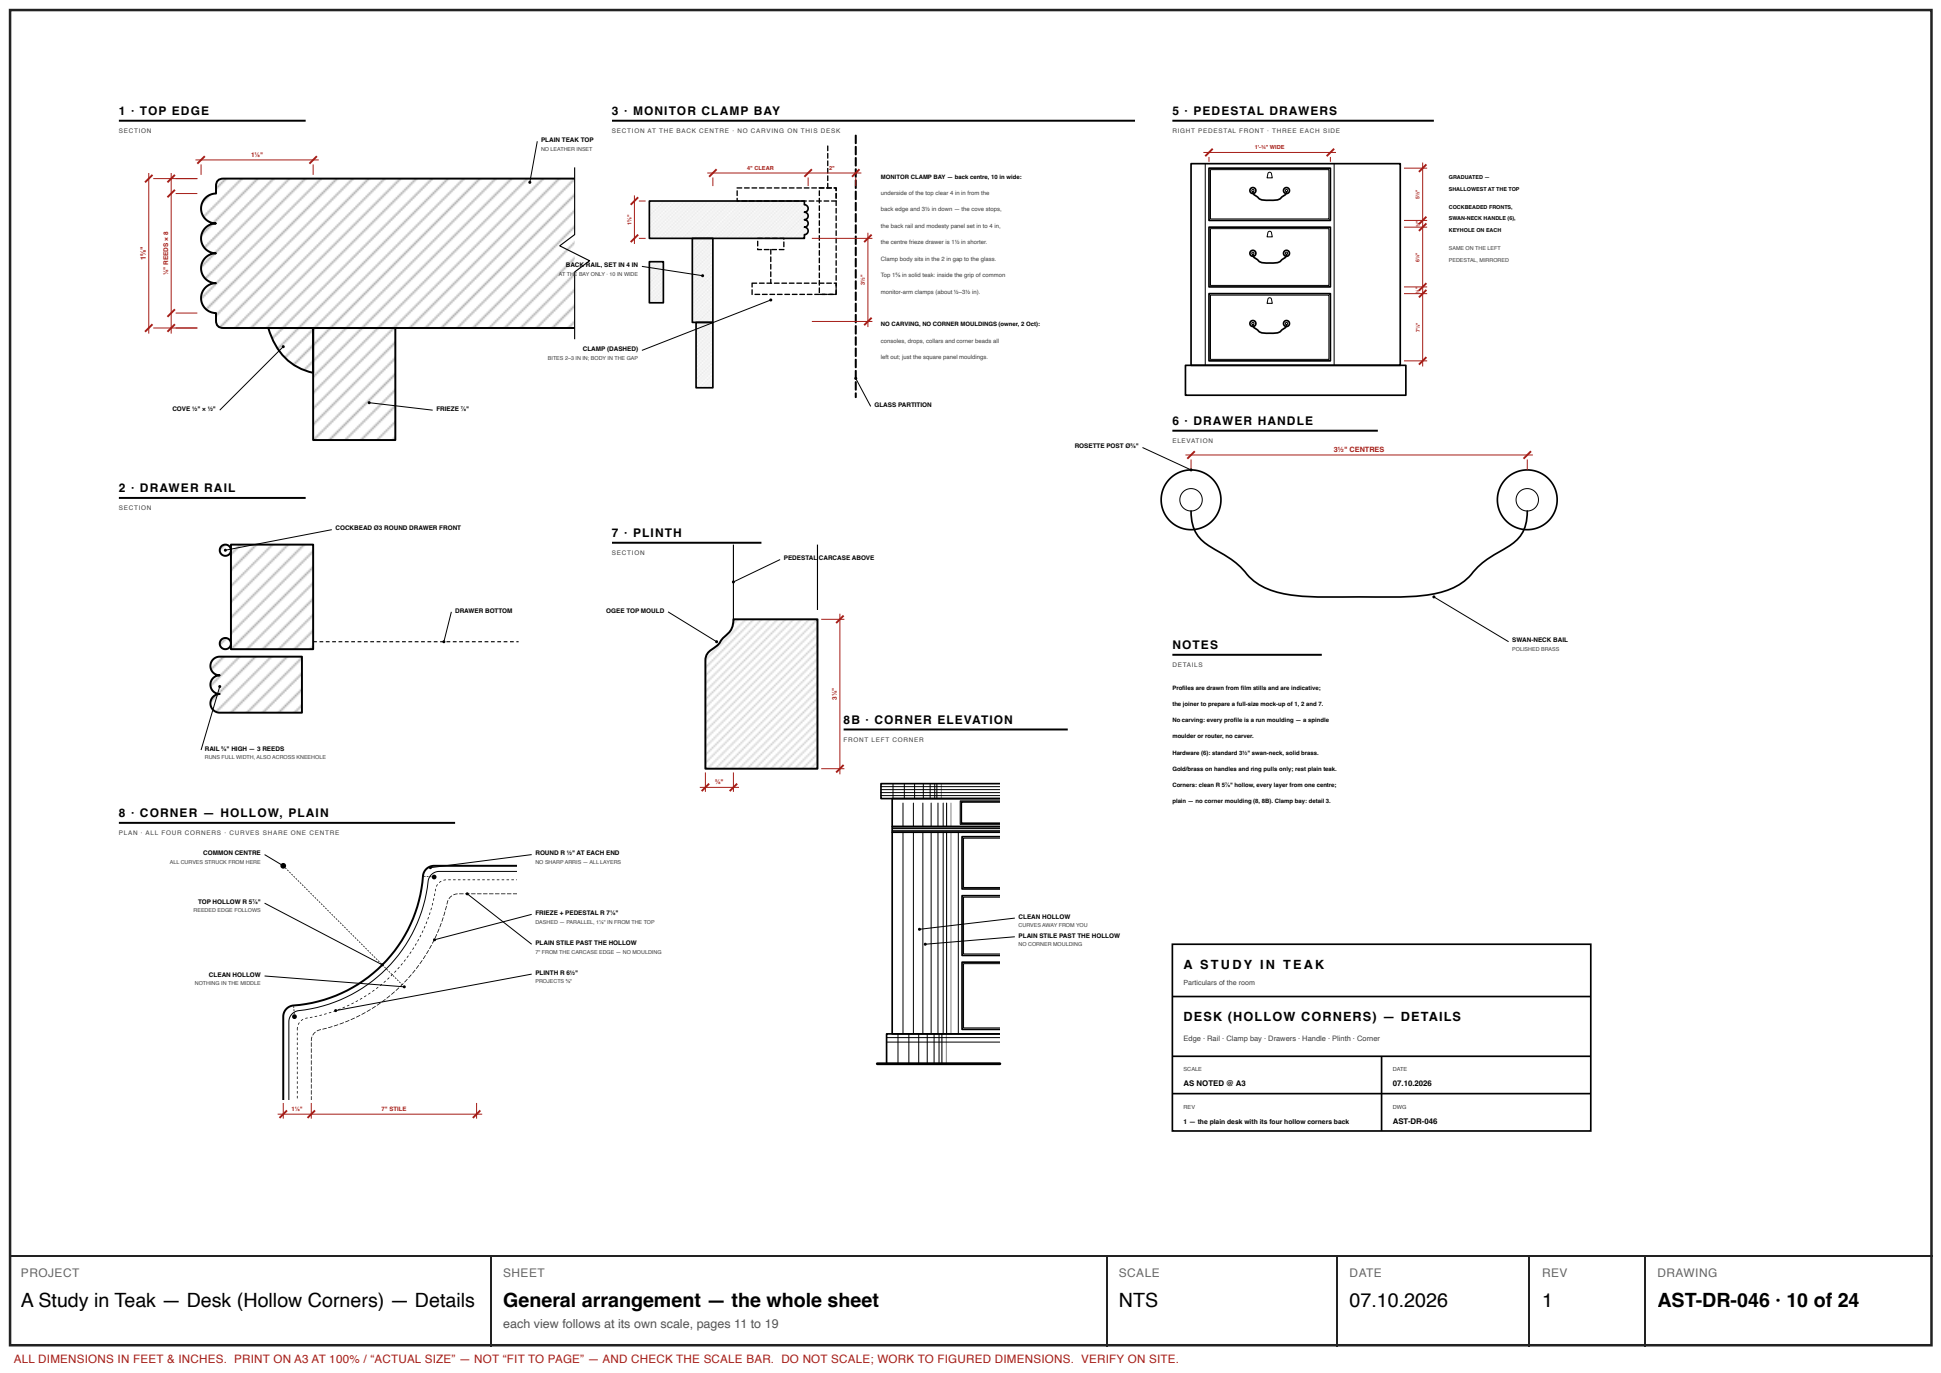
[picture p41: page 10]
1 · TOP EDGE; SECTION; ⅛" REEDS × 8; COVE ½" × ½"; FRIEZE ⅞"; 2 · DRAWER RAIL; DRAWER BOTTOM; 4" CLEAR; CLAMP (DASHED); GLASS PARTITION; 5 · PEDESTAL DRAWERS; 1'-¾" WIDE; GRADUATED —; COCKBEADED FRONTS,; PEDESTAL, MIRRORED; 6 · DRAWER HANDLE; ELEVATION; 3½" CENTRES; 7 · PLINTH; COMMON CENTRE; TOP HOLLOW R 5⅞"; PLINTH R 6½"; PROJECTS ⅝"; 7" STILE; 8B · CORNER ELEVATION; NOTES; DETAILS; SCALE; AS NOTED @ A3; DATE; REV; DWG; AST-DR-046

3 · MONITOR CLAMP BAY

PLAIN TEAK TOP
NO LEATHER INSET

SECTION AT THE BACK CENTRE · NO CARVING ON THIS DESK

RIGHT PEDESTAL FRONT · THREE EACH SIDE

MONITOR CLAMP BAY — back centre, 10 in wide:

underside of the top clear 4 in in from the

SHALLOWEST AT THE TOP

back edge and 3½ in down — the cove stops,

SWAN-NECK HANDLE (6),

the back rail and modesty panel set in to 4 in,

KEYHOLE ON EACH

the centre frieze drawer is 1½ in shorter.

SAME ON THE LEFT

Clamp body sits in the 2 in gap to the glass.

BACK RAIL, SET IN 4 IN
AT THE BAY ONLY · 10 IN WIDE

Top 1⅝ in solid teak: inside the grip of common

monitor-arm clamps (about ½–3½ in).

NO CARVING, NO CORNER MOULDINGS (owner, 2 Oct):

consoles, drops, collars and corner beads all

BITES 2–3 IN IN; BODY IN THE GAP

left out; just the square panel mouldings.

ROSETTE POST Ø⅝"

COCKBEAD Ø3 ROUND DRAWER FRONT

PEDESTAL CARCASE ABOVE

OGEE TOP MOULD

SWAN-NECK BAIL
POLISHED BRASS

Profiles are drawn from film stills and are indicative;

the joiner to prepare a full-size mock-up of 1, 2 and 7.

No carving: every profile is a run moulding — a spindle

FRONT LEFT CORNER

moulder or router, no carver.

RAIL ⅝" HIGH — 3 REEDS

RUNS FULL WIDTH, ALSO ACROSS KNEEHOLE

Hardware (6): standard 3½" swan-neck, solid brass.

Gold/brass on handles and ring pulls only; rest plain teak.

Corners: clean R 5⅞" hollow, every layer from one centre;

8 · CORNER — HOLLOW, PLAIN

plain — no corner moulding (8, 8B). Clamp bay: detail 3.

PLAN · ALL FOUR CORNERS · CURVES SHARE ONE CENTRE

ROUND R ½" AT EACH END
NO SHARP ARRIS — ALL LAYERS

ALL CURVES STRUCK FROM HERE

REEDED EDGE FOLLOWS

FRIEZE + PEDESTAL R 7⅛"
DASHED — PARALLEL, 1⅛" IN FROM THE TOP

CLEAN HOLLOW
CURVES AWAY FROM YOU
PLAIN STILE PAST THE HOLLOW
NO CORNER MOULDING

7" FROM THE CARCASE EDGE — NO MOULDING

NOTHING IN THE MIDDLE

Particulars of the room

DESK (HOLLOW CORNERS) — DETAILS

Edge · Rail · Clamp bay · Drawers · Handle · Plinth · Corner

1 — the plain desk with its four hollow corners back

A Study in Teak — Desk (Hollow Corners) — Details

General arrangement — the whole sheet

AST-DR-046 · 10 of 24

each view follows at its own scale, pages 11 to 19

### 1 · TOP EDGE

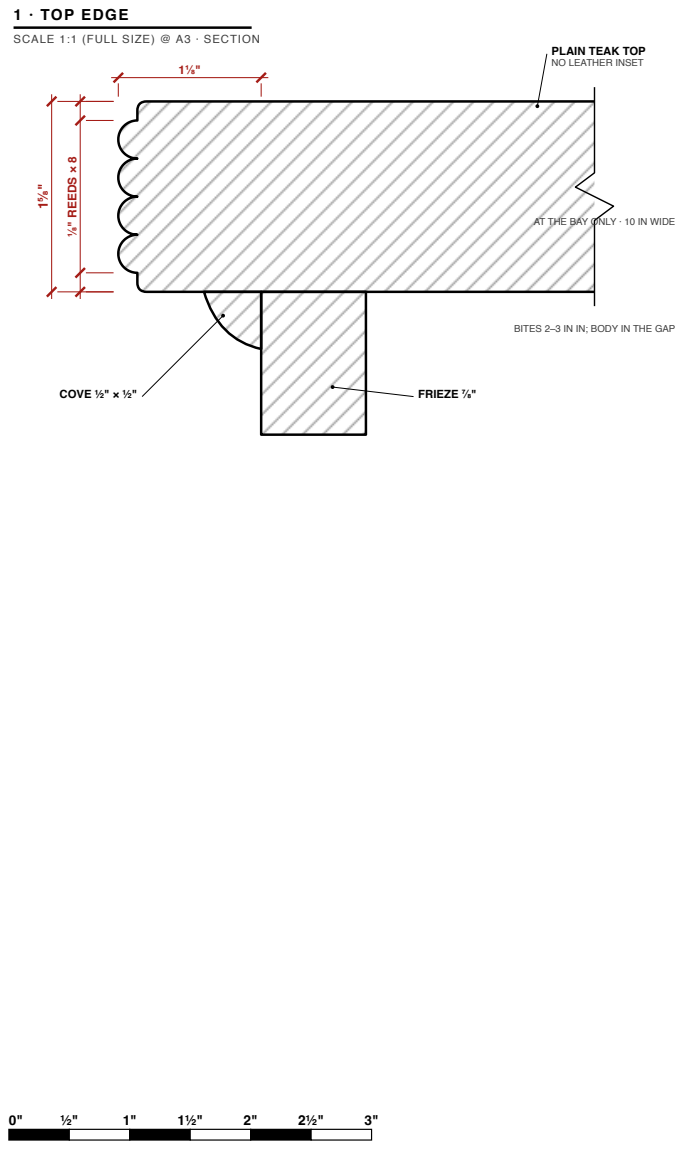
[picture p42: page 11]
⅛" REEDS × 8; COVE ½" × ½"; FRIEZE ⅞"; 1 · top edge

SCALE 1:1 (FULL SIZE) @ A3 · SECTION

PLAIN TEAK TOP
NO LEATHER INSET

AT THE BAY ONLY · 10 IN WIDE

BITES 2–3 IN IN; BODY IN THE GAP

AST-DR-046 · 11 of 24

Edge · Rail · Clamp bay · Drawers · Handle · Plinth · Corner

# 3 · MONITOR CLAMP BAY

## SCALE 1:2 (6" = 1'-0") @ A3 · SECTION AT THE BACK CENTRE · NO CARVING ON THIS DESK

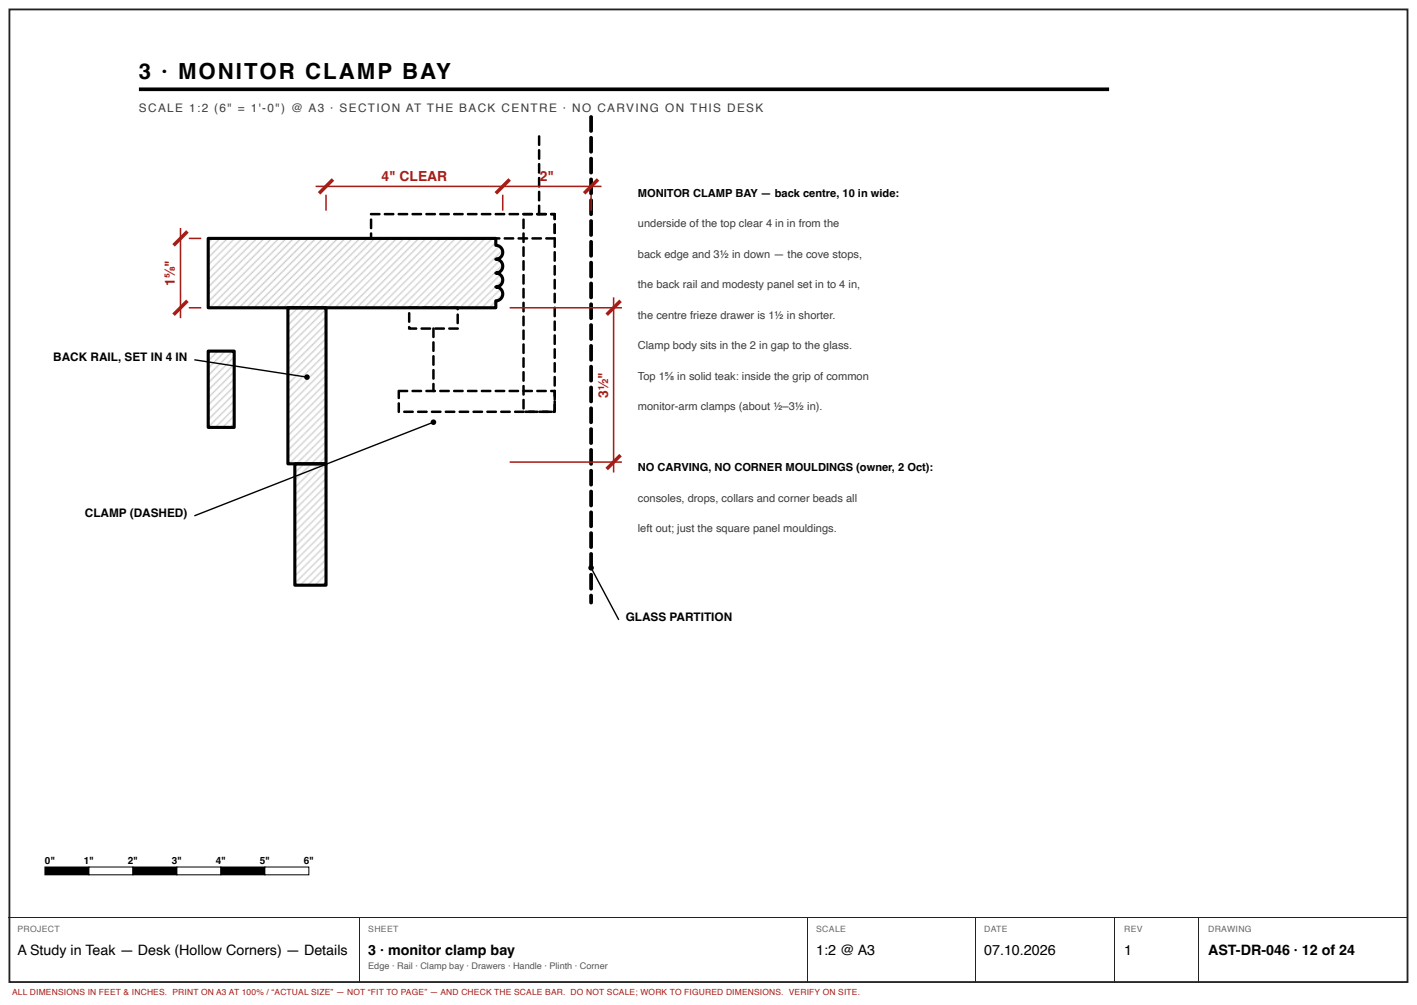
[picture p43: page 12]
4" CLEAR; CLAMP (DASHED); GLASS PARTITION

MONITOR CLAMP BAY — back centre, 10 in wide:

underside of the top clear 4 in in from the

back edge and 3½ in down — the cove stops,

the back rail and modesty panel set in to 4 in,

the centre frieze drawer is 1½ in shorter.

Clamp body sits in the 2 in gap to the glass.

BACK RAIL, SET IN 4 IN

Top 1⅝ in solid teak: inside the grip of common

monitor-arm clamps (about ½–3½ in).

NO CARVING, NO CORNER MOULDINGS (owner, 2 Oct):

consoles, drops, collars and corner beads all

left out; just the square panel mouldings.

3 · monitor clamp bay

AST-DR-046 · 12 of 24

Edge · Rail · Clamp bay · Drawers · Handle · Plinth · Corner

# 5 · PEDESTAL DRAWERS

# SCALE 1:4 (3" = 1'-0") @ A3 · RIGHT PEDESTAL FRONT · THREE EACH SIDE

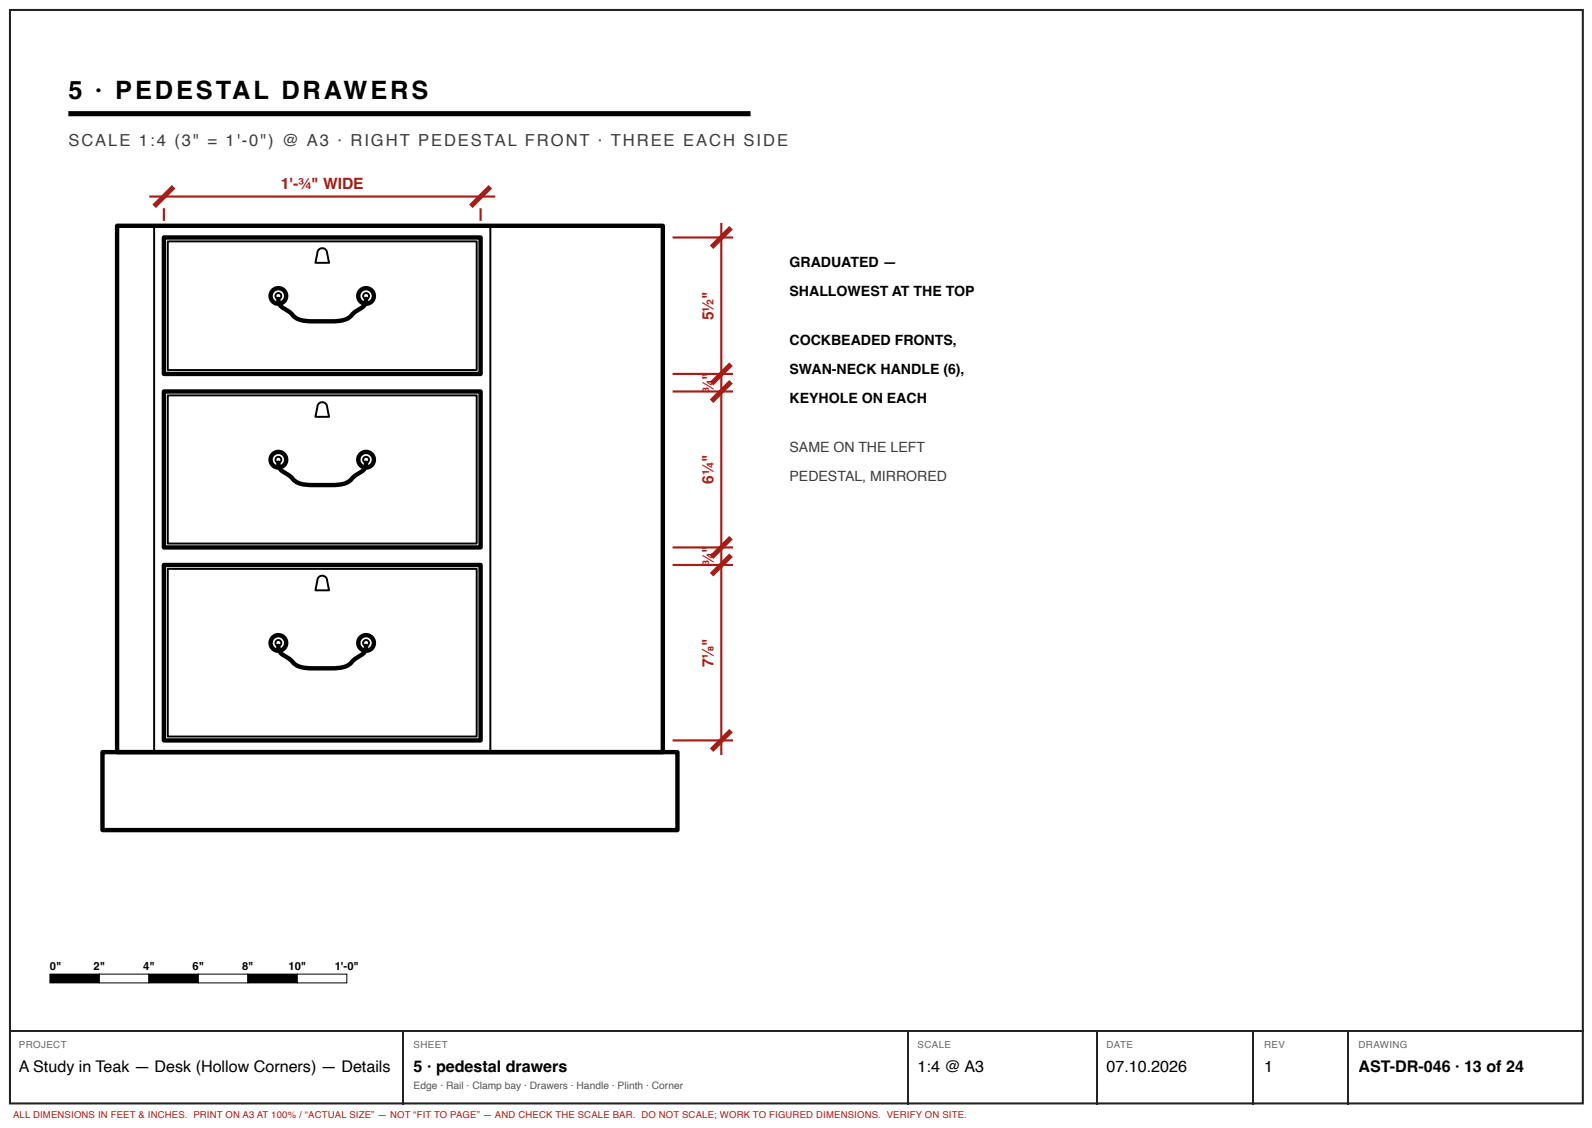
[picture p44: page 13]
1'-¾" WIDE; GRADUATED —; COCKBEADED FRONTS,; PEDESTAL, MIRRORED; 5 · pedestal drawers

SHALLOWEST AT THE TOP

SWAN-NECK HANDLE (6),

KEYHOLE ON EACH

SAME ON THE LEFT

AST-DR-046 · 13 of 24

Edge · Rail · Clamp bay · Drawers · Handle · Plinth · Corner

### 2 · DRAWER RAIL

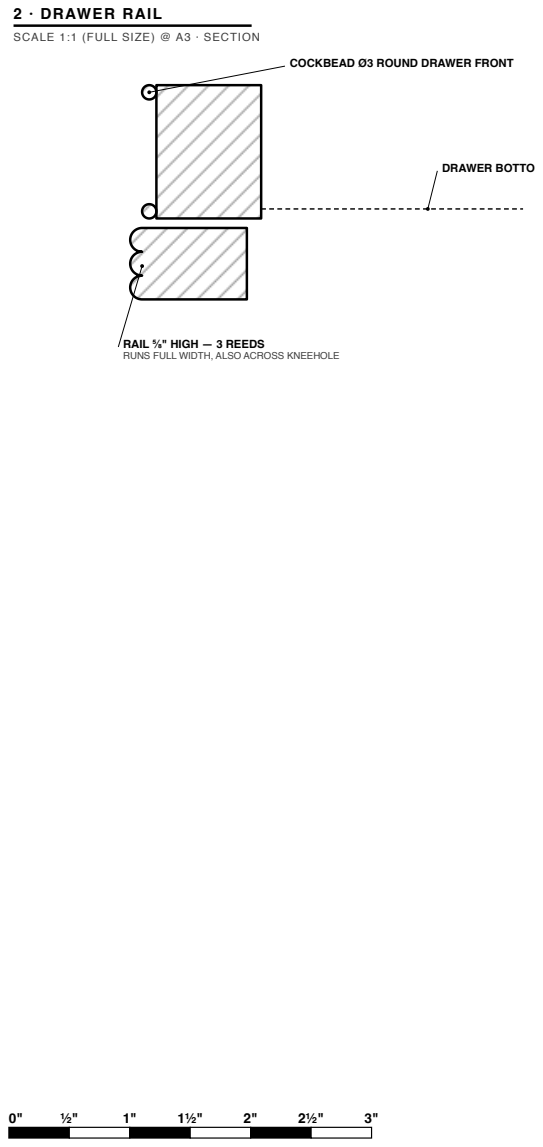
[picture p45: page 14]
DRAWER BOTTO; 2 · drawer rail

SCALE 1:1 (FULL SIZE) @ A3 · SECTION

COCKBEAD Ø3 ROUND DRAWER FRONT

RAIL ⅝" HIGH — 3 REEDS
RUNS FULL WIDTH, ALSO ACROSS KNEEHOLE

AST-DR-046 · 14 of 24

Edge · Rail · Clamp bay · Drawers · Handle · Plinth · Corner

### 6 · DRAWER HANDLE

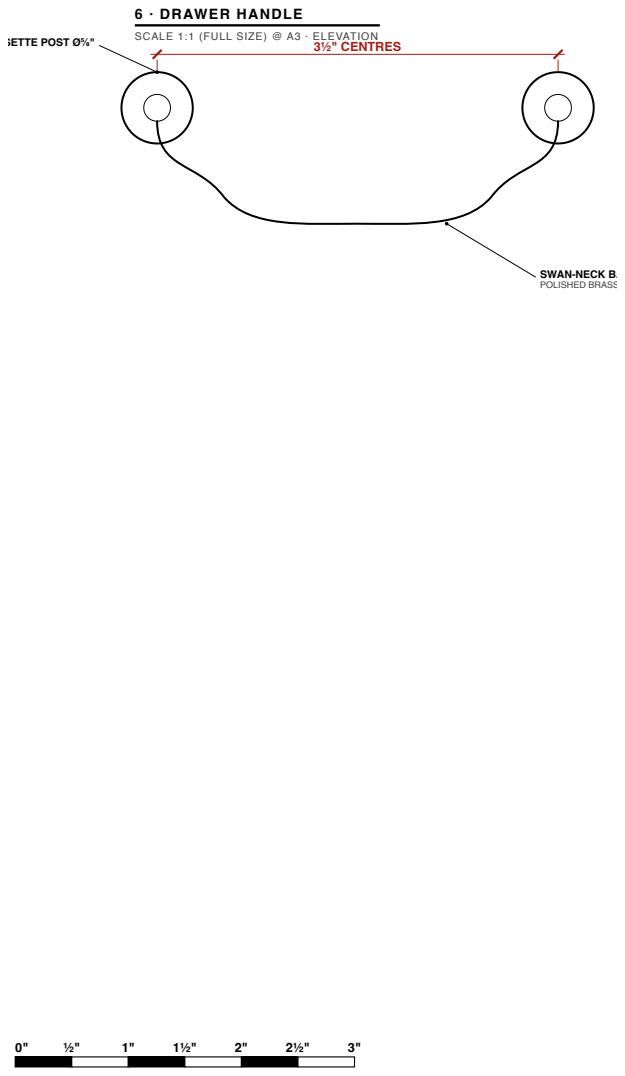
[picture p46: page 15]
3½" CENTRES; 6 · drawer handle

SETTE POST Ø⅝"

SCALE 1:1 (FULL SIZE) @ A3 · ELEVATION

SWAN-NECK BA
POLISHED BRASS

AST-DR-046 · 15 of 24

Edge · Rail · Clamp bay · Drawers · Handle · Plinth · Corner

# 7 · PLINTH

## SCALE 1:1 (FULL SIZE) @ A3 · SECTION

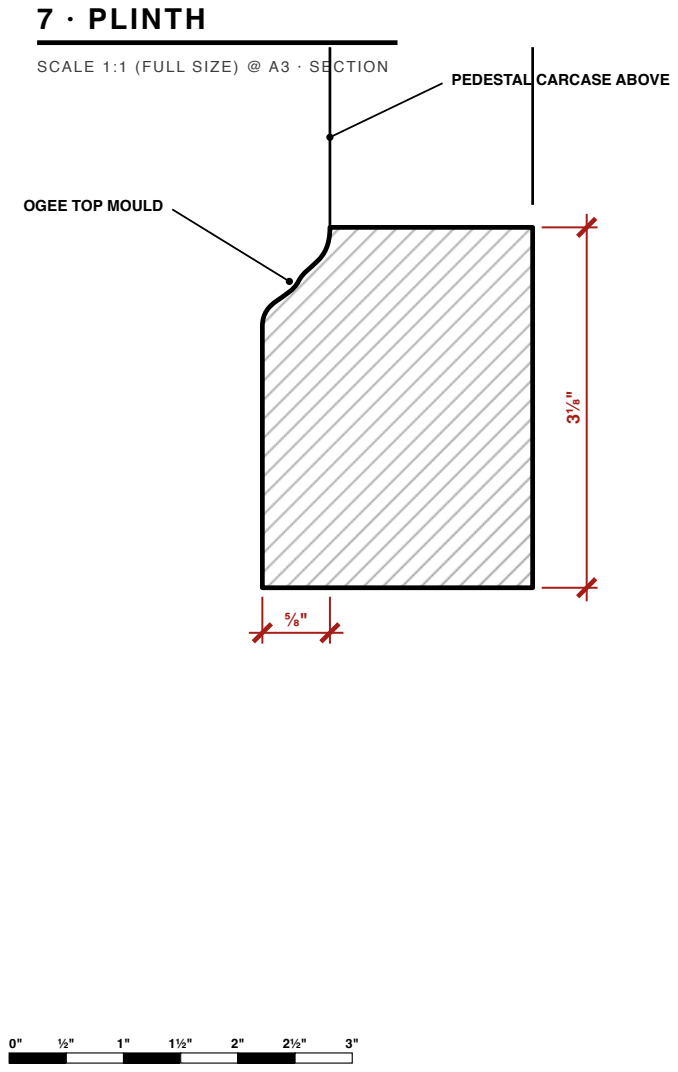
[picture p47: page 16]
7 · plinth

PEDESTAL CARCASE ABOVE

OGEE TOP MOULD

AST-DR-046 · 16 of 24

Edge · Rail · Clamp bay · Drawers · Handle · Plinth · Corner

# NOTES

# DETAILS

Profiles are drawn from film stills and are indicative;

the joiner to prepare a full-size mock-up of 1, 2 and 7.

# No carving: every profile is a run moulding — a spindle

moulder or router, no carver.

Hardware (6): standard 3½" swan-neck, solid brass.

Gold/brass on handles and ring pulls only; rest plain teak.

Corners: clean R 5⅞" hollow, every layer from one centre;

plain — no corner moulding (8, 8B). Clamp bay: detail 3.

## Notes

Edge · Rail · Clamp bay · Drawers · Handle · Plinth · Corner

## AST-DR-046 · 17 of 24

# 8B · CORNER ELEVATION

## SCALE 1:5 @ A3 · FRONT LEFT CORNER

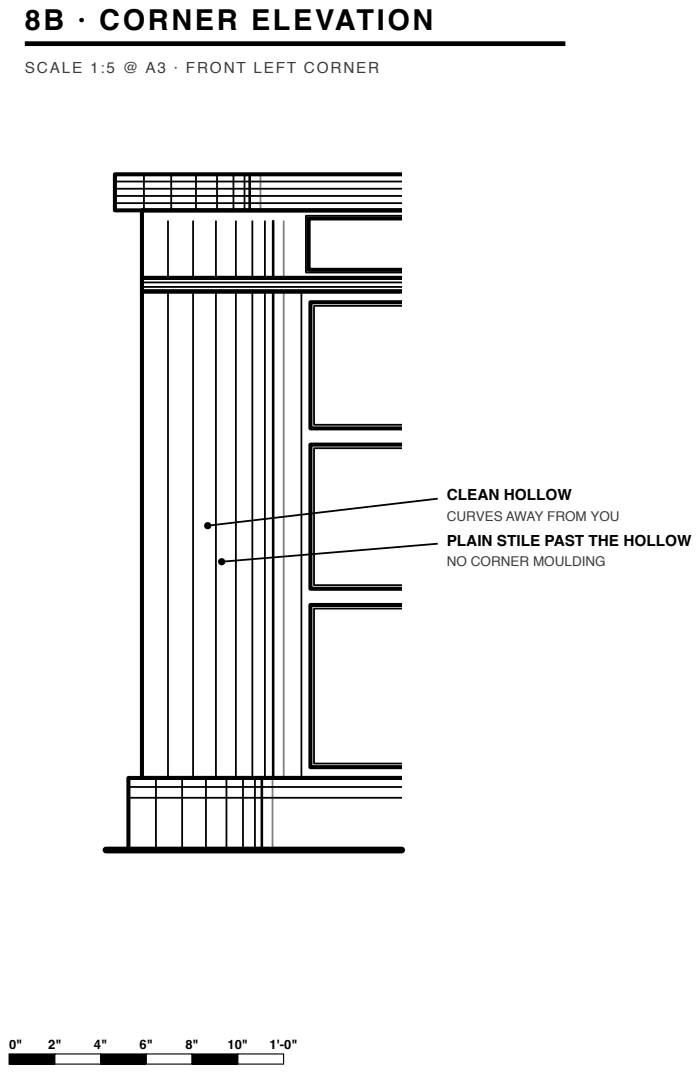
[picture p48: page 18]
8B · corner elevation

CLEAN HOLLOW
CURVES AWAY FROM YOU
PLAIN STILE PAST THE HOLLOW
NO CORNER MOULDING

AST-DR-046 · 18 of 24

Edge · Rail · Clamp bay · Drawers · Handle · Plinth · Corner

# 8 · CORNER — HOLLOW, PLAIN

## SCALE 1:2 (6" = 1'-0") @ A3 · PLAN · ALL FOUR CORNERS · CURVES SHARE ONE CENTRE

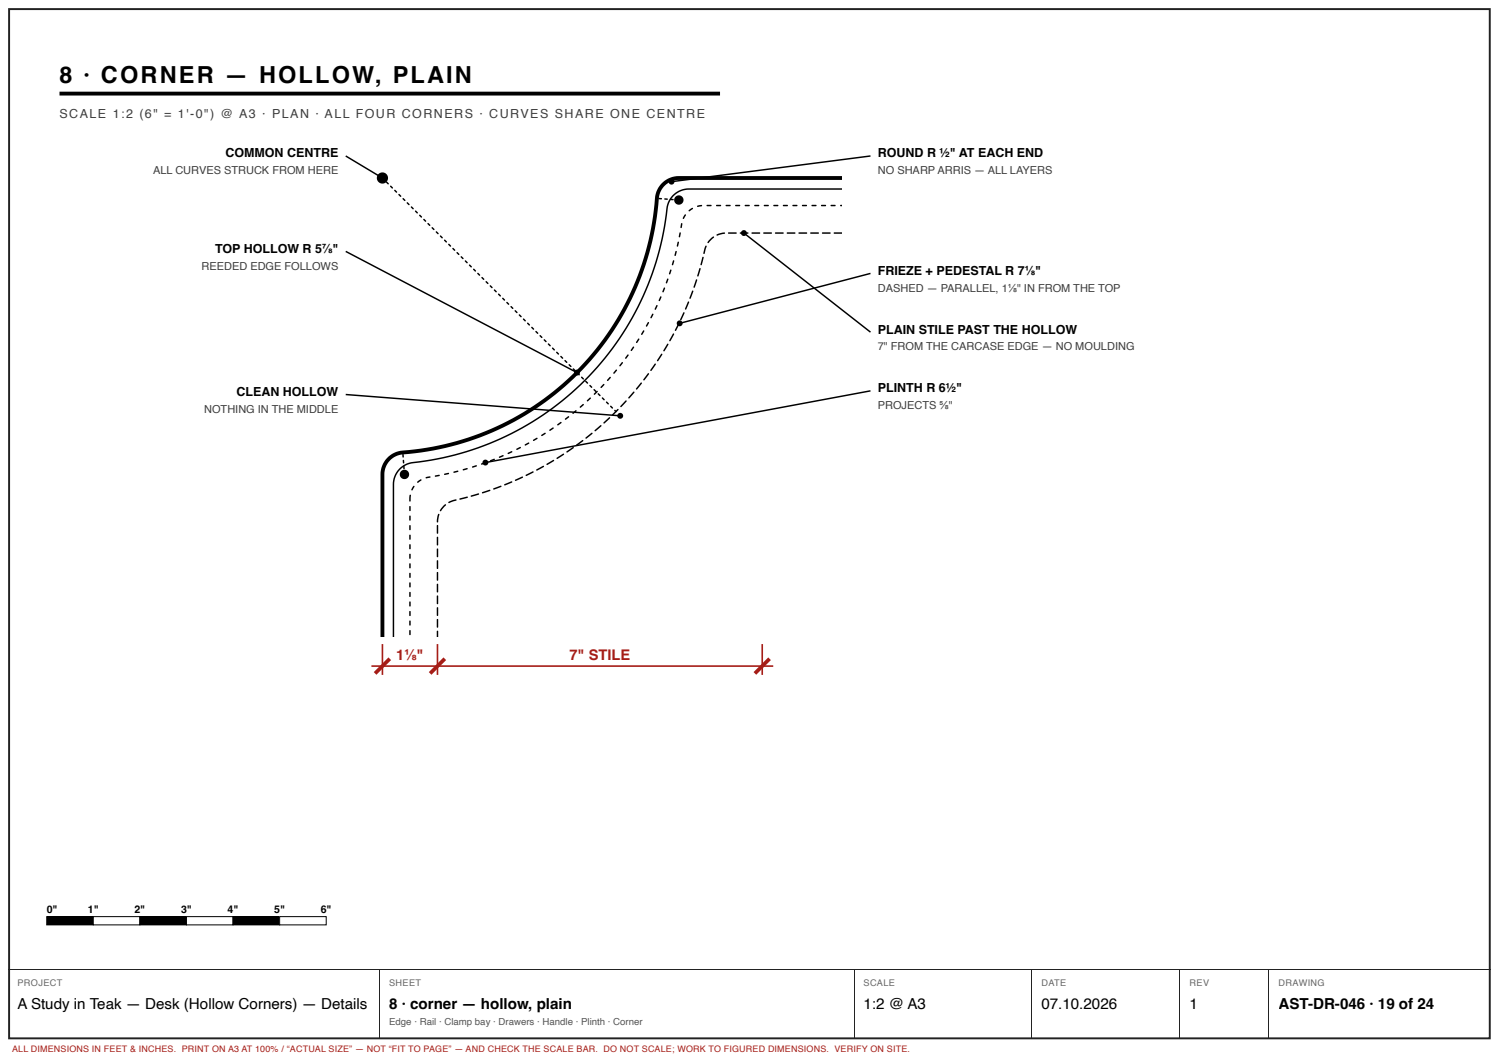
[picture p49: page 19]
COMMON CENTRE; PLINTH R 6½"; PROJECTS ⅝"; 7" STILE

ROUND R ½" AT EACH END
NO SHARP ARRIS — ALL LAYERS

ALL CURVES STRUCK FROM HERE

TOP HOLLOW R 5⅞"
REEDED EDGE FOLLOWS

FRIEZE + PEDESTAL R 7⅛"
DASHED — PARALLEL, 1⅛" IN FROM THE TOP

PLAIN STILE PAST THE HOLLOW
7" FROM THE CARCASE EDGE — NO MOULDING

CLEAN HOLLOW
NOTHING IN THE MIDDLE

8 · corner — hollow, plain

AST-DR-046 · 19 of 24

Edge · Rail · Clamp bay · Drawers · Handle · Plinth · Corner

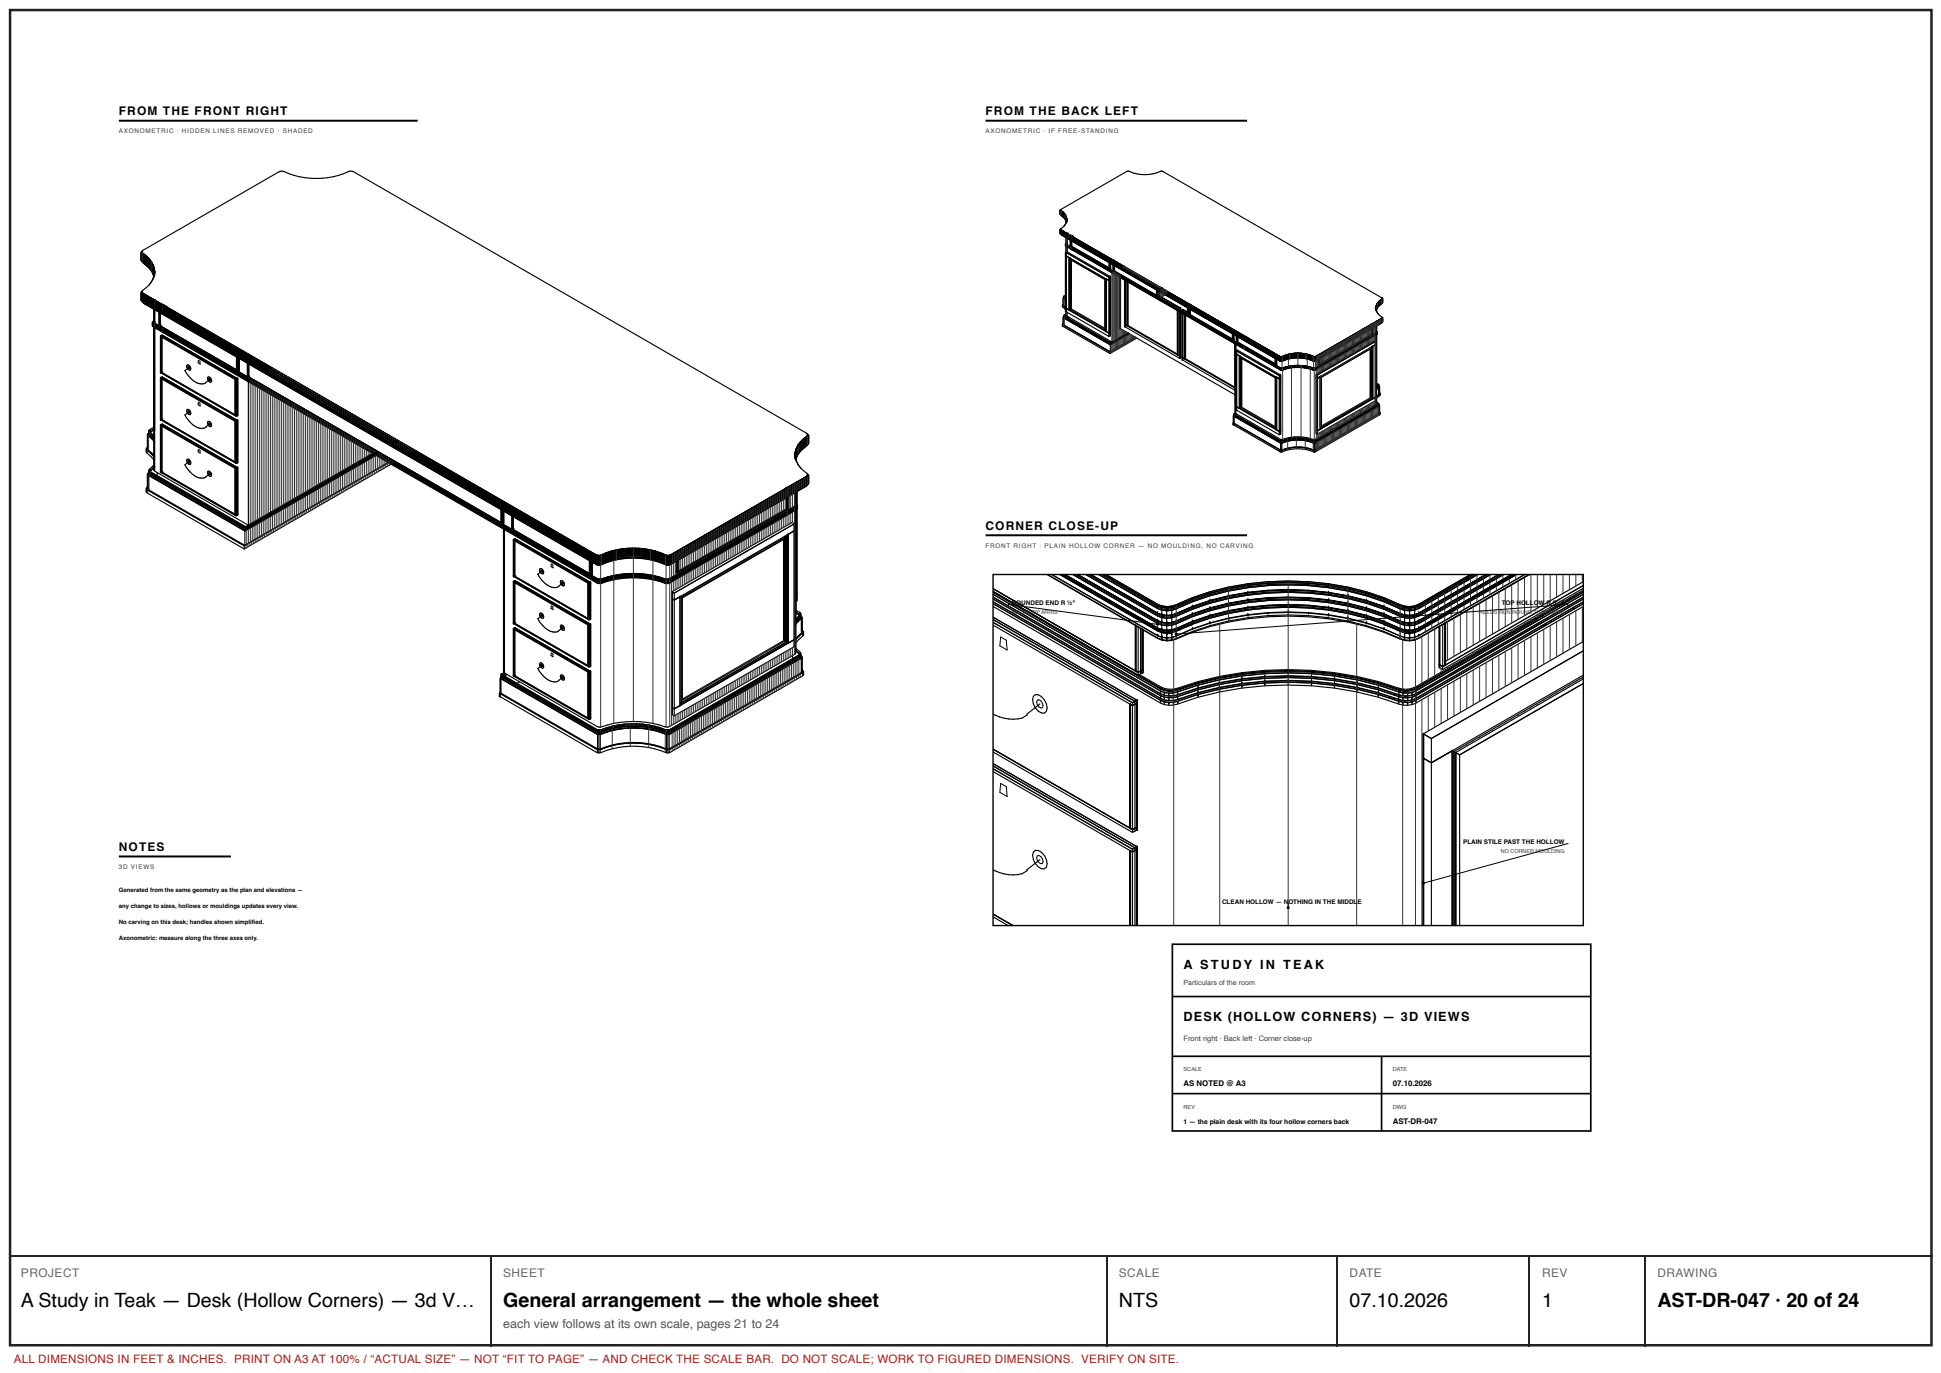
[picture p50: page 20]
TOP HOLLOW R 5⅞"; NOTES; 3D VIEWS; SCALE; AS NOTED @ A3; DATE; REV; DWG; AST-DR-047

FROM THE FRONT RIGHT

FROM THE BACK LEFT

AXONOMETRIC · HIDDEN LINES REMOVED · SHADED

AXONOMETRIC · IF FREE-STANDING

CORNER CLOSE-UP

FRONT RIGHT · PLAIN HOLLOW CORNER — NO MOULDING, NO CARVING

ROUNDED END R ½"
NO SHARP ARRIS

REEDS RUN ROUND THE CURVE

PLAIN STILE PAST THE HOLLOW

NO CORNER MOULDING

Generated from the same geometry as the plan and elevations —

any change to sizes, hollows or mouldings updates every view.

CLEAN HOLLOW — NOTHING IN THE MIDDLE

No carving on this desk; handles shown simplified.

Axonometric: measure along the three axes only.

Particulars of the room

DESK (HOLLOW CORNERS) — 3D VIEWS

Front right · Back left · Corner close-up

1 — the plain desk with its four hollow corners back

A Study in Teak — Desk (Hollow Corners) — 3d V…

General arrangement — the whole sheet

AST-DR-047 · 20 of 24

each view follows at its own scale, pages 21 to 24

# FROM THE FRONT RIGHT

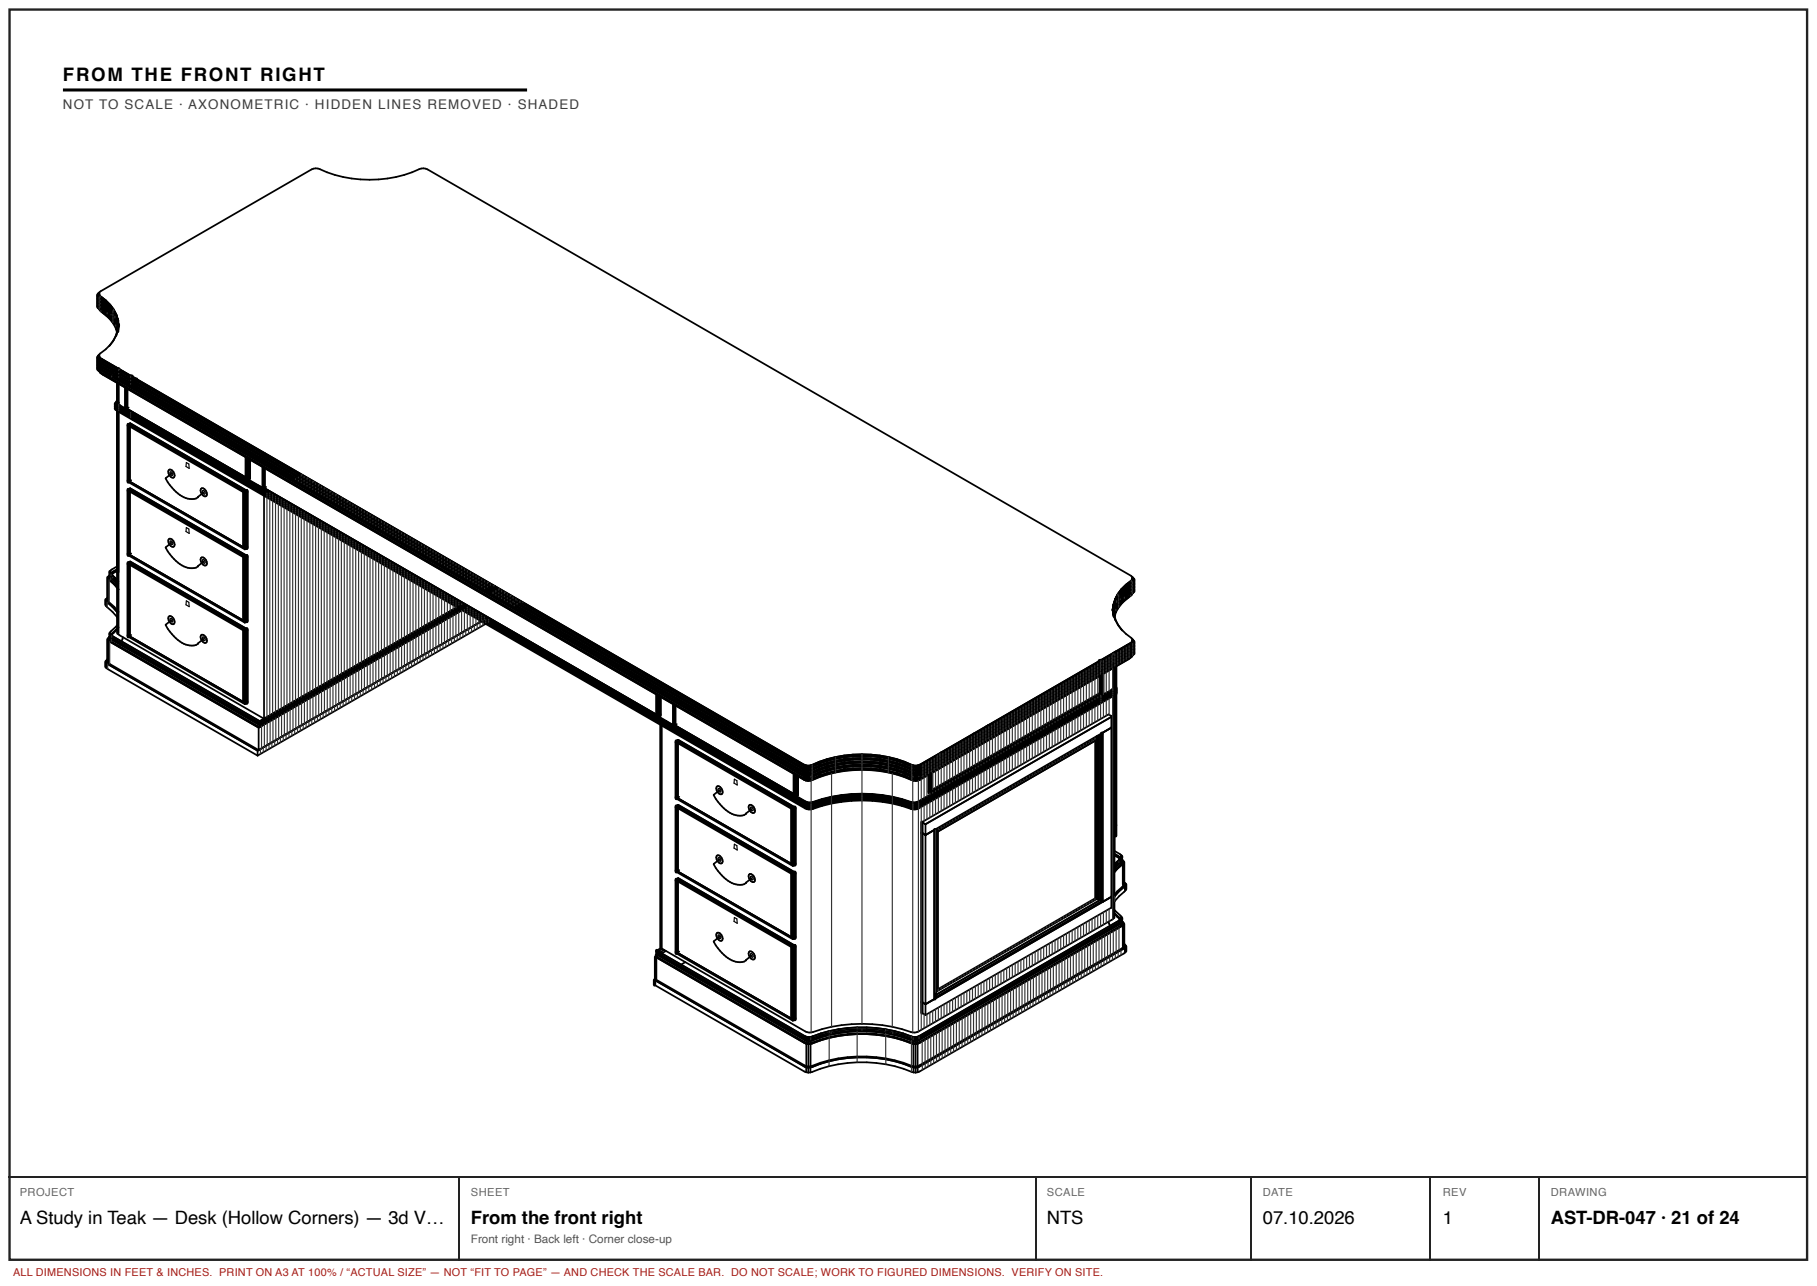
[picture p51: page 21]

NOT TO SCALE · AXONOMETRIC · HIDDEN LINES REMOVED · SHADED

A Study in Teak — Desk (Hollow Corners) — 3d V…

From the front right

AST-DR-047 · 21 of 24

Front right · Back left · Corner close-up

# FROM THE BACK LEFT

## NOT TO SCALE · AXONOMETRIC · IF FREE-STANDING


A Study in Teak — Desk (Hollow Corners) — 3d V…

From the back left

AST-DR-047 · 22 of 24

Front right · Back left · Corner close-up

# CORNER CLOSE-UP

## NOT TO SCALE · FRONT RIGHT · PLAIN HOLLOW CORNER — NO MOULDING, NO CARVING

TOP HOLLOW R 5⅞"

ROUNDED END R ½"
NO SHARP ARRIS

REEDS RUN ROUND THE CURVE

PLAIN STILE PAST THE HOLLOW

NO CORNER MOULDING

CLEAN HOLLOW — NOTHING IN THE MIDDLE

A Study in Teak — Desk (Hollow Corners) — 3d V…

Corner close-up

AST-DR-047 · 23 of 24

Front right · Back left · Corner close-up

# NOTES

# 3D VIEWS

# Generated from the same geometry as the plan and elevations —

any change to sizes, hollows or mouldings updates every view.

No carving on this desk; handles shown simplified.

Axonometric: measure along the three axes only.

## A Study in Teak — Desk (Hollow Corners) — 3d V…

## Notes

Front right · Back left · Corner close-up

## AST-DR-047 · 24 of 24

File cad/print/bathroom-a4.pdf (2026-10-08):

# PLAN

### THE WINDOW WALL AT THE TOP · THE DOOR FROM THE DRESSING ROOM BOTTOM LEFT

4'-0" SHOWER; 3'-5" 3'-5¼" CLEAR 2'-¾"; 9⅞" 5'-6⅞" TUB 2'-6¼"; SHOWER; TUB; BAT H ROO M; THE 7 IN WC WALL; CISTERN AND FRAME INSIDE IT; WALL-HUNG WC; GLASS BETWEEN; LINEAR DRAIN; LEVEL FLOOR, NO TRAY; GLASS FRONTS IN ONE LINE; DOORS OPEN OUT; TUB FILLER; FLOOR-STANDING; VANITY — SCHEME C; AST-DR-021, AS DRAWN; PIER, 10 IN; ? — SEE QUESTIONS; CEILING DROPPED 1 FT OVER THE SHOWER; 8 FT CLEAR — THIS BAY ONLY (DASH-DOT)

FACING THE SHOWER · NICHES OVER IT, ELEV. C

# SECTION B–B

### JUST IN FRONT OF THE GLASS, LOOKING AT THE WINDOW WALL

9'-1" GLASS; WINDOW — NOT MEASURED; WC IN PROFILE; RAIN HEAD ON AN ARM; MIXER; FILLER; TUB, CUT

### CEILING DROPPED 1 FT OVER THE SHOWER — 8 FT

SHOWER BAY ONLY · THE GLASS RUNS UP TO THE CEILING

# ASSUMED

### FROM THE SKETCH — TELL ME IF ANY OF THESE IS WRONG

WC and shower each 4 ft wide and 3 ft 5 in from the window wall, glass fronts in one line.

The WC wall-hung on the 7 in wall, its cistern hidden in it, facing the shower.

Glass clear, ⅜", frameless, 6 ft 6¾ in high, open above; chrome hinges, doors opening out.

Shower: level floor falling to a linear drain at the back; rain head on an arm, mixer on the wall.

Tub: freestanding oval, 5 ft 7 × 2 ft 7½, in the 3 ft 1 in bay, a floor-standing filler at its head.

Vanity: scheme C, unchanged. The window's size and height are still not measured.

# TO ASK

The sketch writes 3'0" by the tub: the tub's width, or the pier's length (it is 3 ft)?

What is the shape along the door wall between the pier and the east wall?

Glass: clear, reeded (very 1930s) or frosted — the WC's especially? To the ceiling?

Wall-hung WC, or one standing on the floor? And the walls: marble or plaster?

# NOTES

### REVISION 2

From the owner's sketch and words: along the window wall, after the 7 in wall — the owner's

"WC wall" — the WC and the shower side by side, each 4 ft wide, both behind glass and coming

the same distance off the wall (3 ft 5 in). The tub on the right, in the bay between the pier and

the east wall. The vanity stays on the door wall against the pier, as AST-DR-021.

That leaves 3 ft 5¼ in clear between the glass and the vanity, and the door swings

clear of everything. The shell is the measured one; the fittings are all to choose.

Rev 2 (owner, 7 Oct): the ceiling drops 1 ft over the shower bay only, to 8 ft clear —

a plastered box from the window wall to the glass line. Two niches in the WC wall, tall,

side by side above the flush plate, each framed in a marble moulding, as the owner's photo.

The window starts at the WC wall's corner, as the photo; its size is still to measure.

# ELEVATION C — THE WC WALL

### LOOKING WEST · THE WINDOW WALL ON THE RIGHT

1'-1⅛" | 1'-3"

1⅝"

11¾"

1⅝"

3'-11¼" 1'-11⅝" 1'-3¾" 1'-10⅜"

### WINDOW, CUT

IN THE WINDOW WALL

### TALL NICHE

1 ft 3 in × 3 ft 3⅜ in, 4 IN DEEP

### SHORT NICHE, BY THE WINDOW

11¾ in × 1 ft 11⅝ in, 4 IN DEEP

### MARBLE FRAME MOULDING

1½ IN, ROUND EACH NICHE

### FLUSH PLATE

CISTERN IN THE 7 IN WALL

### WALL-HUNG WC

Niches read off the owner's photo — sizes ASSUMED, to measure on site.

# A S T U D Y I N T E A K

## Particulars of the room

# BATHROOM

## Plan · Section B–B · The WC wall

### SCALE

## AS NOTED @ A3

### DATE

07.10.2026

### REV

### 2 — the shower's 1 ft dropped ceiling; the two WC-wall niches

### DWG

## AST-DR-037

# PROJECT

# A Study in Teak — Bathroom

# SHEET

# General arrangement — the whole sheet

# each view follows at its own scale, pages 2 to 7

# SCALE

# NTS

# DATE

07.10.2026

# REV

# DRAWING

# AST-DR-037 · 1 of 7

ALL DIMENSIONS IN FEET & INCHES. PRINT ON A4 AT 100% / “ACTUAL SIZE” — NOT “FIT TO PAGE” — AND CHECK THE SCALE BAR. DO NOT SCALE; WORK TO FIGURED DIMENSIONS. VERIFY ON SITE.

# PLAN

SCALE 1:24 (½" = 1'-0") @ A4 · THE WINDOW WALL AT THE TOP · THE DOOR FROM THE DRESSING ROOM BOTTOM LEFT

4'-0" SHOWER; 3'-5" 3'-5¼" CLEAR 2'-¾"; 9⅞" 5'-6⅞" TUB 2'-6¼"; SHOWER; TUB; BATHROO M; GLASS BETWEEN; LINEAR DRAIN; TUB FILLER FLOOR-STANDING; PIER, 10 IN; ? — SEE QUESTIONS; Plan

WALL-HUNG WC
FACING THE SHOWER · NICHES OVER IT, ELEV. C

LEVEL FLOOR, NO TRAY

THE 7 IN WC WALL
CISTERN AND FRAME INSIDE IT

CEILING DROPPED 1 FT OVER THE SHOWER
8 FT CLEAR — THIS BAY ONLY (DASH-DOT)

GLASS FRONTS IN ONE LINE
DOORS OPEN OUT

VANITY — SCHEME C
AST-DR-021, AS DRAWN

AST-DR-037 · 2 of 7

Plan · Section B–B · The WC wall

# SECTION B–B

# SCALE 1:30 @ A4 · JUST IN FRONT OF THE GLASS, LOOKING AT THE WINDOW WALL

9'-1" GLASS; MIXER; FILLER; TUB, CUT; Section B–B

CEILING DROPPED 1 FT OVER THE SHOWER — 8 FT
SHOWER BAY ONLY · THE GLASS RUNS UP TO THE CEILING

WINDOW — NOT MEASURED

RAIN HEAD ON AN ARM

WC IN PROFILE

AST-DR-037 · 3 of 7

# ASSUMED

# FROM THE SKETCH — TELL ME IF ANY OF THESE IS WRONG

WC and shower each 4 ft wide and 3 ft 5 in from the window wall, glass fronts in one line.

The WC wall-hung on the 7 in wall, its cistern hidden in it, facing the shower.

Glass clear, ⅜", frameless, 6 ft 6¾ in high, open above; chrome hinges, doors opening out.

Shower: level floor falling to a linear drain at the back; rain head on an arm, mixer on the wall.

Tub: freestanding oval, 5 ft 7 × 2 ft 7½, in the 3 ft 1 in bay, a floor-standing filler at its head.

Vanity: scheme C, unchanged. The window's size and height are still not measured.

# Assumed

# AST-DR-037 · 4 of 7

# NOTES

# REVISION 2

From the owner's sketch and words: along the window wall, after the 7 in wall — the owner's

"WC wall" — the WC and the shower side by side, each 4 ft wide, both behind glass and coming

the same distance off the wall (3 ft 5 in). The tub on the right, in the bay between the pier and

the east wall. The vanity stays on the door wall against the pier, as AST-DR-021.

# That leaves 3 ft 5¼ in clear between the glass and the vanity, and the door swings

clear of everything. The shell is the measured one; the fittings are all to choose.

# Rev 2 (owner, 7 Oct): the ceiling drops 1 ft over the shower bay only, to 8 ft clear —

a plastered box from the window wall to the glass line. Two niches in the WC wall, tall,

side by side above the flush plate, each framed in a marble moulding, as the owner's photo.

The window starts at the WC wall's corner, as the photo; its size is still to measure.

# Notes

# AST-DR-037 · 5 of 7

# ELEVATION C — THE WC WALL

# SCALE 1:30 @ A4 · LOOKING WEST · THE WINDOW WALL ON THE RIGHT

WINDOW, CUT; TALL NICHE; FLUSH PLATE

IN THE WINDOW WALL

1 ft 3 in × 3 ft 3⅜ in, 4 IN DEEP

SHORT NICHE, BY THE WINDOW

11¾ in × 1 ft 11⅝ in, 4 IN DEEP

MARBLE FRAME MOULDING

1½ IN, ROUND EACH NICHE

CISTERN IN THE 7 IN WALL

WALL-HUNG WC

Niches read off the owner's photo — sizes ASSUMED, to measure on site.

Elevation c — the wc wall

AST-DR-037 · 6 of 7

# TO ASK

# The sketch writes 3'0" by the tub: the tub's width, or the pier's length (it is 3 ft)?

# What is the shape along the door wall between the pier and the east wall?

# Glass: clear, reeded (very 1930s) or frosted — the WC's especially? To the ceiling?

# Wall-hung WC, or one standing on the floor? And the walls: marble or plaster?

# To ask

# AST-DR-037 · 7 of 7

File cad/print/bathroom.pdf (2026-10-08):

# PLAN

## THE WINDOW WALL AT THE TOP · THE DOOR FROM THE DRESSING ROOM BOTTOM LEFT

4'-0" SHOWER; 3'-5" 3'-5¼" CLEAR 2'-¾"; 9⅞" 5'-6⅞" TUB 2'-6¼"; SHOWER; TUB; BAT H ROO M; THE 7 IN WC WALL; CISTERN AND FRAME INSIDE IT; WALL-HUNG WC; GLASS BETWEEN; LINEAR DRAIN; LEVEL FLOOR, NO TRAY; GLASS FRONTS IN ONE LINE; DOORS OPEN OUT; TUB FILLER; FLOOR-STANDING; VANITY — SCHEME C; AST-DR-021, AS DRAWN; PIER, 10 IN; ? — SEE QUESTIONS; CEILING DROPPED 1 FT OVER THE SHOWER; 8 FT CLEAR — THIS BAY ONLY (DASH-DOT)

FACING THE SHOWER · NICHES OVER IT, ELEV. C

# SECTION B–B

## JUST IN FRONT OF THE GLASS, LOOKING AT THE WINDOW WALL

9'-1" GLASS; WINDOW — NOT MEASURED; WC IN PROFILE; RAIN HEAD ON AN ARM; MIXER; FILLER; TUB, CUT

## CEILING DROPPED 1 FT OVER THE SHOWER — 8 FT

SHOWER BAY ONLY · THE GLASS RUNS UP TO THE CEILING

# ASSUMED

## FROM THE SKETCH — TELL ME IF ANY OF THESE IS WRONG

WC and shower each 4 ft wide and 3 ft 5 in from the window wall, glass fronts in one line.

The WC wall-hung on the 7 in wall, its cistern hidden in it, facing the shower.

Glass clear, ⅜", frameless, 6 ft 6¾ in high, open above; chrome hinges, doors opening out.

Shower: level floor falling to a linear drain at the back; rain head on an arm, mixer on the wall.

Tub: freestanding oval, 5 ft 7 × 2 ft 7½, in the 3 ft 1 in bay, a floor-standing filler at its head.

Vanity: scheme C, unchanged. The window's size and height are still not measured.

# TO ASK

The sketch writes 3'0" by the tub: the tub's width, or the pier's length (it is 3 ft)?

What is the shape along the door wall between the pier and the east wall?

Glass: clear, reeded (very 1930s) or frosted — the WC's especially? To the ceiling?

Wall-hung WC, or one standing on the floor? And the walls: marble or plaster?

# NOTES

## REVISION 2

From the owner's sketch and words: along the window wall, after the 7 in wall — the owner's

"WC wall" — the WC and the shower side by side, each 4 ft wide, both behind glass and coming

the same distance off the wall (3 ft 5 in). The tub on the right, in the bay between the pier and

the east wall. The vanity stays on the door wall against the pier, as AST-DR-021.

That leaves 3 ft 5¼ in clear between the glass and the vanity, and the door swings

clear of everything. The shell is the measured one; the fittings are all to choose.

Rev 2 (owner, 7 Oct): the ceiling drops 1 ft over the shower bay only, to 8 ft clear —

a plastered box from the window wall to the glass line. Two niches in the WC wall, tall,

side by side above the flush plate, each framed in a marble moulding, as the owner's photo.

The window starts at the WC wall's corner, as the photo; its size is still to measure.

# ELEVATION C — THE WC WALL

## LOOKING WEST · THE WINDOW WALL ON THE RIGHT

1'-1⅛" | 1'-3"

1⅝"

11¾"

1⅝"

3'-11¼" 1'-11⅝" 1'-3¾" 1'-10⅜"

## WINDOW, CUT

IN THE WINDOW WALL

## TALL NICHE

1 ft 3 in × 3 ft 3⅜ in, 4 IN DEEP

## SHORT NICHE, BY THE WINDOW

11¾ in × 1 ft 11⅝ in, 4 IN DEEP

## MARBLE FRAME MOULDING

1½ IN, ROUND EACH NICHE

## FLUSH PLATE

CISTERN IN THE 7 IN WALL

## WALL-HUNG WC

Niches read off the owner's photo — sizes ASSUMED, to measure on site.

# A S T U D Y I N T E A K

## Particulars of the room

# BATHROOM

## Plan · Section B–B · The WC wall

SCALE

## AS NOTED @ A3

DATE
07.10.2026

REV

2 — the shower's 1 ft dropped ceiling; the two WC-wall niches

DWG

## AST-DR-037

# PROJECT

# A Study in Teak — Bathroom

# SHEET

# General arrangement — the whole sheet

# each view follows at its own scale, pages 2 to 7

# SCALE

# NTS

# DATE

07.10.2026

# REV

# DRAWING

# AST-DR-037 · 1 of 7

ALL DIMENSIONS IN FEET & INCHES. PRINT ON A3 AT 100% / “ACTUAL SIZE” — NOT “FIT TO PAGE” — AND CHECK THE SCALE BAR. DO NOT SCALE; WORK TO FIGURED DIMENSIONS. VERIFY ON SITE.

# PLAN

SCALE 1:16 (¾" = 1'-0") @ A3 · THE WINDOW WALL AT THE TOP · THE DOOR FROM THE DRESSING ROOM BOTTOM LEFT

4'-0" SHOWER; 3'-5" 3'-5¼" CLEAR 2'-¾"; 9⅞" 5'-6⅞" TUB 2'-6¼"; SHOWER; TUB; BAT H ROO M; GLASS BETWEEN; LINEAR DRAIN; TUB FILLER FLOOR-STANDING; PIER, 10 IN; ? — SEE QUESTIONS; Plan

WALL-HUNG WC
FACING THE SHOWER · NICHES OVER IT, ELEV. C

LEVEL FLOOR, NO TRAY

THE 7 IN WC WALL
CISTERN AND FRAME INSIDE IT

CEILING DROPPED 1 FT OVER THE SHOWER
8 FT CLEAR — THIS BAY ONLY (DASH-DOT)

GLASS FRONTS IN ONE LINE
DOORS OPEN OUT

VANITY — SCHEME C
AST-DR-021, AS DRAWN

AST-DR-037 · 2 of 7

Plan · Section B–B · The WC wall

# SECTION B–B

# SCALE 1:20 @ A3 · JUST IN FRONT OF THE GLASS, LOOKING AT THE WINDOW WALL

9'-1" GLA; MIXER; FILLER; TUB, CUT; Section B–B

CEILING DROPPED 1 FT OVER THE SHOWER — 8 FT
SHOWER BAY ONLY · THE GLASS RUNS UP TO THE CEILING

WINDOW — NOT MEASURED

RAIN HEAD ON AN ARM

WC IN PROFILE

AST-DR-037 · 3 of 7

# ASSUMED

# FROM THE SKETCH — TELL ME IF ANY OF THESE IS WRONG

WC and shower each 4 ft wide and 3 ft 5 in from the window wall, glass fronts in one line.

The WC wall-hung on the 7 in wall, its cistern hidden in it, facing the shower.

Glass clear, ⅜", frameless, 6 ft 6¾ in high, open above; chrome hinges, doors opening out.

Shower: level floor falling to a linear drain at the back; rain head on an arm, mixer on the wall.

Tub: freestanding oval, 5 ft 7 × 2 ft 7½, in the 3 ft 1 in bay, a floor-standing filler at its head.

Vanity: scheme C, unchanged. The window's size and height are still not measured.

# Assumed

# AST-DR-037 · 4 of 7

# NOTES

# REVISION 2

From the owner's sketch and words: along the window wall, after the 7 in wall — the owner's

"WC wall" — the WC and the shower side by side, each 4 ft wide, both behind glass and coming

the same distance off the wall (3 ft 5 in). The tub on the right, in the bay between the pier and

the east wall. The vanity stays on the door wall against the pier, as AST-DR-021.

# That leaves 3 ft 5¼ in clear between the glass and the vanity, and the door swings

clear of everything. The shell is the measured one; the fittings are all to choose.

# Rev 2 (owner, 7 Oct): the ceiling drops 1 ft over the shower bay only, to 8 ft clear —

a plastered box from the window wall to the glass line. Two niches in the WC wall, tall,

side by side above the flush plate, each framed in a marble moulding, as the owner's photo.

The window starts at the WC wall's corner, as the photo; its size is still to measure.

# Notes

# AST-DR-037 · 5 of 7

# ELEVATION C — THE WC WALL

# SCALE 1:20 @ A3 · LOOKING WEST · THE WINDOW WALL ON THE RIGHT

WINDOW, CUT; TALL NICHE; FLUSH PLATE

IN THE WINDOW WALL

1 ft 3 in × 3 ft 3⅜ in, 4 IN DEEP

SHORT NICHE, BY THE WINDOW

11¾ in × 1 ft 11⅝ in, 4 IN DEEP

MARBLE FRAME MOULDING

1½ IN, ROUND EACH NICHE

CISTERN IN THE 7 IN WALL

WALL-HUNG WC

Niches read off the owner's photo — sizes ASSUMED, to measure on site.

Elevation c — the wc wall

AST-DR-037 · 6 of 7

# TO ASK

# The sketch writes 3'0" by the tub: the tub's width, or the pier's length (it is 3 ft)?

# What is the shape along the door wall between the pier and the east wall?

# Glass: clear, reeded (very 1930s) or frosted — the WC's especially? To the ceiling?

# Wall-hung WC, or one standing on the floor? And the walls: marble or plaster?

# To ask

# AST-DR-037 · 7 of 7

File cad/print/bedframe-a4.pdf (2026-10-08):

FRONT — FROM THE FOOT; 6'-0" MATTRESS; 6'-4" OVERALL — THE HEADBOARD THE SAME; 11" BASE 10" MATTRESS 1'-7"; 3'-4" TO THE TOP; HEADBOARD, DUSTY-ROSE SUEDE; SIDE; 6'-6" MATTRESS; 6'-11" OVERALL; HEADBOARD, 3 IN; STORAGE BASE, TO THE FLOOR; PLAN; HEADBOARD AT THE TOP; 1 · HEADBOARD TOP EDGE; SECTION; 2 · FIXING

THE STORAGE BASE AND HEADBOARD BOTH TO THE FLOOR

1¼ IN GLOSS-BLACK FRAME, ITS TOP CORNERS ROUNDED

HEADBOARD LEFT, THE PLASTER BEHIND IT DASHED

BOLTED TO THE BASE — DETAIL 2 · 1 IN OFF THE PLASTER

NO LEGS, GLOSS BLACK · CORNERS ROUNDED 3 IN, EDGES EASED ⅝ IN


¾" | 2" | ¼"

1¼"

THIN BLACK FRAME, GLOSS LACQUER

1¼ IN FACE, AS THE MIRROR'S · TOP AND BOTH SIDES

DUSTY-ROSE SUEDE PANEL

¼ IN PROUD OF THE FRAME · PLAIN

¾ IN PLY BACK

THE SUEDE TURNED OVER AND STAPLED BEHIND

### 2 IN FOAM, WADDING OVER

The headboard bolts to the base's head end —

two M8 bolts through the base into T-nuts in the

ply back, the foam relieved round them (dashed

on the plan). It stands on the floor, 1 in clear of

the parchment, and never hangs off the wall.

NOTES

REVISION 6

The bed on a storage base (owner, 7 Oct): a plain box straight down to

the floor, no legs, 2 in past the 6 ft × 6 ft 6 in mattress at the sides

and foot, 11 in to the mattress. The storage inside is not drawn.

The slim upholstered headboard behind it, the frame's width, 3 ft 4 in

high, also to the floor: a dusty-rose suede panel in a 1¼ in gloss-black

frame — as thin as the dressing mirror's. The base in GLOSS BLACK lacquer

(owner, 7 Oct): the room's black accent, Deco with the rose. Mattress 10 in.

A S T U D Y I N T E A K

Particulars of the room

THE BED

Front · Side · Plan · Headboard

SCALE

AS NOTED @ A3

DATE

08.10.2026

REV

6 — base corners rounded 3 in and edges eased; headboard top corners rounded (owner, 8 Oct)

DWG

AST-DR-035

PROJECT

# A Study in Teak — The Bed

SHEET

# General arrangement — the whole sheet

each view follows at its own scale, pages 2 to 7

SCALE

# NTS

DATE
08.10.2026

REV

DRAWING

# AST-DR-035 · 1 of 7

ALL DIMENSIONS IN FEET & INCHES. PRINT ON A4 AT 100% / “ACTUAL SIZE” — NOT “FIT TO PAGE” — AND CHECK THE SCALE BAR. DO NOT SCALE; WORK TO FIGURED DIMENSIONS. VERIFY ON SITE.

# FRONT — FROM THE FOOT

### SCALE 1:10 @ A4 · THE STORAGE BASE AND HEADBOARD BOTH TO THE FLOOR

6'-0" MATTRESS; 11" BASE 10" MATTRESS 1'-7"

HEADBOARD, DUSTY-ROSE SUEDE
1¼ IN GLOSS-BLACK FRAME, ITS TOP CORNER

3'-4" TO THE TOP

6'-4" OVERALL — THE HEADBOARD THE SAME

Front — from the foot

AST-DR-035 · 2 of 7

Front · Side · Plan · Headboard

# SIDE

### SCALE 1:10 @ A4 · HEADBOARD LEFT, THE PLASTER BEHIND IT DASHED

6'-6" MATTRESS; 6'-11" OVERALL; Side

HEADBOARD, 3 IN
BOLTED TO THE BASE — DETAIL 2 · 1 IN OFF THE PLASTER

STORAGE BASE, TO THE FLOOR

NO LEGS, GLOSS BLACK · CORNERS ROUNDED 3 IN, EDGES EASED ⅝ IN

AST-DR-035 · 3 of 7

## PLAN

Plan

SCALE 1:20 @ A4 · HEADBOARD AT THE TOP

AST-DR-035 · 4 of 7

# 1 · HEADBOARD TOP EDGE

## SCALE 1:3 (4" = 1'-0") @ A4 · SECTION


THIN BLACK FRAME, GLOSS LACQUER

1¼ IN FACE, AS THE MIRROR'S · TOP AND BOTH SIDES

DUSTY-ROSE SUEDE PANEL

¼ IN PROUD OF THE FRAME · PLAIN

¾ IN PLY BACK

THE SUEDE TURNED OVER AND STAPLED BEHIND

2 IN FOAM, WADDING OVER

1 · headboard top edge

AST-DR-035 · 5 of 7

# 2 · F I X I N G

# The headboard bolts to the base's head end —

# two M8 bolts through the base into T-nuts in the

# ply back, the foam relieved round them (dashed

# on the plan). It stands on the floor, 1 in clear of

the parchment, and never hangs off the wall.

# 2 · fixing

# AST-DR-035 · 6 of 7

# NOTES

# REVISION 6

# The bed on a storage base (owner, 7 Oct): a plain box straight down to

# the floor, no legs, 2 in past the 6 ft × 6 ft 6 in mattress at the sides

and foot, 11 in to the mattress. The storage inside is not drawn.

# The slim upholstered headboard behind it, the frame's width, 3 ft 4 in

# high, also to the floor: a dusty-rose suede panel in a 1¼ in gloss-black

# frame — as thin as the dressing mirror's. The base in GLOSS BLACK lacquer

(owner, 7 Oct): the room's black accent, Deco with the rose. Mattress 10 in.

# Notes

# AST-DR-035 · 7 of 7

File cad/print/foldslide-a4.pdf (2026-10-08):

# DRESSING ROOM — THE END-BAY DOORS

THREE WAYS TO OPEN THEM WITHOUT HITTING THE FREE-STANDING MIRROR · PLANS

## THE ROOM — END BAYS OPEN AS A

7½" | 3'-6" MIRROR | 7½"

9'-3" ROOM

MIRROR | OPTION A

FOLDS IN · PARKS AT THE MIRROR END

CUPBOARD | ROOM

MIRROR END ↑

## OPTION B

FOLDS IN · PARKS AT THE FRONT END

CUPBOARD | ROOM

MIRROR END ↑

## OPTION C

FOLDS OUT, THEN SLIDES IN · FRONT END

CUPBOARD | ROOM

MIRROR END ↑

the folded pair of doors, open

dashed red — the wardrobe front / the path of the fold

brass — head track along the front, runner along the side

## HINGES AND HARDWARE

CENTRE HINGE

Continuous brass piano hinge, full height, between the two leaves. INSIDE face for A and B; room face for C.

PARKING LEAF

Top and bottom pivot pins on a carriage that runs in a runner along the side panel. The same for A, B and C.

FREE LEAF

Guide roller at the top, running in the head track along the front; small guide at the floor. All three options.

PUSH-BACK

All three. Folded pair is about 1 ft 6 in deep, 3 in thick; the 2 ft 3 in cupboard lets it go back about 8 in.

HANGING RAIL

Stop it about 4 in short of the side panel the pair parks against. Nothing else inside the bay changes.

# NOTES

REVISION 2

Why not ordinary hinges: a leaf at the back of either run swings about 1 ft 6½ in into the room, and

the mirror (3 ft 6 in across, centred) leaves only 7½ in beside it. It would hit the mirror.

Two leaves hinged together always fold into a triangle. A and B put the triangle INSIDE the cupboard

and push the folded pair back, so nothing ever passes the wardrobe front.

C folds out into the room first, like the owner's photo, then slides back in the same way. It crosses

the wardrobe front only while folding, at the front end of the bay, well away from the mirror.

Revision 1 of this sheet showed the pair folding flat against the front — that cannot be built and

is withdrawn. The video on the Dressing page shows all three moving.

A — parks at the mirror end: you reach in from the front, never from behind the mirror.

B — parks at the front end: same mechanism, other side of the bay.

C — while it folds, it stands about 1 ft 6 in into the room; once slid in, the corridor is clear.

The tunnel bay works the same way; in A and B its folded pair can slide right back into the

tunnel, out of sight.

CHOSEN — C, confirmed by the owner. A and B are kept here for reference.

# A S T U D Y I N T E A K

### Particulars of the room

# END-BAY DOORS

### Dressing room · three ways to open

SCALE

### 1:42 AND 1:25 @ A3

DATE

26.09.2026

REV

3 — option C chosen

DWG

### AST-DR-026

# PROJECT

# A Study in Teak — End-Bay Doors

# SHEET

# General arrangement — the whole sheet

# each view follows at its own scale, pages 2 to 3

# SCALE

# NTS

# DATE

26.09.2026

# REV

# DRAWING

# AST-DR-026 · 1 of 3

ALL DIMENSIONS IN FEET & INCHES. PRINT ON A4 AT 100% / “ACTUAL SIZE” — NOT “FIT TO PAGE” — AND CHECK THE SCALE BAR. DO NOT SCALE; WORK TO FIGURED DIMENSIONS. VERIFY ON SITE.

# DRESSING ROOM — THE END-BAY DOORS

# THREE WAYS TO OPEN THEM WITHOUT HITTING THE FREE-STANDING MIRROR · PLANS

# THE ROOM — END BAYS OPEN AS A

3'-6" MIRROR; 9'-3" ROOM

MIRROR | OPTION A
| FOLDS IN · PARKS AT THE MIRROR END
CUPBOARD | ROOM

## MIRROR END ↑

# OPTION B

# FOLDS IN · PARKS AT THE FRONT END

CUPBOARD | ROOM

## MIRROR END ↑

# OPTION C

# FOLDS OUT, THEN SLIDES IN · FRONT END

CUPBOARD | ROOM

## MIRROR END ↑

# the folded pair of doors, open

# dashed red — the wardrobe front / the path of the fold

# brass — head track along the front, runner along the side

# HINGES AND HARDWARE

# CENTRE HINGE

Continuous brass piano hinge, full height, between the two leaves. INSIDE face for A and B; room face for C.

# PARKING LEAF

Top and bottom pivot pins on a carriage that runs in a runner along the side panel. The same for A, B and C.

# FREE LEAF

Guide roller at the top, running in the head track along the front; small guide at the floor. All three options.

# PUSH-BACK

All three. Folded pair is about 1 ft 6 in deep, 3 in thick; the 2 ft 3 in cupboard lets it go back about 8 in.

# HANGING RAIL

Stop it about 4 in short of the side panel the pair parks against. Nothing else inside the bay changes.

# Dressing room — the end-bay doors

# Dressing room · three ways to open

# AST-DR-026 · 2 of 3

# NOTES

# REVISION 2

Why not ordinary hinges: a leaf at the back of either run swings about 1 ft 6½ in into the room, and

the mirror (3 ft 6 in across, centred) leaves only 7½ in beside it. It would hit the mirror.

Two leaves hinged together always fold into a triangle. A and B put the triangle INSIDE the cupboard

and push the folded pair back, so nothing ever passes the wardrobe front.

C folds out into the room first, like the owner's photo, then slides back in the same way. It crosses

the wardrobe front only while folding, at the front end of the bay, well away from the mirror.

Revision 1 of this sheet showed the pair folding flat against the front — that cannot be built and

is withdrawn. The video on the Dressing page shows all three moving.

# A — parks at the mirror end: you reach in from the front, never

# B — parks at the front end: same mechanism, other side of the

# C — while it folds, it stands about 1 ft 6 in into the room; once

# The tunnel bay works the same way; in A and B its folded pair

tunnel, out of sight.

# CHOSEN — C, confirmed by the owner. A and B are kept here f

# Notes

# Dressing room · three ways to open

# AST-DR-026 · 3 of 3

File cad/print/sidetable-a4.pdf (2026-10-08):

FRONT

AS THE OWNER'S PHOTO

SIDE

THE WALL ON THE LEFT

PLAN

THE WALL AT THE TOP · APRON AND LEGS DASHED

10½" DRAWER; 1'-4" TOP; 2'-0" HIGH; SHAPED TOP, MOULDED EDGE; WOOD, POLISHED DARK — NO STONE; CARVED CONSOLE, EACH CORNER; ROUNDEL, REEDED STEM, VOLUTE; ONE DRAWER, BURL FRONT; COCK-BEADED · SOFT-CLOSE RUNNERS; BRASS ROSETTE KNOB; DETAIL 3; CABRIOLE LEG; SOLID, A BEAD DOWN ITS FRONT EDGE; SCROLL TOE
11⅞" APRON; 1'-2" TOP

1'-1⅜" ⅝"

4" TO THE DIP | 4" TO THE FULL CENTRE

TOP — WOOD, NO STONE

2 · TOP EDGE

SECTION

⅞"

THUMBNAIL MOULDING

AND A FILLET UNDER

THE TOP, SOLID

⅞ IN, POLISHED DARK

WOODEN BUTTON

LETS THE TOP MOVE

THE APRON SIDE

BURL OUTSIDE

3 · KNOB

FACE AND SECTION

BRASS, CAST ROSETTE

1⅛" BACKPLATE, ⅝" KNOB

BOLTED THROUGH THE DRAWER

NOTES

REVISION 1

After the owner's photo (7 Oct): a shaped serpentine top with a moulded edge and eared front corners — wood, no

stone (owner); a deep apron with one drawer, its front in burl, a brass rosette knob in the middle; a carved console

at each corner; tall slim cabriole legs with a bead down the front edge, ending in a scroll toe. Two the same.

⅝" × ½" in and 1" in high — the photo's table is taller; its proportions are kept, the height is set by the bed

(3 in above the mattress). The back legs turn their knees sideways only, so the table stands tight to the parchment.

Top and legs polished dark, as the photo; apron and drawer in the room's burl. Finish to confirm with the bed's.

A S T U D Y I N T E A K

Particulars of the room

THE SIDE TABLES

Front · Side · Plan · Top edge · Knob

SCALE

AS NOTED @ A3

DATE

07.10.2026

REV

1 — after the owner's photo: shaped top, burl drawer, cabriole legs; no stone

DWG

AST-DR-049

PROJECT

# A Study in Teak — The Side Tables

SHEET

# General arrangement — the whole sheet

each view follows at its own scale, pages 2 to 7

SCALE

# NTS

DATE
07.10.2026

REV

DRAWING

# AST-DR-049 · 1 of 7

ALL DIMENSIONS IN FEET & INCHES. PRINT ON A4 AT 100% / “ACTUAL SIZE” — NOT “FIT TO PAGE” — AND CHECK THE SCALE BAR. DO NOT SCALE; WORK TO FIGURED DIMENSIONS. VERIFY ON SITE.

## FRONT

### SHAPED TOP, MOULDED EDG

10½" DRAWER; 1'-4" TOP; 2'-0" HIGH; SCROLL TOE; Front

SCALE 1:5 @ A4 · AS THE OWNER'S PHOTO

WOOD, POLISHED DARK — NO STO

CARVED CONSOLE, EACH CO
ROUNDEL, REEDED STEM, VOLUT

ONE DRAWER, BURL FRONT
COCK-BEADED · SOFT-CLOSE RUN

BRASS ROSETTE KNOB
DETAIL 3

CABRIOLE LEG
SOLID, A BEAD DOWN ITS FRONT E

AST-DR-049 · 2 of 7

Front · Side · Plan · Top edge · Knob

## SIDE

11⅞" APRON; 1'-2" TOP; Side

SCALE 1:5 @ A4 · THE WALL ON THE LEFT

AST-DR-049 · 3 of 7

# PLAN

### SCALE 1:4 (3" = 1'-0") @ A4 · THE WALL AT THE TOP · APRON AND LEGS DASHED

4" TO THE DIP; 4" TO THE FULL CENTRE; Plan

TOP — WOOD, NO STONE

AST-DR-049 · 4 of 7

## 2 · TOP EDGE

### THUMBNAIL MOULD

2 · top edge

SCALE 1:1 (FULL SIZE) @ A4 · SECTION

AND A FILLET UNDER

THE TOP, SOLID
⅞ IN, POLISHED DARK

WOODEN BUTTON
LETS THE TOP MOVE

THE APRON SIDE
BURL OUTSIDE

AST-DR-049 · 5 of 7

# NOTES

# REVISION 1

After the owner's photo (7 Oct): a shaped serpentine top with a moulded edge and eared front corners — wood, no

stone (owner); a deep apron with one drawer, its front in burl, a brass rosette knob in the middle; a carved console

at each corner; tall slim cabriole legs with a bead down the front edge, ending in a scroll toe. Two the same.

⅝" × ½" in and 1" in high — the photo's table is taller; its proportions are kept, the height is set by the bed

(3 in above the mattress). The back legs turn their knees sideways only, so the table stands tight to the parchment.

Top and legs polished dark, as the photo; apron and drawer in the room's burl. Finish to confirm with the bed's.

# Notes

# NTS

# AST-DR-049 · 6 of 7

## 3 · KNOB

1⅛" BACKPLATE, ⅝" KNOB; 3 · knob

SCALE 1:1 (FULL SIZE) @ A4 · FACE AND SECTION

BRASS, CAST ROSETTE

BOLTED THROUGH THE DR

AST-DR-049 · 7 of 7

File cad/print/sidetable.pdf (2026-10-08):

FRONT

AS THE OWNER'S PHOTO

SIDE

THE WALL ON THE LEFT

PLAN

THE WALL AT THE TOP · APRON AND LEGS DASHED

10½" DRAWER; 1'-4" TOP; 2'-0" HIGH; SHAPED TOP, MOULDED EDGE; WOOD, POLISHED DARK — NO STONE; CARVED CONSOLE, EACH CORNER; ROUNDEL, REEDED STEM, VOLUTE; ONE DRAWER, BURL FRONT; COCK-BEADED · SOFT-CLOSE RUNNERS; BRASS ROSETTE KNOB; DETAIL 3; CABRIOLE LEG; SOLID, A BEAD DOWN ITS FRONT EDGE; SCROLL TOE
11⅞" APRON; 1'-2" TOP

1'-1⅜" ⅝"

4" TO THE DIP | 4" TO THE FULL CENTRE

TOP — WOOD, NO STONE

2 · TOP EDGE

SECTION

⅞"

THUMBNAIL MOULDING

AND A FILLET UNDER

THE TOP, SOLID

⅞ IN, POLISHED DARK

WOODEN BUTTON

LETS THE TOP MOVE

THE APRON SIDE

BURL OUTSIDE

3 · KNOB

FACE AND SECTION

BRASS, CAST ROSETTE

1⅛" BACKPLATE, ⅝" KNOB

BOLTED THROUGH THE DRAWER

NOTES

REVISION 1

After the owner's photo (7 Oct): a shaped serpentine top with a moulded edge and eared front corners — wood, no

stone (owner); a deep apron with one drawer, its front in burl, a brass rosette knob in the middle; a carved console

at each corner; tall slim cabriole legs with a bead down the front edge, ending in a scroll toe. Two the same.

⅝" × ½" in and 1" in high — the photo's table is taller; its proportions are kept, the height is set by the bed

(3 in above the mattress). The back legs turn their knees sideways only, so the table stands tight to the parchment.

Top and legs polished dark, as the photo; apron and drawer in the room's burl. Finish to confirm with the bed's.

A S T U D Y I N T E A K

Particulars of the room

THE SIDE TABLES

Front · Side · Plan · Top edge · Knob

SCALE
AS NOTED @ A3

DATE
07.10.2026

REV

1 — after the owner's photo: shaped top, burl drawer, cabriole legs; no stone

DWG
AST-DR-049

PROJECT

## A Study in Teak — The Side Tables

SHEET

## General arrangement — the whole sheet

each view follows at its own scale, pages 2 to 7

SCALE

## NTS

DATE
07.10.2026

REV

DRAWING

## AST-DR-049 · 1 of 7

ALL DIMENSIONS IN FEET & INCHES. PRINT ON A3 AT 100% / “ACTUAL SIZE” — NOT “FIT TO PAGE” — AND CHECK THE SCALE BAR. DO NOT SCALE; WORK TO FIGURED DIMENSIONS. VERIFY ON SITE.

## FRONT

10½" DRAWER; 1'-4" TOP; 2'-0" HIGH; SCROLL TOE; Front

SCALE 1:4 (3" = 1'-0") @ A3 · AS THE OWNER'S PHOTO

SHAPED TOP, MOULDED EDG
WOOD, POLISHED DARK — NO STO

CARVED CONSOLE, EACH CO
ROUNDEL, REEDED STEM, VOLUT

ONE DRAWER, BURL FRONT
COCK-BEADED · SOFT-CLOSE RUN

BRASS ROSETTE KNOB
DETAIL 3

CABRIOLE LEG
SOLID, A BEAD DOWN ITS FRONT E

AST-DR-049 · 2 of 7

Front · Side · Plan · Top edge · Knob

## SIDE

11⅞" APRON; 1'-2" TOP; Side

SCALE 1:4 (3" = 1'-0") @ A3 · THE WALL ON THE LEFT

AST-DR-049 · 3 of 7

# PLAN

4" TO THE DIP; 4" TO THE FULL CENTRE; Plan

SCALE 1:3 (4" = 1'-0") @ A3 · THE WALL AT THE TOP · APRON AND LEGS DASHED

TOP — WOOD, NO STONE

AST-DR-049 · 4 of 7

### 2 · TOP EDGE

2 · top edge

SCALE 1:1 (FULL SIZE) @ A3 · SECTION

THUMBNAIL MOUL
AND A FILLET UNDER

THE TOP, SOLID
⅞ IN, POLISHED DARK

WOODEN BUTTON
LETS THE TOP MOVE

THE APRON SIDE
BURL OUTSIDE

AST-DR-049 · 5 of 7

# NOTES

# REVISION 1

After the owner's photo (7 Oct): a shaped serpentine top with a moulded edge and eared front corners — wood, no

stone (owner); a deep apron with one drawer, its front in burl, a brass rosette knob in the middle; a carved console

at each corner; tall slim cabriole legs with a bead down the front edge, ending in a scroll toe. Two the same.

⅝" × ½" in and 1" in high — the photo's table is taller; its proportions are kept, the height is set by the bed

(3 in above the mattress). The back legs turn their knees sideways only, so the table stands tight to the parchment.

Top and legs polished dark, as the photo; apron and drawer in the room's burl. Finish to confirm with the bed's.

## Notes

## NTS

## AST-DR-049 · 6 of 7

### 3 · KNOB

1⅛" BACKPLATE, ⅝" KNOB; 3 · knob

SCALE 1:1 (FULL SIZE) @ A3 · FACE AND SECTION

BRASS, CAST ROSETTE

BOLTED THROUGH THE DR

AST-DR-049 · 7 of 7

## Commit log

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2026-09-16 Study wall rev 4: right pilaster tight beside the window, no filler strip
    [desk-3d-sheet.dxf, desk-details-model.dxf, desk-details-sheet.dxf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]
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2026-09-17 Redesign after Ciridae: void canvas, condensed type, ghost pills, decode motion; drawings light/dark toggle (dark default)
    [desk-3d-sheet.dxf, desk-details-model.dxf, desk-details-sheet.dxf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]
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2026-09-17 Fix reference photos hidden in scrolled galleries: reveal the strip, not each photo
    [desk-3d-sheet.dxf, desk-details-model.dxf, desk-details-sheet.dxf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]
2026-09-17 Design loop round 3 fixes: chapter stack, type scale, focus rings, plan treatment, room strips
    [desk-3d-sheet.dxf, desk-details-model.dxf, desk-details-sheet.dxf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]
2026-09-17 Design loop round 4 fixes: nav over light, index heading, hints, captions, materials strip
    [desk-3d-sheet.dxf, desk-details-model.dxf, desk-details-sheet.dxf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]
2026-09-17 Loader: skip before first paint on repeat visits, time first visit from page start
    [desk-3d-sheet.dxf, desk-details-model.dxf, desk-details-sheet.dxf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]
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2026-09-17 Revert "Bedroom: partition card — sizes, your wood-to-frosted-to-clear idea, six directions with reference photos"
    This reverts commit 0a8d618c4e664e3f2c1067b9994c4194a84ce729.
    [desk-3d-sheet.dxf, desk-details-model.dxf, desk-details-sheet.dxf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]
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2026-09-17 Right wall rev 5: 4 in white marble skirting (laid), short panels reset above it
    [desk-3d-sheet.dxf, desk-details-model.dxf, desk-details-sheet.dxf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]
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2026-09-17 Right wall: door corrected to dressing (not bathroom); drop duplicate yard floor photo; tall panel top set exactly to the door head (2438)
    [desk-3d-sheet.dxf, desk-details-model.dxf, desk-details-sheet.dxf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]
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2026-09-18 Datum moved to 2 ft 3 in (686), set by the measured window sill
    The window is 4 ft x 5 ft 5 in, sill 2 ft 3 in off the floor, hard into
    the right-hand corner. The counter/rail line now lands on the sill
    instead of missing it by 3 inches, so the two are one surface.
    Study wall rev 6: cupboard carcase 570 to 646, counter top 610 to 686,
    window redrawn at its measured size and position with the architrave
    only on its left side.
    Right wall rev 8: rail band 646-686, short panels 212-546, tall panels
    796-2438 (still level with the door head).
    Curtains: single curtain gathering left only — the corner leaves no
    stack space on the right.
    [desk-3d-sheet.dxf, desk-details-model.dxf, desk-details-sheet.dxf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]
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2026-09-18 The room as built: shell plan, AST-DR-001
    Drawn from the site measurements rather than photographed from a sketch.
    Shell only, no furniture: the four walls at their real widths, the splay
    carried entirely by the left wall, the five-inch step past the entrance
    door, the window hard into the study wall corner, and the dressing door
    set out along the right wall.
    Everything uncertain is marked TO CONFIRM on the sheet — the step
    position, the entrance position, the partition line.
    Replaces the sketch photo on the Problems tab. DXF and SVG exports build
    alongside the other sheets.
    [desk-3d-sheet.dxf, desk-details-model.dxf, desk-details-sheet.dxf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]
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2026-09-18 Feet and inches everywhere, including the CAD files
    The DXF exports are now issued in inches, not millimetres: geometry is
    written at 1 unit = 1 inch, the header declares imperial units with
    architectural feet-and-fractional-inch formatting, and the dimension
    text carried through is the feet-inches label rather than the mm one.
    The web toggle now defaults to Ft·In as well. Millimetres are still one
    click away for anyone who wants them.
    Chain labels that spelled the units out by hand have been trimmed, since
    the toggle supplies them.
    [desk-3d-sheet.dxf, desk-details-model.dxf, desk-details-sheet.dxf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]
2026-09-18 Sill confirmed at 2 ft 3 in — the datum is fixed
    Measured floor to the underside of the window frame: 2 ft 3 in, which
    is exactly the 686 both drawings were already built on. Nothing had to
    be redrawn; the PROVISIONAL notes come off the study wall and right
    wall sheets.
    The counter top and the sill are one surface, and that line carries
    round to the right wall rail unbroken.
    The wall above the window works out at about 1 ft 5 in rather than the
    15 in first paced — two inches of ordinary slack.
    Problems: the sill entry moves from blocking to solved.
    [desk-3d-sheet.dxf, desk-details-model.dxf, desk-details-sheet.dxf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]
2026-09-18 Labels: a proper leader system instead of hand-placed notes
    Leaders were positioned by hand on every sheet, so they crossed each
    other and ran off the paper. They are now collected into gutter columns:
    each label keeps the height it wants where it can, and where two would
    overlap they are pushed apart in order, inside the band. The leader is
    drawn as an elbow with a horizontal landing into the text, so it reads
    as one line rather than a diagonal across the drawing.
    Applied to the room shell, study wall and right wall — the sheets with
    the worst collisions.
    Dimension chains got the same treatment: a label too long for its own
    segment now steps outward on a dotted extension, alternating so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
    [desk-3d-sheet.dxf, desk-details-model.dxf, desk-details-sheet.dxf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]
2026-09-18 Nothing runs off the page, and the build now checks it
    Detail 6 on the study wall details sheet — the band panel and sconce —
    was drawn at 1:20 in a slot 5 mm too short for it, so it ran through the
    bottom border. Redrawn at 1:25.
    Added a frame check to the CAD build: every sheet is scanned for
    geometry or text whose bounds fall outside the printed border, taking
    clip paths into account, and any sheet that overflows is reported by
    name and position. All eight sheets are clean in both millimetres and
    feet-and-inches.
    [desk-3d-sheet.dxf, desk-details-model.dxf, desk-details-sheet.dxf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]
2026-09-18 Audit: the door sheet was never on the shared drawing kit
    The toggle worked everywhere except the doors, and the reason was that
    door.js still carried its own private copy of the drafting helpers from
    before the kit existed — its own text, view, chainH, chainV, note,
    heading, frame, title block and svg wrapper. Every improvement made to
    the kit since then had simply never reached it.
    Migrated it onto window.DK, so it now gets the dimension toggle, the
    dual mm / feet-inches labels, the imperial default, the label stacks and
    the shared title block. It renders 14 dimension groups where it had none
    the toggle could see.
    Also from the audit:
    - roomshell was issued AST-DR-000; it had been give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
    [desk-3d-sheet.dxf, desk-details-model.dxf, desk-details-sheet.dxf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]
2026-09-18 Two door sheets, and the measured 7 ft 7 in height
    You were right that one drawing cannot cover both widths. The stiles,
    rails and mouldings are constant, so the extra width goes entirely into
    the panels — 562 wide on D2 and D3 against 257 on a D1 leaf. The
    elevations cannot be shared; the details can.
    door.js is now a parametric model run twice: AST-DR-001 for D1 at 3 ft
    and AST-DR-009 for D2 and D3 at 2 ft 6 in. The detail scales pick
    themselves from the leaf width so the wider door's details still clear
    the key column.
    Leaf height corrected from an assumed 8 ft to the measured 7 ft 7 in
    (2311). The rails were rebalanced so the bottom rail stays the deepest
    and the knob centre now land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
    [desk-3d-sheet.dxf, desk-details-model.dxf, desk-details-sheet.dxf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]
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2026-09-18 The partition in leaded glass — drawing and 3D, on its card
    AST-DR-010. One composition across the whole wall rather than a panel
    repeated: an outer rectangle 150 in from every edge and an inner one
    420 at the sides and 460 at head and foot, joined by a short bar at the
    middle of each side, with a cross at each corner of the inner rectangle.
    The border runs straight through the bay joints.
    Inside it each of the five bays carries the tiered head and foot, a stem
    into the clear field and three crosses down each margin — after the Art
    Glass Catalogue and the Prairie window. No colour.
    The sheet has plan, the elevation unrolled, the same wall with the 55 in
    set centred, the curve detail an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
    [desk-3d-sheet.dxf, desk-details-model.dxf, desk-details-sheet.dxf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]
2026-09-18 Partition glass rev 2: the border only, field left clear
    The last version laid the border over the full bay leading, so the two
    patterns fought each other across the whole panel. Wrong reading of the
    brief.
    Now all the leading lives in the ring between the two rectangles: short
    bars dividing it into panes, a second line running through it, a cross
    at each corner of the inner rectangle and at the middle of each side.
    Everything inside the inner rectangle is one clear sheet.
    The 3D follows automatically, since it slices the same elevation.
    [desk-3d-sheet.dxf, desk-details-model.dxf, desk-details-sheet.dxf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]
2026-09-18 Door casings, and the right wall follows them up to 8 ft 1 in
    AST-DR-011. The frame is 2 in on the face and the moulding adds 4 in
    outside it, so the casing is 6 in all round — not the 4 in assumed
    before — and its head sits at 8 ft 1 in.
    Depth comes from four small steps rather than one big member, standing
    only 30 off the wall. No crown: the reference doorway carries a full
    entablature and there is only 4 in to play with.
    Corner blocks and plinth blocks at every door, so the head and jamb die
    into a block instead of being mitred, and the architrave meets the
    marble skirting square instead of scribing over it. Only the dressing
    door is carved — chevrons and a sunk panel — so the t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
    [architrave-model.dxf, architrave-sheet.dxf, desk-3d-sheet.dxf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]
2026-09-18 The brownstone doorway recreated
    The casing head is no longer a flat board. Reading up from the opening
    it is now an ovolo, a fillet, a course of scallops, a plain frieze
    carried on two carved corbels, a bed mould, and a crown that mitres
    back at each end rather than dying into the wall — the reference as
    closely as it can be drawn.
    The corbels are the piece that was missing: a palmette cap, a long
    panel of chevrons inside a raised border, and an interlaced knot at
    the foot. Only the dressing door is carved; the main and bathroom
    doors take the identical head with panelled corbels, so the three
    read as one family.
    The jambs are reeded rather than fluted, with a roundel block at
    3 ft 1 in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
    [architrave-model.dxf, architrave-sheet.dxf, desk-3d-sheet.dxf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]
2026-09-18 Corbels out, and the casing stacked the right way up
    You were right that the frame and the moulding were colliding. They
    were: the moulding head was starting at the top of the leaf, in the
    same place as the lining, instead of above it. Now the lining comes
    first — 2 in — and the moulding stacks clear of it — 4 in — so the
    moulding head sits 6 in above the leaf rather than on top of it.
    That clearance is the whole of the correction.
    The corbels are gone, along with the carving, the roundel blocks and
    the frieze. What is left is what you asked for: the scallops, two
    small mouldings, and the crown. All three doors take the identical
    casing and only the width changes.
    The real door now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
    [architrave-model.dxf, architrave-sheet.dxf, desk-3d-sheet.dxf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]
2026-09-18 A plain square block where the head meets each jamb
    The criss-cross was the two sets of reeding running through each
    other: the jamb reeds go up, the head reeds go across, and in the
    corner they crossed into a grid.
    Now the head reeding stops short of each end and the jamb reeding
    stops under it, leaving that 4 in square plain — a corner block.
    The reeds never meet. It carries through to the right wall and the
    3D, which both build the casing from this sheet.
    [architrave-model.dxf, architrave-sheet.dxf, desk-3d-sheet.dxf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]
2026-09-18 The head stepped, not reeded, and the corner blocks moulded
    Three things from the photograph, checked at 6x rather than guessed:
    The head has no reeding. What reads as horizontal lines there is
    the edges of the stacked fillets — moulding steps. So the head is
    now two steps in the 4 in band, not eight reeds. The jambs keep
    their reeding, which the photograph does show.
    The corner squares now have a small sunk moulding worked inside
    them — two steps in from the face — instead of being flat.
    The scallops are set out in three runs, so a joint lands exactly on
    each block edge instead of the course running through at an
    arbitrary phase. That is what was reading as out of alignment.
    Co-Au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
    [architrave-model.dxf, architrave-sheet.dxf, desk-3d-sheet.dxf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]
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2026-09-18 The rail deleted; two panels set by the door, not the shelf
    The dado rail is gone from the right wall. It was doing two jobs
    badly — dividing the wall, and trying to carry the study counter
    round the corner — and it was losing at both. 2 ft 3 in is a worktop
    height, not a rail height, which is why the lower panels looked
    squashed and why the line had nowhere sensible to meet the door.
    What replaces it is nothing. The wall still has two panels per bay,
    but the gap between them is the DOOR'S OWN LOCK RAIL carried across
    as plain wall, so the band runs unbroken from the corner, through
    the door, and out the other side. No moulding, so nothing has to die
    into the casing and nothing clashes.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
    [architrave-model.dxf, architrave-sheet.dxf, casingb-model.dxf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]
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2026-09-19 Lightbox: pinch, drag and double-tap zoom on the drawing itself
    On a phone the lightbox only zoomed through its − and + buttons, so a
    pinch zoomed the whole page instead: the Close button slid off-screen
    and the site stayed zoomed after closing, needing a pinch back out.
    The drawing now zooms and pans inside the lightbox — pinch, drag,
    double-tap, mouse wheel, trackpad pinch, or the buttons — and the page
    underneath is locked while it is open, so the browser never zooms the
    site. Fit resets; Close and Escape clear everything.
    [architrave-model.dxf, architrave-sheet.dxf, casingb-model.dxf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]
2026-09-19 Bed, curled bed back and partition, set out together — AST-DR-013
    The bed back takes the partition's shape to the bed wall: a straight run
    behind the bed and a tight curl at each end turning 2 ft forward, with a
    bedside ledge inside each curl. Both pieces are 8 ft and both are moved
    6 in to the right, so each sits 2 ft 11 in off the right wall — the
    straight one — and they stand on exactly the same two lines.
    The sheet has the plan with the alignment and every gap in feet and
    inches, the bed back from the foot of the bed, and four views drawn in
    3D with hidden lines removed: from the door, from the bed looking at the
    TV, from the partition looking at the bed, and from the study.
    Flag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
    [architrave-model.dxf, architrave-sheet.dxf, bed-model.dxf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]
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2026-09-23 The left wall, and the room 3D with what stands in it
    LEFT WALL — AST-DR-014. The plain one: paint, the marble skirting, one
    painting and the air conditioner over it. Elevation, plan and notes.
    The painting is centred on the 15 ft 1 in of wall before the step, the
    only uninterrupted run, and the entrance takes the last 3 ft. Both the
    painting and the unit are drawn at assumed sizes, flagged in red on the
    sheet, so the real ones are a one-line change.
    OVERVIEW 3D — it was four walls and a floor. It now has:
    · the left wall's own elevation, flipped, since that plane runs from
    the bed end back to the study end
    · the partition, built as faceted panels following its curve, left
    as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
    [architrave-model.dxf, architrave-sheet.dxf, bed-model.dxf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]
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2026-09-23 The door design restored, and the new measurements taken in
    DOOR. You were right and I was wrong: only the construction had to
    change, not the design. AST-DR-015 no longer redraws the door. Both
    elevations are now generated from the door sheets' own code, so the
    shaped bead, its concave shoulders and rounded crown, the four
    roundels and the knob all land exactly where AST-DR-001 and -009 put
    them — and if the design ever changes there, this sheet follows.
    What the sheet now says is only how each member is made:
    panel field was sunk 13.5 -> stays flat, the ovolo does the work
    ovolo worked on the stile -> run separately, mitred on
    shaped bead carved into the face -> ban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
    [architrave-model.dxf, architrave-sheet.dxf, bed-model.dxf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]
2026-09-23 Partition at 8 ft from the study wall, and two bugs out of the 3D
    The 11 ft is from the BED wall, so the partition line sits 8 ft from
    the study wall. Everything now closes:
    study side, behind the partition 8 ft 0 in
    walkway at the foot of the bed 3 ft 9 in (you said "around 4")
    study side broken down 11 in cupboards, 2 ft 11 in for
    the chair, 2 ft 8 in desk, 1 ft 6 in
    to the partition
    Taking the partition from 2 3/8 in to your 6 in maximum costs under
    two inches at the foot of the bed — 3 ft 9 in becomes 3 ft 7 in. So
    thickness is not the constraint; decide it on how the leading and the
    f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
    [architrave-model.dxf, architrave-sheet.dxf, bed-model.dxf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]
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2026-09-23 Dimension the bed to both walls, splay and all
    Asked for the bed's clearance to each side wall. Two figures were stale on
    AST-DR-013 — it still said "bed 6 ft 6 in" after the bed went to 6 ft, and it
    still carried the OPEN warning that the partition at 11 ft left no room, which
    was resolved when the 11 ft turned out to be measured from the BED wall.
    The right wall is the straight one, so that figure holds the whole length of
    the bed: 3 ft 11 in. The left wall carries both the splay and the 5 in step, so
    the gap there opens out along the bed — 5 ft 1 5/8 in at the foot, 5 ft 2 in at
    the step, 5 ft 7 in at the head. The plan's bed chain now measures at the foot,
    the narrowest point, and t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
    [architrave-model.dxf, architrave-sheet.dxf, bed-model.dxf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]
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2026-09-23 Vanity: the drawer within; site audit fixes
    The big vanity drawer now hides a second, shallower drawer at the top of its
    opening (new sheet AST-DR-022). The inner drawer runs on its own runners fixed
    to the carcass, not to the big drawer: open the big one and the inner stays
    put; pull it and it slides out behind the big front, over the bottles, as far
    as that solid front allows. The big drawer's sides stop at 430 so the inner
    one passes above them. Both are U-boxes round the trap; in the normal version
    the off-centre pipe leaves the inner drawer a 25 mm arm, so there it is an L.
    All three vanity sheets show it — dashed on the front, cut in the section,
    nested in the drawer plan, and as row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
    [architrave-model.dxf, architrave-sheet.dxf, bed-model.dxf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]
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2026-10-02 Vanity C: one mitred marble corner, fronts flush; large-print PDFs reworked
    Vanity scheme C (owner's sketch, 2 Oct): the top and the front now meet in a
    single 45° mitre, with no lip and no step. The top mitres into a fixed 18 mm
    marble strip across the top of the bank, and the drawers start under it,
    push-to-open. Every front comes forward the 1 in the marble used to
    oversail, so the fronts are flush with the edge of the top (2 ft 1 in deep).
    Detail 1, the section, the front, the plan, the drawer-within sheet, the
    notes and the DXFs all follow.
    Large print: the cut-up "enlarged part" pages are gone (they read as random
    zoomed-in corners). Each sheet now prints whole first, then every view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
    [vanity-c-model.dxf, vanity-c-sheet.dxf, vanity-drawer-model.dxf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]
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2026-10-02 Plain desk rev 2: no corner mouldings, wider drawers, monitor clamp bay
    Owner, 2 Oct: the plain bead strips at the corners go too — just the square
    panel mouldings. Without them the outer stiles slim to a plain 1½ in, so
    the pedestal drawers widen from 1'-5⅛" to 1'-6¾".
    Monitor-arm provision: a clamp bay at the back centre, 10 in wide. The
    clamp bites 2–3 in in from the back edge, so the underside of the top is
    kept clear 4 in in and 3½ in down: the cove stops there, the frieze back
    rail and the modesty panel are set in to 4 in, and the centre frieze drawer
    is 1½ in shorter. The clamp's body sits in the 2 in gap to the glass, and
    the 1⅝ in top is inside common clamps' grip. Show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
    [desk-plain-3d-sheet.dxf, desk-plain-details-model.dxf, desk-plain-details-sheet.dxf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]
2026-10-03 Bed wall niche and the bed from the owner's photo: AST-DR-034 / 035
    From the owner's sketch and photo (3 Oct). AST-DR-034, the bed wall: the
    whole wall is built out in Dark Diva veneer (polished darker), 10 in proud
    either side of a niche that holds the bed and both side tables, easing
    through a rounded step down to 3 in at both corners. The niche is 10 in deep,
    lined with parchment plaster in a 5 × 3 grid. Elevation, plan, section A–A,
    and a detail of the entrance corner.
    Problems found and drawn: the entrance door's hinge pin is only 2 in off this
    wall, so the 3 in face stops it opening flat (projecting hinges, or 1½ in at
    that corner). The bed comes 4½ in further out (2 ft 5½ in le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
    [bedframe-model.dxf, bedframe-sheet.dxf, bedwall-model.dxf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]
2026-10-03 Bed wall rev 2: a concave 7 in cove round the niche, sides and top; niche lower
    The owner's second sketch: the step from 3 in to 10 in is a long concave cove
    out of the 3 in face — not the tight convex knob drawn before — and it runs
    across the top of the niche as well as up both sides. The rest of the wall,
    the band over the niche included, stays at 3 in. The cove is a 7 in radius
    quarter, tangent to the 3 in face, turning to run straight out at the niche,
    with a 1 in flat edge at 10 in; the side and top coves meet in a mitre at the
    two top corners. Niche lowered to 6 ft 6 in (owner: "a bit lower"), so the 5 × 3
    plaster panels come out nearly square. Plan, elevation, section and the
    en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
    [bedwall-model.dxf, bedwall-sheet.dxf]
2026-10-03 Bed wall rev 3: in the overview plan and 3D room; lamps over the tables
    The owner's answers (3 Oct): niche height 6 ft 6 in is good; the cove light
    stays in the ceiling and no other light goes on this wall except a brass
    twin-arm wall lamp over each side table, the right wall's lamp; headboard
    in dusty-rose suede; the bed-back wall's polish a bit darker.
    The niche keeps the old bed-back span exactly (9 ft 4 in), centred on the TV
    and partition line, and the cove tightens to 6 in radius + 1 in edge so it
    stops where the open door's leaf ends, which keeps the door's 3 ft clear.
    Side tables 16 in so they sit 1 in clear in the niche.
    The overview's 2D plan now draws the build-out, cove, niche,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
    [bedwall-model.dxf, bedwall-sheet.dxf]
2026-10-03 Bed wall in Blender; cove depth fixed in the drawings
    tools/walk/bedwall.py, run by the realism pass just before the bed is made:
    the bed wall's build-out as one height-field surface (3 in, the concave cove
    up both sides and across the top meeting in mitres at the corners, the 1 in
    flat edge at 10 in), the niche returns and soffit, in Dark Diva veneer
    polished darker than the room (owner). Marble skirting following it round
    the coves. The niche back in 5 × 3 parchment-plaster panels with dark
    hairline joints. The bed from the owner's photo: a teak platform in the
    room's tone with a lipped 4 in rail and five turned bun feet, the mattress
    (the cloth bedding is made on it), and the headboard i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
    [bedwall-model.dxf, bedwall-sheet.dxf]
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
